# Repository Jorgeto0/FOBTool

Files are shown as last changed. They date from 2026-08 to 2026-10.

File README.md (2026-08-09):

# FOBtool Hardware

FOBtool Hardware is the KiCad source repository for the FOBtool handheld electronic platform. It contains the project-level schematic and PCB files, custom symbols and footprints, and supporting documentation used to develop and maintain the hardware design.

## Project contents

| Path | Purpose |
| --- | --- |
| `FOBtool_HW.kicad_pro` | Main KiCad project file. Open this file to work with the design. |
| `FOBtool_HW.kicad_sch` | Top-level hierarchical schematic. |
| `POWER.kicad_sch` | Battery, charging, power-path, monitoring, and regulated-supply circuitry. |
| `MAIN_CONTROLLER_sch.kicad_sch` | ESP32-S3 main-controller circuitry and system control interfaces. |
| `FOBtool_HW.kicad_pcb` | PCB layout file. |
| `Custom_Components/` | Project-specific symbol and footprint resources. |
| `docs/` | Short descriptions of the project and schematic sheets. |

## Opening the design

1. Install [KiCad](https://www.kicad.org/) 10.x or a compatible later version.
2. Clone or download the complete repository so the project files and custom libraries remain together.
3. Open `FOBtool_HW.kicad_pro` from KiCad's Project Manager.
4. Confirm that the project symbol and footprint libraries load without errors before editing the design.

Open the project file rather than an individual child sheet so KiCad retains the full hierarchy and project library configuration.

## Schematic documentation

See the [documentation index](docs/README.md) for the purpose of each schematic sheet currently included in the project.

## Repository use

This repository contains active engineering source files. Design files may change as schematic capture, verification, PCB layout, and manufacturing preparation progress. Manufacturing outputs should be issued separately as a controlled release.

## Confidentiality

This project contains proprietary client hardware information. Keep the repository private and share its contents only with authorized project participants.

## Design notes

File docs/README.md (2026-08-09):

# Hardware Documentation

This directory provides a concise description of the purpose of each schematic sheet in the FOBtool Hardware project.

| Schematic sheet | Purpose |
| --- | --- |
| [Power](POWER.md) | Manages the battery and external power inputs, charging, power monitoring, and the regulated supply rails used by the system. |
| [Main Controller](MAIN_CONTROLLER.md) | Contains the ESP32-S3 main controller, its essential support circuitry, and the control and communication interfaces to the other hardware subsystems. |

The complete schematic hierarchy is opened through [`FOBtool_HW.kicad_pro`](../FOBtool_HW.kicad_pro).

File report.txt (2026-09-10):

Info: Processing symbol 'FL10:Filter:Filter_SAW_Epcos_DCC6C_3x3mm'.
Info: Processing symbol 'FL11:Filter:Filter_SAW_Epcos_DCC6C_3x3mm'.
Info: Processing symbol 'AE2:FOBtool_Custom:Antenna_Taoglas_UWA01_3.2x1.6mm'.
Info: Processing symbol 'FL12:Filter:Filter_SAW_Epcos_DCC6C_3x3mm'.
Info: Processing symbol 'BZ1:Buzzer_Beeper:Buzzer_Mallory_AST1109MLTRQ'.
Info: Processing symbol 'J1:Connector_JST:JST_PH_S3B-PH-SM4-TB_1x03-1MP_P2.00mm_Horizontal'.
Info: Processing symbol 'C2:Capacitor_SMD:C_1206_3216Metric'.
Info: Processing symbol 'J2:Connector_PinHeader_1.27mm:PinHeader_1x05_P1.27mm_Vertical'.
Info: Processing symbol 'C4:Capacitor_SMD:C_1206_3216Metric'.
Info: Processing symbol 'J3:Connector_Coaxial:SMA_Amphenol_132289_EdgeMount'.
Info: Processing symbol 'C6:Capacitor_SMD:C_0805_2012Metric'.
Info: Processing symbol 'J4:Connector_Coaxial:SMA_Amphenol_132289_EdgeMount'.
Info: Processing symbol 'C8:Capacitor_SMD:C_1210_3225Metric'.
Info: Processing symbol 'J5:Connector_Coaxial:SMA_Amphenol_132289_EdgeMount'.
Info: Processing symbol 'C10:Capacitor_SMD:C_1210_3225Metric'.
Info: Processing symbol 'J6:Connector_Coaxial:SMA_Amphenol_132289_EdgeMount'.
Info: Processing symbol 'C12:Capacitor_SMD:C_1206_3216Metric'.
Info: Processing symbol 'J7:USB4085:GCT_USB4085-GF-A_REVA4'.
Info: Processing symbol 'R43:Resistor_SMD:R_0603_1608Metric'.
Info: Processing symbol 'L19:Inductor_SMD:L_0402_1005Metric'.
Info: Processing symbol 'C207:Capacitor_SMD:C_0603_1608Metric'.
Info: Processing symbol 'R108:Resistor_SMD:R_0603_1608Metric'.
Info: Processing symbol 'Y9:CSCT:OSC_CSTCR4M00G55B-R0'.
Info: Processing symbol 'C174:Capacitor_SMD:C_0603_1608Metric'.
Info: Processing symbol 'R11:Resistor_SMD:R_0603_1608Metric'.
Info: Processing symbol 'C110:Capacitor_SMD:C_0402_1005Metric'.
Info: Processing symbol 'R76:Resistor_SMD:R_0603_1608Metric'.
Info: Processing symbol 'C239:Capacitor_SMD:C_0603_1608Metric'.
Info: Processing symbol 'R140:Resistor_SMD:R_0603_1608Metric'.
Info: Processing symbol 'U27:Package_TO_SOT_SMD:SOT-23-6'.
Info: Processing symbol 'C13:Capacitor_SMD:C_0603_1608Metric'.
Info: Processing symbol 'L3:Inductor_SMD:L_Wuerth_HCI-5040'.
Info: Processing symbol 'C94:Capacitor_SMD:C_0402_1005Metric'.
Info: Processing symbol 'L35:Inductor_SMD:L_0603_1608Metric'.
Info: Processing symbol 'C191:Capacitor_SMD:C_0402_1005Metric'.
Info: Processing symbol 'R27:Resistor_SMD:R_0603_1608Metric'.
Info: Processing symbol 'C62:Capacitor_SMD:C_0402_1005Metric'.
Info: Processing symbol 'R60:Resistor_SMD:R_0603_1608Metric'.
Info: Processing symbol 'C223:Capacitor_SMD:C_0603_1608Metric'.
Info: Processing symbol 'R92:Resistor_SMD:R_0603_1608Metric'.
Info: Processing symbol 'C126:Capacitor_SMD:C_0402_1005Metric'.
Info: Processing symbol 'R124:Resistor_SMD:R_0805_2012Metric'.
Info: Processing symbol 'C255:Capacitor_SMD:C_0603_1608Metric'.
Info: Processing symbol 'R156:Resistor_SMD:R_0603_1608Metric'.
Info: Processing symbol 'U10:Package_LGA:Infineon_PG-TSNP-6-10_0.7x1.1mm_0.7x1.1mm_P0.4mm'.
Info: Processing symbol 'FB6:Inductor_SMD:L_0402_1005Metric'.
Info: Processing symbol 'U43:Package_SO:SOIC-8_3.9x4.9mm_P1.27mm'.
Info: Processing symbol 'C158:Capacitor_SMD:C_0603_1608Metric'.
Info: Processing symbol 'J14:'.
Info: Processing symbol 'C166:Capacitor_SMD:C_0603_1608Metric'.
Info: Processing symbol 'L11:Inductor_SMD:L_0402_1005Metric'.
Info: Processing symbol 'C54:Capacitor_SMD:C_0402_1005Metric'.
Info: Processing symbol 'L27:Inductor_SMD:L_0603_1608Metric'.
Info: Processing symbol 'C183:Capacitor_SMD:C_0402_1005Metric'.
Info: Processing symbol 'R3:Resistor_SMD:R_0603_1608Metric'.
Info: Processing symbol 'C102:Capacitor_SMD:C_0805_2012Metric'.
Info: Processing symbol 'R19:Resistor_SMD:R_0603_1608Metric'.
Info: Processing symbol 'C199:Capacitor_SMD:C_0402_1005Metric'.
Info: Processing symbol 'R35:Resistor_SMD:R_0603_1608Metric'.
Info: Processing symbol 'C38:Capacitor_SMD:C_0402_1005Metric'.
Info: Processing symbol 'R51:Resistor_SMD:R_0805_2012Metric'.
Info: Processing symbol 'C215:Capacitor_SMD:C_0603_1608Metric'.
Info: Processing symbol 'R68:Resistor_SMD:R_0603_1608Metric'.
Info: Processing symbol 'C118:Capacitor_SMD:C_0402_1005Metric'.
Info: Processing symbol 'R84:Resistor_SMD:R_0603_1608Metric'.
Info: Processing symbol 'C231:Capacitor_SMD:C_0805_2012Metric'.
Info: Processing symbol 'R100:Resistor_SMD:R_0603_1608Metric'.
Info: Processing symbol 'C70:Capacitor_SMD:C_0402_1005Metric'.
Info: Processing symbol 'R116:Resistor_SMD:R_0603_1608Metric'.
Info: Processing symbol 'C247:Capacitor_SMD:C_0603_1608Metric'.
Info: Processing symbol 'R132:Resistor_SMD:R_0805_2012Metric'.
Info: Processing symbol 'C135:Capacitor_SMD:C_0402_1005Metric'.
Info: Processing symbol 'R148:Resistor_SMD:R_0603_1608Metric'.
Info: Processing symbol 'D1:Diode_SMD:Nexperia_DSN0603-2_0.6x0.3mm_P0.4mm'.
Info: Processing symbol 'SW6:Button_Switch_SMD:SW_SPST_PTS810'.
Info: Processing symbol 'U2:Package_DFN_QFN:QFN-60-1EP_7x7mm_P0.4mm_EP3.4x3.4mm'.
Info: Processing symbol 'D17:Diode_SMD:Nexperia_DSN0603-2_0.6x0.3mm_P0.4mm'.
Info: Processing symbol 'U18:FOBtool_Custom:Infineon_PG-TSNP-8-1_1.1x1.1mm_P0.4mm'.
Info: Processing symbol 'C150:Capacitor_SMD:C_0603_1608Metric'.
Info: Processing symbol 'U35:Package_DFN_QFN:QFN-40-1EP_5x5mm_P0.4mm_EP3.6x3.6mm'.
Info: Processing symbol 'AE1:FOBtool_Custom:Antenna_Taoglas_UWA01_3.2x1.6mm'.
Info: Processing symbol 'Y1:Crystal:Crystal_SMD_3225-4Pin_3.2x2.5mm'.
Info: Processing symbol 'C86:Capacitor_SMD:C_0402_1005Metric'.
Info: Processing symbol 'J10:Connector_FFC-FPC:Hirose_FH12-12S-0.5SH_1x12-1MP_P0.50mm_Horizontal'.
Info: Processing symbol 'C88:Capacitor_SMD:C_0402_1005Metric'.
Info: Processing symbol 'J17:Connector_Coaxial:SMA_Amphenol_132289_EdgeMount'.
Info: Processing symbol 'C90:Capacitor_SMD:C_0402_1005Metric'.
Info: Processing symbol 'L7:Inductor_SMD:L_0402_1005Metric'.
Info: Processing symbol 'C170:Capacitor_SMD:C_0805_2012Metric'.
Info: Processing symbol 'L15:Inductor_SMD:L_0402_1005Metric'.
Info: Processing symbol 'C34:Capacitor_SMD:C_0402_1005Metric'.
Info: Processing symbol 'L23:Inductor_SMD:L_0402_1005Metric'.
Info: Processing symbol 'C179:FOBtool_Custom:CP_Seiko_CPH3225A_3.2x2.5mm'.
Info: Processing symbol 'L31:Inductor_SMD:L_0603_1608Metric'.
Info: Processing symbol 'C98:Capacitor_SMD:C_0402_1005Metric'.
Info: Processing symbol 'Q2:Package_TO_SOT_SMD:SOT-23'.
Info: Processing symbol 'C187:Capacitor_SMD:C_0402_1005Metric'.
Info: Processing symbol 'R7:Resistor_SMD:R_0603_1608Metric'.
Info: Processing symbol 'C58:Capacitor_SMD:C_0603_1608Metric'.
Info: Processing symbol 'R15:Resistor_SMD:R_0603_1608Metric'.
Info: Processing symbol 'C195:Capacitor_SMD:C_0402_1005Metric'.
Info: Processing symbol 'R23:Resistor_SMD:R_0603_1608Metric'.
Info: Processing symbol 'C106:Capacitor_SMD:C_0402_1005Metric'.
Info: Processing symbol 'R31:Resistor_SMD:R_0603_1608Metric'.
Info: Processing symbol 'C203:Capacitor_SMD:C_0402_1005Metric'.
Info: Processing symbol 'R39:Resistor_SMD:R_0603_1608Metric'.
Info: Processing symbol 'C26:Capacitor_SMD:C_0603_1608Metric'.
Info: Processing symbol 'R47:Resistor_SMD:R_0402_1005Metric'.
Info: Processing symbol 'C211:Capacitor_SMD:C_1206_3216Metric'.
Info: Processing symbol 'R56:Resistor_SMD:R_0603_1608Metric'.
Info: Processing symbol 'C114:Capacitor_SMD:C_0402_1005Metric'.
Info: Processing symbol 'R64:Resistor_SMD:R_0603_1608Metric'.
Info: Processing symbol 'C219:Capacitor_SMD:C_0603_1608Metric'.
Info: Processing symbol 'R72:Resistor_SMD:R_0603_1608Metric'.
Info: Processing symbol 'C66:Capacitor_SMD:C_0402_1005Metric'.
Info: Processing symbol 'R80:Resistor_SMD:R_0603_1608Metric'.
Info: Processing symbol 'C227:Capacitor_SMD:C_0603_1608Metric'.
Info: Processing symbol 'R88:Resistor_SMD:R_0603_1608Metric'.
Info: Processing symbol 'C122:Capacitor_SMD:C_0402_1005Metric'.
Info: Processing symbol 'R96:Resistor_SMD:R_0603_1608Metric'.
Info: Processing symbol 'C235:Capacitor_SMD:C_0603_1608Metric'.
Info: Processing symbol 'R104:Resistor_SMD:R_0603_1608Metric'.
Info: Processing symbol 'C42:Capacitor_SMD:C_0402_1005Metric'.
Info: Processing symbol 'R112:Resistor_SMD:R_0603_1608Metric'.
Info: Processing symbol 'C243:Capacitor_SMD:C_0603_1608Metric'.
Info: Processing symbol 'R120:Resistor_SMD:R_0603_1608Metric'.
Info: Processing symbol 'C130:Capacitor_SMD:C_0402_1005Metric'.
Info: Processing symbol 'R128:Resistor_SMD:R_0603_1608Metric'.
Info: Processing symbol 'C251:Capacitor_SMD:C_0603_1608Metric'.
Info: Processing symbol 'R136:Resistor_SMD:R_0805_2012Metric'.
Info: Processing symbol 'C74:Capacitor_SMD:C_0402_1005Metric'.
Info: Processing symbol 'R144:Resistor_SMD:R_0603_1608Metric'.
Info: Processing symbol 'C259:Capacitor_SMD:C_0603_1608Metric'.
Info: Processing symbol 'R152:Resistor_SMD:R_0603_1608Metric'.
Info: Processing symbol 'C139:Capacitor_SMD:C_0402_1005Metric'.
Info: Processing symbol 'SW2:Button_Switch_SMD:SW_SPST_PTS810'.
Info: Processing symbol 'D5:Package_SON:Texas_DPY0002A_0.6x1mm_P0.65mm'.
Info: Processing symbol 'T2:BO310:XFMR_B0310J50100AHF'.
Info: Processing symbol 'TP7:TestPoint:TestPoint_Pad_D1.5mm'.
Info: Processing symbol 'D13:LED_SMD:LED_0603_1608Metric'.
Info: Processing symbol 'U6:Package_DFN_QFN:QFN-20-1EP_4x4mm_P0.5mm_EP2.6x2.6mm_ThermalVias'.
Info: Processing symbol 'C146:Capacitor_SMD:C_0402_1005Metric'.
Info: Processing symbol 'U14:TQP3M:SON50P200X200X95-9N'.
Info: Processing symbol 'FB2:Inductor_SMD:L_0402_1005Metric'.
Info: Processing symbol 'U22:TQP7M:QFN50P400X400X90-25N'.
Info: Processing symbol 'C82:Capacitor_SMD:C_0402_1005Metric'.
Info: Processing symbol 'U31:Package_LGA:Infineon_PG-TSNP-6-10_0.7x1.1mm_0.7x1.1mm_P0.4mm'.
Info: Processing symbol 'FL4:Filter:Filter_SAW_Epcos_DCC6C_3x3mm'.
Info: Processing symbol 'U39:Package_SO:TSSOP-16_4.4x5mm_P0.65mm'.
Info: Processing symbol 'C154:Capacitor_SMD:C_0603_1608Metric'.
Info: Processing symbol 'U47:SN74:SOP65P640X120-14N'.
Info: Processing symbol 'C5:Capacitor_SMD:C_1206_3216Metric'.
Info: Processing symbol 'Y5:Crystal:Crystal_SMD_3215-2Pin_3.2x1.5mm'.
Info: Processing symbol 'C50:Capacitor_SMD:C_0402_1005Metric'.
Info: Processing symbol 'J8:Connector_USB:USB_A_Molex_67643_Horizontal'.
Info: Processing symbol 'C160:Capacitor_SMD:C_0603_1608Metric'.
Info: Processing symbol 'J12:Connector_Card:microSD_HC_Molex_104031-0811'.
Info: Processing symbol 'C51:Capacitor_SMD:C_0402_1005Metric'.
Info: Processing symbol 'J15:Connector_JST:JST_PH_S2B-PH-SM4-TB_1x02-1MP_P2.00mm_Horizontal'.
Info: Processing symbol 'C164:Capacitor_SMD:C_0603_1608Metric'.
Info: Processing symbol 'L1:Inductor_SMD:L_Wuerth_MAPI-4020'.
Info: Processing symbol 'C52:Capacitor_SMD:C_0402_1005Metric'.
Info: Processing symbol 'L5:Inductor_SMD:L_0402_1005Metric'.
Info: Processing symbol 'C168:Capacitor_SMD:C_0603_1608Metric'.
Info: Processing symbol 'L9:Inductor_SMD:L_0402_1005Metric'.
Info: Processing symbol 'C92:Capacitor_SMD:C_0402_1005Metric'.
Info: Processing symbol 'L13:Inductor_SMD:L_0402_1005Metric'.
Info: Processing symbol 'C172:Capacitor_SMD:C_0805_2012Metric'.
Info: Processing symbol 'L17:Inductor_SMD:L_0402_1005Metric'.
Info: Processing symbol 'C24:Capacitor_SMD:C_1206_3216Metric'.
Info: Processing symbol 'L21:FOBtool_Custom:L_Murata_LQH44PN_4.0x4.0mm'.
Info: Processing symbol 'C177:Capacitor_SMD:C_0603_1608Metric'.
Info: Processing symbol 'L25:Inductor_SMD:L_0603_1608Metric'.
Info: Processing symbol 'C96:Capacitor_SMD:C_0402_1005Metric'.
Info: Processing symbol 'L29:Inductor_SMD:L_0603_1608Metric'.
Info: Processing symbol 'C181:Capacitor_SMD:C_0603_1608Metric'.
Info: Processing symbol 'L33:Inductor_SMD:L_0402_1005Metric'.
Info: Processing symbol 'C56:Capacitor_SMD:C_0402_1005Metric'.
Info: Processing symbol 'NT1:FOBtool_Custom:NetTie_2_SMD_3.0mm_Current'.
Info: Processing symbol 'C185:Capacitor_SMD:C_0402_1005Metric'.
Info: Processing symbol 'R1:Resistor_SMD:R_0603_1608Metric'.
Info: Processing symbol 'C100:Capacitor_SMD:C_0603_1608Metric'.
Info: Processing symbol 'R5:Resistor_SMD:R_0603_1608Metric'.
Info: Processing symbol 'C189:Capacitor_SMD:C_0805_2012Metric'.
Info: Processing symbol 'R9:Resistor_SMD:R_0603_1608Metric'.
Info: Processing symbol 'C36:Capacitor_SMD:C_0402_1005Metric'.
Info: Processing symbol 'R13:Resistor_SMD:R_0603_1608Metric'.
Info: Processing symbol 'C193:Capacitor_SMD:C_1206_3216Metric'.
Info: Processing symbol 'R17:Resistor_SMD:R_0603_1608Metric'.
Info: Processing symbol 'C104:Capacitor_SMD:C_0402_1005Metric'.
Info: Processing symbol 'R21:Resistor_SMD:R_0603_1608Metric'.
Info: Processing symbol 'C197:Capacitor_SMD:C_0402_1005Metric'.
Info: Processing symbol 'R25:Resistor_SMD:R_0603_1608Metric'.
Info: Processing symbol 'C60:FOBtool_Custom:CP_Panasonic_EEF-LR_7.3x4.3mm_3Terminal'.
Info: Processing symbol 'R29:Resistor_SMD:R_0603_1608Metric'.
Info: Processing symbol 'C201:Capacitor_SMD:C_0402_1005Metric'.
Info: Processing symbol 'R33:Resistor_SMD:R_0603_1608Metric'.
Info: Processing symbol 'C108:Capacitor_SMD:C_0402_1005Metric'.
Info: Processing symbol 'R37:Resistor_SMD:R_0603_1608Metric'.
Info: Processing symbol 'C205:Capacitor_SMD:C_0603_1608Metric'.
Info: Processing symbol 'R41:Resistor_SMD:R_0603_1608Metric'.
Info: Processing symbol 'C20:Capacitor_SMD:C_1206_3216Metric'.
Info: Processing symbol 'R45:Resistor_SMD:R_0603_1608Metric'.
Info: Processing symbol 'C209:Capacitor_SMD:C_0603_1608Metric'.
Info: Processing symbol 'R49:Resistor_SMD:R_0603_1608Metric'.
Info: Processing symbol 'C112:Capacitor_SMD:C_0402_1005Metric'.
Info: Processing symbol 'R54:Resistor_SMD:R_0603_1608Metric'.
Info: Processing symbol 'C213:Capacitor_SMD:C_0603_1608Metric'.
Info: Processing symbol 'R58:Resistor_SMD:R_0603_1608Metric'.
Info: Processing symbol 'C64:Capacitor_SMD:C_0402_1005Metric'.
Info: Processing symbol 'R62:Resistor_SMD:R_0603_1608Metric'.
Info: Processing symbol 'C217:Capacitor_SMD:C_0603_1608Metric'.
Info: Processing symbol 'R66:Resistor_SMD:R_0603_1608Metric'.
Info: Processing symbol 'C116:Capacitor_SMD:C_0402_1005Metric'.
Info: Processing symbol 'R70:Resistor_SMD:R_0603_1608Metric'.
Info: Processing symbol 'C221:Capacitor_SMD:C_1206_3216Metric'.
Info: Processing symbol 'R74:Resistor_SMD:R_0603_1608Metric'.
Info: Processing symbol 'C40:Capacitor_SMD:C_0805_2012Metric'.
Info: Processing symbol 'R78:Resistor_SMD:R_0603_1608Metric'.
Info: Processing symbol 'C225:Capacitor_SMD:C_0603_1608Metric'.
Info: Processing symbol 'R82:Resistor_SMD:R_0603_1608Metric'.
Info: Processing symbol 'C120:Capacitor_SMD:C_0402_1005Metric'.
Info: Processing symbol 'R86:Resistor_SMD:R_0603_1608Metric'.
Info: Processing symbol 'C229:Capacitor_SMD:C_0603_1608Metric'.
Info: Processing symbol 'R90:Resistor_SMD:R_0603_1608Metric'.
Info: Processing symbol 'C68:Capacitor_SMD:C_0402_1005Metric'.
Info: Processing symbol 'R94:Resistor_SMD:R_0603_1608Metric'.
Info: Processing symbol 'C233:Capacitor_SMD:C_0603_1608Metric'.
Info: Processing symbol 'R98:Resistor_SMD:R_0603_1608Metric'.
Info: Processing symbol 'C124:Capacitor_SMD:C_0603_1608Metric'.
Info: Processing symbol 'R102:Resistor_SMD:R_0603_1608Metric'.
Info: Processing symbol 'C237:Capacitor_SMD:C_0603_1608Metric'.
Info: Processing symbol 'R106:Resistor_SMD:R_0603_1608Metric'.
Info: Processing symbol 'C28:Capacitor_SMD:C_0402_1005Metric'.
Info: Processing symbol 'R110:Resistor_SMD:R_0603_1608Metric'.
Info: Processing symbol 'C241:Capacitor_SMD:C_0603_1608Metric'.
Info: Processing symbol 'R114:Resistor_SMD:R_0603_1608Metric'.
Info: Processing symbol 'C128:Capacitor_SMD:C_0402_1005Metric'.
Info: Processing symbol 'R118:Resistor_SMD:R_0603_1608Metric'.
Info: Processing symbol 'C245:Capacitor_SMD:C_0603_1608Metric'.
Info: Processing symbol 'R122:Resistor_SMD:R_0603_1608Metric'.
Info: Processing symbol 'C72:Capacitor_SMD:C_0402_1005Metric'.
Info: Processing symbol 'R126:Resistor_SMD:R_0603_1608Metric'.
Info: Processing symbol 'C249:Capacitor_SMD:C_0603_1608Metric'.
Info: Processing symbol 'R130:Resistor_SMD:R_0603_1608Metric'.
Info: Processing symbol 'C132:Capacitor_SMD:C_0603_1608Metric'.
Info: Processing symbol 'R134:Resistor_SMD:R_0603_1608Metric'.
Info: Processing symbol 'C253:Capacitor_SMD:C_0603_1608Metric'.
Info: Processing symbol 'R138:Resistor_SMD:R_0603_1608Metric'.
Info: Processing symbol 'C44:Capacitor_SMD:C_0402_1005Metric'.
Info: Processing symbol 'R142:Resistor_SMD:R_0201_0603Metric'.
Info: Processing symbol 'C257:Capacitor_SMD:C_0402_1005Metric'.
Info: Processing symbol 'R146:Resistor_SMD:R_0603_1608Metric'.
Info: Processing symbol 'C137:Capacitor_SMD:C_0402_1005Metric'.
Info: Processing symbol 'R150:Resistor_SMD:R_0603_1608Metric'.
Info: Processing symbol 'C261:Capacitor_SMD:C_1206_3216Metric'.
Info: Processing symbol 'R154:Resistor_SMD:R_0603_1608Metric'.
Info: Processing symbol 'C76:Capacitor_SMD:C_0402_1005Metric'.
Info: Processing symbol 'R158:Resistor_SMD:R_0603_1608Metric'.
Info: Processing symbol 'D3:Diode_SMD:Nexperia_DSN0603-2_0.6x0.3mm_P0.4mm'.
Info: Processing symbol 'SW4:Button_Switch_SMD:SW_SPST_PTS810'.
Info: Processing symbol 'C141:Capacitor_SMD:C_0402_1005Metric'.
Info: Processing symbol 'SW8:Button_Switch_SMD:SW_SPST_PTS810'.
Info: Processing symbol 'D7:LED_SMD:LED_0603_1608Metric'.
Info: Processing symbol 'TP1:TestPoint:TestPoint_Pad_D1.5mm'.
Info: Processing symbol 'TP5:TestPoint:TestPoint_Pad_D1.5mm'.
Info: Processing symbol 'D11:LED_SMD:LED_0603_1608Metric'.
Info: Processing symbol 'TP9:TestPoint:TestPoint_Pad_D1.5mm'.
Info: Processing symbol 'C79:Capacitor_SMD:C_0603_1608Metric'.
Info: Processing symbol 'U4:CC1101:QFN50P400X400X100-21N'.
Info: Processing symbol 'D15:FOBtool_Custom:D_Semtech_RCLAMP2451ZA_DFN0603_2'.
Info: Processing symbol 'U8:FOBtool_Custom:Infineon_PG-TSNP-8-1_1.1x1.1mm_P0.4mm'.
Info: Processing symbol 'C80:Capacitor_SMD:C_0402_1005Metric'.
Info: Processing symbol 'U12:Package_LGA:Infineon_PG-TSNP-6-10_0.7x1.1mm_0.7x1.1mm_P0.4mm'.
Info: Processing symbol 'D19:Diode_SMD:Nexperia_DSN0603-2_0.6x0.3mm_P0.4mm'.
Info: Processing symbol 'U16:Package_SO:TSSOP-24_4.4x7.8mm_P0.65mm'.
Info: Processing symbol 'C148:Capacitor_SMD:C_0402_1005Metric'.
Info: Processing symbol 'U20:FOBtool_Custom:Infineon_PG-TSNP-8-1_1.1x1.1mm_P0.4mm'.
Info: Processing symbol 'FB4:Inductor_SMD:L_0402_1005Metric'.
Info: Processing symbol 'U25:TPS2553:SOT95P280X145-6N'.
Info: Processing symbol 'C48:Capacitor_SMD:C_0402_1005Metric'.
Info: Processing symbol 'U29:Package_LGA:Infineon_PG-TSNP-6-10_0.7x1.1mm_0.7x1.1mm_P0.4mm'.
Info: Processing symbol 'FL2:Filter:Filter_SAW_Epcos_DCC6C_3x3mm'.
Info: Processing symbol 'U33:Package_DFN_QFN:QFN-24-1EP_4x4mm_P0.5mm_EP2.6x2.6mm'.
Info: Processing symbol 'C152:Capacitor_SMD:C_0603_1608Metric'.
Info: Processing symbol 'U37:Package_TO_SOT_SMD:SOT-23-5'.
Info: Processing symbol 'FL8:Filter:Filter_SAW_Epcos_DCC6C_3x3mm'.
Info: Processing symbol 'U41:FOBtool_Custom:ublox_MAX-M10N'.
Info: Processing symbol 'C84:Capacitor_SMD:C_0402_1005Metric'.
Info: Processing symbol 'U45:Package_SO:SOIC-16_3.9x9.9mm_P1.27mm'.
Info: Processing symbol 'C1:Capacitor_SMD:C_0603_1608Metric'.
Info: Processing symbol 'U49:Package_DFN_QFN:Texas_RWU0007A_VQFN-7_2x2mm_P0.5mm'.
Info: Processing symbol 'C156:Capacitor_SMD:C_0603_1608Metric'.
Info: Processing symbol 'Y3:Crystal:Crystal_SMD_3225-4Pin_3.2x2.5mm'.
Info: Processing symbol 'C9:Capacitor_SMD:C_1210_3225Metric'.
Info: Processing symbol 'Y7:Crystal:Crystal_SMD_2016-4Pin_2.0x1.6mm'.
Info: Processing symbol 'C23:Capacitor_SMD:C_0603_1608Metric'.
Info: Processing symbol 'C14:Capacitor_SMD:C_0603_1608Metric'.
Info: Processing symbol 'C159:Capacitor_SMD:C_0603_1608Metric'.
Info: Processing symbol 'J9:Connector_JST:JST_GH_SM04B-GHS-TB_1x04-1MP_P1.25mm_Horizontal'.
Info: Processing symbol 'C87:Capacitor_SMD:C_0402_1005Metric'.
Info: Processing symbol 'J11:Connector_JST:JST_GH_SM02B-GHS-TB_1x02-1MP_P1.25mm_Horizontal'.
Info: Processing symbol 'C161:Capacitor_SMD:C_0603_1608Metric'.
Info: Processing symbol 'J13:Connector_Coaxial:U.FL_Hirose_U.FL-R-SMT-1_Vertical'.
Info: Processing symbol 'C32:Capacitor_SMD:C_0603_1608Metric'.
Info: Processing symbol 'C162:Capacitor_SMD:C_0603_1608Metric'.
Info: Processing symbol 'C163:Capacitor_SMD:C_0603_1608Metric'.
Info: Processing symbol 'J16:Connector_JST:JST_PH_S2B-PH-SM4-TB_1x02-1MP_P2.00mm_Horizontal'.
Info: Processing symbol 'C89:Capacitor_SMD:C_0402_1005Metric'.
Info: Processing symbol 'J18:Connector_Coaxial:SMA_Amphenol_132289_EdgeMount'.
Info: Processing symbol 'C165:Capacitor_SMD:C_0603_1608Metric'.
Info: Processing symbol 'L2:Inductor_SMD:L_Wuerth_MAPI-4020'.
Info: Processing symbol 'C33:Capacitor_SMD:C_0402_1005Metric'.
Info: Processing symbol 'L4:FOBtool_Custom:L_Abracon_AOTA-B201610S_2.0x1.6mm'.
Info: Processing symbol 'C167:Capacitor_SMD:C_0603_1608Metric'.
Info: Processing symbol 'L6:Inductor_SMD:L_0402_1005Metric'.
Info: Processing symbol 'C91:Capacitor_SMD:C_0402_1005Metric'.
Info: Processing symbol 'L8:Inductor_SMD:L_0402_1005Metric'.
Info: Processing symbol 'C169:Capacitor_SMD:C_0603_1608Metric'.
Info: Processing symbol 'L10:Inductor_SMD:L_0402_1005Metric'.
Info: Processing symbol 'C53:Capacitor_SMD:C_0402_1005Metric'.
Info: Processing symbol 'L12:Inductor_SMD:L_0402_1005Metric'.
Info: Processing symbol 'C171:Capacitor_SMD:C_0603_1608Metric'.
Info: Processing symbol 'L14:Inductor_SMD:L_0402_1005Metric'.
Info: Processing symbol 'C93:Capacitor_SMD:C_0402_1005Metric'.
Info: Processing symbol 'L16:Inductor_SMD:L_0402_1005Metric'.
Info: Processing symbol 'C173:Capacitor_SMD:C_0603_1608Metric'.
Info: Processing symbol 'L18:Inductor_SMD:L_0402_1005Metric'.
Info: Processing symbol 'C19:Capacitor_SMD:C_1206_3216Metric'.
Info: Processing symbol 'L20:Inductor_SMD:L_0402_1005Metric'.
Info: Processing symbol 'C176:Capacitor_SMD:C_0603_1608Metric'.
Info: Processing symbol 'L22:Inductor_SMD:L_1008_2520Metric'.
Info: Processing symbol 'C95:Capacitor_SMD:C_0402_1005Metric'.
Info: Processing symbol 'L24:Inductor_SMD:L_0603_1608Metric'.
Info: Processing symbol 'C178:Capacitor_SMD:C_0603_1608Metric'.
Info: Processing symbol 'L26:Inductor_SMD:L_0603_1608Metric'.
Info: Processing symbol 'C55:Capacitor_SMD:C_0402_1005Metric'.
Info: Processing symbol 'L28:Inductor_SMD:L_0603_1608Metric'.
Info: Processing symbol 'C180:Capacitor_SMD:C_0603_1608Metric'.
Info: Processing symbol 'L30:Inductor_SMD:L_0603_1608Metric'.
Info: Processing symbol 'C97:Capacitor_SMD:C_0603_1608Metric'.
Info: Processing symbol 'L32:Inductor_SMD:L_0603_1608Metric'.
Info: Processing symbol 'C182:Capacitor_SMD:C_0603_1608Metric'.
Info: Processing symbol 'L34:Inductor_SMD:L_0603_1608Metric'.
Info: Processing symbol 'C35:Capacitor_SMD:C_0402_1005Metric'.
Info: Processing symbol 'L36:Inductor_SMD:L_0402_1005Metric'.
Info: Processing symbol 'C184:Capacitor_SMD:C_0402_1005Metric'.
Info: Processing symbol 'Q1:Package_TO_SOT_SMD:SOT-23'.
Info: Processing symbol 'C99:Capacitor_SMD:C_0402_1005Metric'.
Info: Processing symbol 'Q3:Package_TO_SOT_SMD:SOT-23'.
Info: Processing symbol 'C186:Capacitor_SMD:C_0805_2012Metric'.
Info: Processing symbol 'R2:Resistor_SMD:R_0603_1608Metric'.
Info: Processing symbol 'C57:Capacitor_SMD:C_0402_1005Metric'.
Info: Processing symbol 'R4:Resistor_SMD:R_0603_1608Metric'.
Info: Processing symbol 'C188:Capacitor_SMD:C_0402_1005Metric'.
Info: Processing symbol 'R6:Resistor_SMD:R_0603_1608Metric'.
Info: Processing symbol 'C101:Capacitor_SMD:C_0402_1005Metric'.
Info: Processing symbol 'R8:Resistor_SMD:R_0603_1608Metric'.
Info: Processing symbol 'C190:Capacitor_SMD:C_0805_2012Metric'.
Info: Processing symbol 'R10:Resistor_SMD:R_0603_1608Metric'.
Info: Processing symbol 'C25:Capacitor_SMD:C_0603_1608Metric'.
Info: Processing symbol 'R12:Resistor_SMD:R_0603_1608Metric'.
Info: Processing symbol 'C192:Capacitor_SMD:C_0402_1005Metric'.
Info: Processing symbol 'R14:Resistor_SMD:R_0603_1608Metric'.
Info: Processing symbol 'C103:Capacitor_SMD:C_0402_1005Metric'.
Info: Processing symbol 'R16:Resistor_SMD:R_0603_1608Metric'.
Info: Processing symbol 'C194:Capacitor_SMD:C_0402_1005Metric'.
Info: Processing symbol 'R18:Resistor_SMD:R_0603_1608Metric'.
Info: Processing symbol 'C59:Capacitor_SMD:C_0402_1005Metric'.
Info: Processing symbol 'R20:Resistor_SMD:R_0603_1608Metric'.
Info: Processing symbol 'C196:Capacitor_SMD:C_0402_1005Metric'.
Info: Processing symbol 'R22:Resistor_SMD:R_0603_1608Metric'.
Info: Processing symbol 'C105:Capacitor_SMD:C_0402_1005Metric'.
Info: Processing symbol 'R24:Resistor_SMD:R_0603_1608Metric'.
Info: Processing symbol 'C198:Capacitor_SMD:C_0402_1005Metric'.
Info: Processing symbol 'R26:Resistor_SMD:R_0603_1608Metric'.
Info: Processing symbol 'C37:Capacitor_SMD:C_0402_1005Metric'.
Info: Processing symbol 'R28:Resistor_SMD:R_0603_1608Metric'.
Info: Processing symbol 'C200:Capacitor_SMD:C_0402_1005Metric'.
Info: Processing symbol 'R30:Resistor_SMD:R_0603_1608Metric'.
Info: Processing symbol 'C107:Capacitor_SMD:C_0402_1005Metric'.
Info: Processing symbol 'R32:Resistor_SMD:R_0603_1608Metric'.
Info: Processing symbol 'C202:Capacitor_SMD:C_0402_1005Metric'.
Info: Processing symbol 'R34:Resistor_SMD:R_0603_1608Metric'.
Info: Processing symbol 'C61:Capacitor_SMD:C_0402_1005Metric'.
Info: Processing symbol 'R36:Resistor_SMD:R_0603_1608Metric'.
Info: Processing symbol 'C204:Capacitor_SMD:C_0805_2012Metric'.
Info: Processing symbol 'R38:Resistor_SMD:R_0603_1608Metric'.
Info: Processing symbol 'C109:Capacitor_SMD:C_0402_1005Metric'.
Info: Processing symbol 'R40:Resistor_SMD:R_0603_1608Metric'.
Info: Processing symbol 'C206:Capacitor_SMD:C_0603_1608Metric'.
Info: Processing symbol 'R42:Resistor_SMD:R_0603_1608Metric'.
Info: Processing symbol 'C17:Capacitor_SMD:C_0603_1608Metric'.
Info: Processing symbol 'R44:Resistor_SMD:R_0603_1608Metric'.
Info: Processing symbol 'C208:Capacitor_SMD:C_0603_1608Metric'.
Info: Processing symbol 'R46:Resistor_SMD:R_0402_1005Metric'.
Info: Processing symbol 'C111:Capacitor_SMD:C_0603_1608Metric'.
Info: Processing symbol 'R48:Resistor_SMD:R_0603_1608Metric'.
Info: Processing symbol 'C210:Capacitor_SMD:C_0603_1608Metric'.
Info: Processing symbol 'R50:Resistor_SMD:R_0603_1608Metric'.
Info: Processing symbol 'C63:Capacitor_SMD:C_0402_1005Metric'.
Info: Processing symbol 'R53:Resistor_SMD:R_0603_1608Metric'.
Info: Processing symbol 'C212:Capacitor_SMD:C_1206_3216Metric'.
Info: Processing symbol 'R55:Resistor_SMD:R_0603_1608Metric'.
Info: Processing symbol 'C113:Capacitor_SMD:C_0402_1005Metric'.
Info: Processing symbol 'R57:Resistor_SMD:R_0603_1608Metric'.
Info: Processing symbol 'C214:Capacitor_SMD:C_0603_1608Metric'.
Info: Processing symbol 'R59:Resistor_SMD:R_0603_1608Metric'.
Info: Processing symbol 'C39:Capacitor_SMD:C_0402_1005Metric'.
Info: Processing symbol 'R61:Resistor_SMD:R_0603_1608Metric'.
Info: Processing symbol 'C216:Capacitor_SMD:C_0603_1608Metric'.
Info: Processing symbol 'R63:Resistor_SMD:R_0603_1608Metric'.
Info: Processing symbol 'C115:Capacitor_SMD:C_0402_1005Metric'.
Info: Processing symbol 'R65:Resistor_SMD:R_0603_1608Metric'.
Info: Processing symbol 'C218:Capacitor_SMD:C_0603_1608Metric'.
Info: Processing symbol 'R67:Resistor_SMD:R_0603_1608Metric'.
Info: Processing symbol 'C65:Capacitor_SMD:C_0402_1005Metric'.
Info: Processing symbol 'R69:Resistor_SMD:R_0603_1608Metric'.
Info: Processing symbol 'C220:Capacitor_SMD:C_0603_1608Metric'.
Info: Processing symbol 'R71:Resistor_SMD:R_0603_1608Metric'.
Info: Processing symbol 'C117:Capacitor_SMD:C_0402_1005Metric'.
Info: Processing symbol 'R73:Resistor_SMD:R_0603_1608Metric'.
Info: Processing symbol 'C222:Capacitor_SMD:C_1206_3216Metric'.
Info: Processing symbol 'R75:Resistor_SMD:R_0603_1608Metric'.
Info: Processing symbol 'C27:Capacitor_SMD:C_0402_1005Metric'.
Info: Processing symbol 'R77:Resistor_SMD:R_0603_1608Metric'.
Info: Processing symbol 'C224:Capacitor_SMD:C_0603_1608Metric'.
Info: Processing symbol 'R79:Resistor_SMD:R_0603_1608Metric'.
Info: Processing symbol 'C119:Capacitor_SMD:C_0402_1005Metric'.
Info: Processing symbol 'R81:Resistor_SMD:R_0603_1608Metric'.
Info: Processing symbol 'C226:Capacitor_SMD:C_0603_1608Metric'.
Info: Processing symbol 'R83:Resistor_SMD:R_0603_1608Metric'.
Info: Processing symbol 'C67:Capacitor_SMD:C_0402_1005Metric'.
Info: Processing symbol 'R85:Resistor_SMD:R_0603_1608Metric'.
Info: Processing symbol 'C228:Capacitor_SMD:C_0603_1608Metric'.
Info: Processing symbol 'R87:Resistor_SMD:R_0603_1608Metric'.
Info: Processing symbol 'C121:Capacitor_SMD:C_0402_1005Metric'.
Info: Processing symbol 'R89:Resistor_SMD:R_0603_1608Metric'.
Info: Processing symbol 'C230:Capacitor_SMD:C_0603_1608Metric'.
Info: Processing symbol 'R91:Resistor_SMD:R_0603_1608Metric'.
Info: Processing symbol 'C41:Capacitor_SMD:C_0402_1005Metric'.
Info: Processing symbol 'R93:Resistor_SMD:R_0603_1608Metric'.
Info: Processing symbol 'C232:Capacitor_SMD:C_0603_1608Metric'.
Info: Processing symbol 'R95:Resistor_SMD:R_0603_1608Metric'.
Info: Processing symbol 'C123:Capacitor_SMD:C_0402_1005Metric'.
Info: Processing symbol 'R97:Resistor_SMD:R_0603_1608Metric'.
Info: Processing symbol 'C234:Capacitor_SMD:C_0603_1608Metric'.
Info: Processing symbol 'R99:Resistor_SMD:R_0603_1608Metric'.
Info: Processing symbol 'C69:Capacitor_SMD:C_0402_1005Metric'.
Info: Processing symbol 'R101:Resistor_SMD:R_0603_1608Metric'.
Info: Processing symbol 'C236:Capacitor_SMD:C_0603_1608Metric'.
Info: Processing symbol 'R103:Resistor_SMD:R_0603_1608Metric'.
Info: Processing symbol 'C125:Capacitor_SMD:C_0402_1005Metric'.
Info: Processing symbol 'R105:Resistor_SMD:R_1206_3216Metric'.
Info: Processing symbol 'C238:Capacitor_SMD:C_0805_2012Metric'.
Info: Processing symbol 'R107:Resistor_SMD:R_0603_1608Metric'.
Info: Processing symbol 'C21:Capacitor_SMD:C_1206_3216Metric'.
Info: Processing symbol 'R109:Resistor_SMD:R_0603_1608Metric'.
Info: Processing symbol 'C240:Capacitor_SMD:C_0603_1608Metric'.
Info: Processing symbol 'R111:Resistor_SMD:R_0603_1608Metric'.
Info: Processing symbol 'C127:Capacitor_SMD:C_0402_1005Metric'.
Info: Processing symbol 'R113:Resistor_SMD:R_0603_1608Metric'.
Info: Processing symbol 'C242:Capacitor_SMD:C_0603_1608Metric'.
Info: Processing symbol 'R115:Resistor_SMD:R_0603_1608Metric'.
Info: Processing symbol 'C71:Capacitor_SMD:C_0402_1005Metric'.
Info: Processing symbol 'R117:Resistor_SMD:R_0603_1608Metric'.
Info: Processing symbol 'C244:Capacitor_SMD:C_0603_1608Metric'.
Info: Processing symbol 'R119:Resistor_SMD:R_0603_1608Metric'.
Info: Processing symbol 'C129:Capacitor_SMD:C_0402_1005Metric'.
Info: Processing symbol 'R121:Resistor_SMD:R_0603_1608Metric'.
Info: Processing symbol 'C246:Capacitor_SMD:C_0603_1608Metric'.
Info: Processing symbol 'R123:Resistor_SMD:R_0603_1608Metric'.
Info: Processing symbol 'C43:Capacitor_SMD:C_0402_1005Metric'.
Info: Processing symbol 'R125:Resistor_SMD:R_0603_1608Metric'.
Info: Processing symbol 'C248:Capacitor_SMD:C_0603_1608Metric'.
Info: Processing symbol 'R127:Resistor_SMD:R_0805_2012Metric'.
Info: Processing symbol 'C131:Capacitor_SMD:C_0402_1005Metric'.
Info: Processing symbol 'R129:Resistor_SMD:R_0805_2012Metric'.
Info: Processing symbol 'C250:Capacitor_SMD:C_0603_1608Metric'.
Info: Processing symbol 'R131:Resistor_SMD:R_0603_1608Metric'.
Info: Processing symbol 'C73:Capacitor_SMD:C_0402_1005Metric'.
Info: Processing symbol 'R133:Resistor_SMD:R_0603_1608Metric'.
Info: Processing symbol 'C252:Capacitor_SMD:C_0603_1608Metric'.
Info: Processing symbol 'R135:Resistor_SMD:R_0805_2012Metric'.
Info: Processing symbol 'C134:Capacitor_SMD:C_0402_1005Metric'.
Info: Processing symbol 'R137:Resistor_SMD:R_0603_1608Metric'.
Info: Processing symbol 'C254:Capacitor_SMD:C_0603_1608Metric'.
Info: Processing symbol 'R139:Resistor_SMD:R_0603_1608Metric'.
Info: Processing symbol 'C29:Capacitor_SMD:C_0603_1608Metric'.
Info: Processing symbol 'R141:Resistor_SMD:R_0603_1608Metric'.
Info: Processing symbol 'C256:Capacitor_SMD:C_0603_1608Metric'.
Info: Processing symbol 'R143:Resistor_SMD:R_0201_0603Metric'.
Info: Processing symbol 'C136:Capacitor_SMD:C_0402_1005Metric'.
Info: Processing symbol 'R145:Resistor_SMD:R_0603_1608Metric'.
Info: Processing symbol 'C258:Capacitor_SMD:C_0402_1005Metric'.
Info: Processing symbol 'R147:Resistor_SMD:R_0603_1608Metric'.
Info: Processing symbol 'C75:Capacitor_SMD:C_0402_1005Metric'.
Info: Processing symbol 'R149:Resistor_SMD:R_0603_1608Metric'.
Info: Processing symbol 'C260:Capacitor_SMD:C_0603_1608Metric'.
Info: Processing symbol 'R151:Resistor_SMD:R_0603_1608Metric'.
Info: Processing symbol 'C138:Capacitor_SMD:C_0402_1005Metric'.
Info: Processing symbol 'R153:Resistor_SMD:R_0603_1608Metric'.
Info: Processing symbol 'C262:Capacitor_SMD:C_0603_1608Metric'.
Info: Processing symbol 'R155:Resistor_SMD:R_0603_1608Metric'.
Info: Processing symbol 'C45:Capacitor_SMD:C_0603_1608Metric'.
Info: Processing symbol 'R157:Resistor_SMD:R_0603_1608Metric'.
Info: Processing symbol 'D2:FOBtool_Custom:D_Semtech_RCLAMP2451ZA_DFN0603_2'.
Info: Processing symbol 'SW1:FOBtool_Custom:RotaryEncoder_Bourns_PEC11R-4215F-S0024'.
Info: Processing symbol 'C140:Capacitor_SMD:C_0402_1005Metric'.
Info: Processing symbol 'SW3:Button_Switch_SMD:SW_SPST_PTS810'.
Info: Processing symbol 'D4:Package_SON:Texas_DPY0002A_0.6x1mm_P0.65mm'.
Info: Processing symbol 'SW5:Button_Switch_SMD:SW_SPST_PTS810'.
Info: Processing symbol 'C77:Capacitor_SMD:C_0402_1005Metric'.
Info: Processing symbol 'SW7:Button_Switch_SMD:SW_SPST_PTS810'.
Info: Processing symbol 'D6:Package_TO_SOT_SMD:SOT-23'.
Info: Processing symbol 'T1:BO310:XFMR_B0310J50100AHF'.
Info: Processing symbol 'C142:Capacitor_SMD:C_0402_1005Metric'.
Info: Processing symbol 'T3:BO310:XFMR_B0310J50100AHF'.
Info: Processing symbol 'D8:LED_SMD:LED_WS2812B_PLCC4_5.0x5.0mm_P3.2mm'.
Info: Processing symbol 'TP2:TestPoint:TestPoint_Pad_D1.5mm'.
Info: Processing symbol 'TP4:TestPoint:TestPoint_Pad_D1.5mm'.
Info: Processing symbol 'D10:LED_SMD:LED_WS2812B_PLCC4_5.0x5.0mm_P3.2mm'.
Info: Processing symbol 'TP6:TestPoint:TestPoint_Pad_D1.5mm'.
Info: Processing symbol 'C144:Capacitor_SMD:C_0402_1005Metric'.
Info: Processing symbol 'TP8:TestPoint:TestPoint_Pad_D1.5mm'.
Info: Processing symbol 'D12:LED_SMD:LED_0603_1608Metric'.
Info: Processing symbol 'U1:RF_Module:ESP32-S3-WROOM-1'.
Info: Processing symbol 'C46:Capacitor_SMD:C_0402_1005Metric'.
Info: Processing symbol 'U3:CC1101:QFN50P400X400X100-21N'.
Info: Processing symbol 'D14:Diode_SMD:D_SOD-323'.
Info: Processing symbol 'U5:CC1101:QFN50P400X400X100-21N'.
Info: Processing symbol 'C145:Capacitor_SMD:C_0402_1005Metric'.
Info: Processing symbol 'U7:Package_LGA:Infineon_PG-TSNP-6-10_0.7x1.1mm_0.7x1.1mm_P0.4mm'.
Info: Processing symbol 'D16:Diode_SMD:Nexperia_DSN0603-2_0.6x0.3mm_P0.4mm'.
Info: Processing symbol 'U9:FOBtool_Custom:Infineon_PG-TSNP-8-1_1.1x1.1mm_P0.4mm'.
Info: Processing symbol 'C47:Capacitor_SMD:C_0402_1005Metric'.
Info: Processing symbol 'U11:MAX17048:SON50P200X200X80-9N'.
Info: Processing symbol 'D18:Diode_SMD:Nexperia_DSN0603-2_0.6x0.3mm_P0.4mm'.
Info: Processing symbol 'U13:Package_DFN_QFN:Texas_RTW_WQFN-24-1EP_4x4mm_P0.5mm_EP2.7x2.7mm_ThermalVias'.
Info: Processing symbol 'C147:Capacitor_SMD:C_0402_1005Metric'.
Info: Processing symbol 'U15:Package_DFN_QFN:QFN-12-1EP_3x3mm_P0.51mm_EP1.45x1.45mm'.
Info: Processing symbol 'FB1:Inductor_SMD:L_0402_1005Metric'.
Info: Processing symbol 'U17:TQP3M:SON50P200X200X95-9N'.
Info: Processing symbol 'C81:Capacitor_SMD:C_0402_1005Metric'.
Info: Processing symbol 'U19:FOBtool_Custom:Infineon_PG-TSNP-8-1_1.1x1.1mm_P0.4mm'.
Info: Processing symbol 'FB3:Inductor_SMD:L_0402_1005Metric'.
Info: Processing symbol 'U21:FOBtool_Custom:Infineon_PG-TSNP-8-1_1.1x1.1mm_P0.4mm'.
Info: Processing symbol 'C149:Capacitor_SMD:C_0402_1005Metric'.
Info: Processing symbol 'U23:LT3154AV:QFN50P300X300X83-17N'.
Info: Processing symbol 'FB5:Inductor_SMD:L_0402_1005Metric'.
Info: Processing symbol 'U26:Package_SO:SOIC-8_5.3x5.3mm_P1.27mm'.
Info: Processing symbol 'C31:Capacitor_SMD:C_0402_1005Metric'.
Info: Processing symbol 'U28:Package_LGA:Infineon_PG-TSNP-6-10_0.7x1.1mm_0.7x1.1mm_P0.4mm'.
Info: Processing symbol 'FB8:Inductor_SMD:L_0402_1005Metric'.
Info: Processing symbol 'U30:Package_LGA:Infineon_PG-TSNP-6-10_0.7x1.1mm_0.7x1.1mm_P0.4mm'.
Info: Processing symbol 'C151:Capacitor_SMD:C_0603_1608Metric'.
Info: Processing symbol 'U32:Package_TO_SOT_SMD:SOT-323_SC-70'.
Info: Processing symbol 'FL3:Filter:Filter_SAW_Epcos_DCC6C_3x3mm'.
Info: Processing symbol 'U34:Package_TO_SOT_SMD:SOT-323_SC-70'.
Info: Processing symbol 'C83:Capacitor_SMD:C_0402_1005Metric'.
Info: Processing symbol 'U36:Package_SO:SOIC-8_3.9x4.9mm_P1.27mm'.
Info: Processing symbol 'FL7:Filter:Filter_SAW_Epcos_DCC6C_3x3mm'.
Info: Processing symbol 'U38:Package_SO:TSSOP-10_3x3mm_P0.5mm'.
Info: Processing symbol 'C153:Capacitor_SMD:C_0603_1608Metric'.
Info: Processing symbol 'U40:Package_SO:SOIC-8_3.9x4.9mm_P1.27mm'.
Info: Processing symbol 'FL9:Filter:Filter_SAW_Epcos_DCC6C_3x3mm'.
Info: Processing symbol 'U42:OptoDevice:Lite-On_LTR-303ALS-01'.
Info: Processing symbol 'C49:Capacitor_SMD:C_0402_1005Metric'.
Info: Processing symbol 'U44:Package_DFN_QFN:HVQFN-40-1EP_6x6mm_P0.5mm_EP4.1x4.1mm_ThermalVias'.
Info: Processing symbol 'AE3:'.
Info: Processing symbol 'U46:Package_SO:SOIC-16_3.9x9.9mm_P1.27mm'.
Info: Processing symbol 'C155:Capacitor_SMD:C_0603_1608Metric'.
Info: Processing symbol 'U48:Package_SO:TSSOP-16_4.4x5mm_P0.65mm'.
Info: Processing symbol 'C3:Capacitor_SMD:C_0603_1608Metric'.
Info: Processing symbol 'U50:TPS2553:SOT95P280X145-6N'.
Info: Processing symbol 'C85:Capacitor_SMD:C_0402_1005Metric'.
Info: Processing symbol 'Y2:Crystal:Crystal_SMD_3225-4Pin_3.2x2.5mm'.
Info: Processing symbol 'C7:Capacitor_SMD:C_0805_2012Metric'.
Info: Processing symbol 'Y4:Crystal:Crystal_SMD_2016-4Pin_2.0x1.6mm'.
Info: Processing symbol 'C157:Capacitor_SMD:C_0805_2012Metric'.
Info: Processing symbol 'Y6:Crystal:Crystal_SMD_Abracon_ABM8G-4Pin_3.2x2.5mm'.
Info: Processing symbol 'C11:Capacitor_SMD:C_1206_3216Metric'.
Info: Processing symbol 'Y8:Crystal:Crystal_SMD_2016-4Pin_2.0x1.6mm'.
Info: Processing symbol 'C16:Capacitor_SMD:C_0603_1608Metric'.
Info: Processing symbol 'Y10:CSCT:OSC_CSTCR4M00G55B-R0'.
Info: Processing symbol 'C15:Capacitor_SMD:C_0603_1608Metric'.
Info: Processing symbol 'C18:FOBtool_Custom:CP_Panasonic_EEF-TX_7.3x4.3mm'.
Info: Processing symbol 'C22:Capacitor_SMD:C_0805_2012Metric'.
Info: Processing symbol 'C30:Capacitor_SMD:C_0402_1005Metric'.
Info: Processing symbol 'C78:Capacitor_SMD:C_0402_1005Metric'.
Info: Processing symbol 'C143:Capacitor_SMD:C_0603_1608Metric'.
Info: Processing symbol 'D9:LED_SMD:LED_WS2812B_PLCC4_5.0x5.0mm_P3.2mm'.
Info: Processing symbol 'TP3:TestPoint:TestPoint_Pad_D1.5mm'.
Error: Cannot add J14 (no footprint assigned).
Error: Cannot add AE3 (no footprint assigned).

Info: Total warnings: 0, errors: 2.

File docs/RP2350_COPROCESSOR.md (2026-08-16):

# Real-Time Co-Processor — `RP2350_COPROCESSOR.kicad_sch`

Raspberry Pi RP2350A and its complete support circuit. Handles every timing-critical task in
the product.

| | |
|---|---|
| **Sheet** | 4 of 10 |
| **Components** | 31 |
| **MCU** | Raspberry Pi RP2350A, QFN-60 |
| **Program flash** | 16 MB QSPI (W25Q128) |
| **Reference** | 12 MHz crystal |

---

## Why there is a second processor

The ESP32-S3 runs the application: display, menus, file system, and the shared SPI and I²C
buses. Its timing is good, but not exact.

Sub-GHz capture and replay is a timing problem rather than a data problem. A key fob transmits
an on/off keyed waveform in which the **width of each pulse** carries the information — replay
it with a few microseconds of jitter and the receiver rejects it. Interrupt latency on a
general-purpose MCU is enough to ruin that.

The RP2350's **PIO blocks** are deterministic state machines that run independently of the
CPU, one instruction per clock, with no interrupt latency. Each radio's demodulated bitstream
goes to a PIO state machine that timestamps every edge; another plays edges back out with the
same precision.

In short: the ESP32 owns the buses and the user interface, the RP2350 owns the microseconds.

---

## What it handles

| Function | Why it lives here |
|---|---|
| Radio edge capture (3 channels) | PIO timestamping — the reason for the chip |
| Replay output | PIO edge playback |
| CAN bus | software CAN implemented in PIO |
| NFC | dedicated SPI port, keeps NFC off the shared bus |
| LF 125 kHz coils | PWM coil drive plus demodulator capture |
| USB-A host | native USB controller |
| Link to ESP32 | UART plus a hardware sync line |

---

## Support circuit

- **Program flash** — external 16 MB QSPI device; the RP2350 has no internal flash.
- **Reference** — 12 MHz crystal with load capacitors and a series drive-limiting resistor,
  per Raspberry Pi's hardware design guidance.
- **Core supply** — the RP2350's on-chip regulator generates the 1.1 V core rail from 3.3 V
  through an external inductor, with its analog reference separately filtered.
- **Reset and boot** — RUN (reset) and BOOTSEL push-buttons, arranged so that entering boot
  mode does not disturb the flash chip-select.
- **Debug** — 5-pin header carrying SWCLK, SWDIO, RUN, 3.3 V and ground.
- **USB** — series-terminated data pair to the USB-A host receptacle.

---

## Interfaces

| Signal | Direction | Peer sheet |
|---|---|---|
| `LINK_ESP_TX` | in | MAIN_CONTROLLER |
| `LINK_ESP_RX` | out | MAIN_CONTROLLER |
| `LINK_SYNC` | bidirectional | MAIN_CONTROLLER |
| `CC1101_A/B/C_GDO0` | in | SUB_GHZ_RF |
| `REPLAY_OUT` | out | SUB_GHZ_RF |
| `USB_HOST_VBUS_EN` | out | POWER |
| `USB_HOST_FAULT_N` | in | POWER |
| `USB_HOST_D_P` / `USB_HOST_D_N` | bidirectional | WIRED_IO |
| `CAN_TX` / `CAN_RX` | out / in | WIRED_IO |
| `NFC_SCK` / `NFC_MOSI` / `nCS_NFC` | out | NEAR_FIELD |
| `NFC_MISO` / `NFC_IRQ` | in | NEAR_FIELD |
| `LF_COIL_A` / `LF_COIL_B` | out | NEAR_FIELD |
| `LF_DEMOD` | in | NEAR_FIELD |

> The link to the ESP32 is a **crossover**: signal names are from the ESP32's point of view,
> so `LINK_ESP_TX` lands on this device's UART receive pin and `LINK_ESP_RX` on its transmit
> pin. Link speed is 921600 baud.

---

## Spare capacity

**11 GPIO remain free**, four of them ADC-capable. These are the main reserve for the
subsystems still to be captured, since the application MCU's pins are fully allocated.

---

## Status

Schematic capture complete. Interfaces to the wired-I/O and near-field sheets are defined and
waiting on those sheets.

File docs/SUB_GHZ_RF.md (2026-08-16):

# Sub-GHz RF — `SUB_GHZ_RF.kicad_sch`

Multi-band sub-GHz radio subsystem: four radios, four SMA ports, switched front-ends covering
315 / 433.92 / 868 MHz.

| | |
|---|---|
| **Sheet** | 5 of 10 |
| **Components** | 231 |
| **Radios** | 3 × TI CC1101 · 1 × Silicon Labs Si4463 |
| **Bands** | 315 · 433.92 · 868 MHz |
| **RF ports** | SMA1 – SMA4 |

---

## Channels

| Port | Radio | Role | Transmit | Receive |
|---|---|---|---|---|
| SMA1 | CC1101-A | capture / replay | ✔ ~+24 dBm | ✔ |
| SMA2 | CC1101-B | jammer / primary TX | ✔ +33 dBm | — |
| SMA3 | CC1101-C | sweep receive | — | ✔ |
| SMA4 | Si4463 | secondary TX/RX | ✔ +20 dBm | ✔ |

Three CC1101s rather than one retuning radio, because the product's core use case is
simultaneous operation — capture on A while jamming on B while sweeping on C. The Si4463 adds
+20 dBm without an external amplifier and a second, independent modem family.

---

## How a channel works

Channel A, the fully-featured one:

```
                    ┌── 315 MHz SAW ──┐
CC1101-A ── balun ──┼── 433 MHz SAW ──┼── T/R switch ──┬── PA ──┬── T/R switch ── SMA1
            + match └── 868 MHz SAW ──┘                └── LNA ─┘
                        (band select)
```

Channel B replaces the receive branch with a 2 W amplifier followed by a switched three-way
low-pass filter bank. Channel C is receive-only. The Si4463 has its own matching network and
antenna switch, with no shared filtering.

The three bands span 2.75:1, which no single filter can cover — hence a switched SAW bank per
channel rather than one fixed filter.

---

## Band selection

One 2-bit code per channel selects the SAW filter. On Channel B the **same** code also selects
the matching post-amplifier low-pass filter, so the filter can never be mismatched to the band
in firmware.

| SEL0 | SEL1 | Selected |
|---|---|---|
| 0 | 0 | isolated (all paths off) |
| 1 | 0 | 315 MHz |
| 0 | 1 | 433.92 MHz |
| 1 | 1 | 868 MHz |

`(0, 0)` is also the power-on state, so the RF path comes up muted.

---

## Control

Slow, set-once lines — band select, amplifier enables, radio shutdown — run through a
**TCA9535 I²C expander at 0x20**. The transmit/receive switch line is a native MCU GPIO,
because it must flip between packets.

All amplifiers and both LNAs are held **off** at power-on, and every radio chip-select idles
high.

---

## Interfaces

| Signal | Direction | Peer sheet |
|---|---|---|
| `SPI_SCK` / `SPI_MOSI` | in | MAIN_CONTROLLER |
| `SPI_MISO` | out | MAIN_CONTROLLER |
| `nCS_CC1101_A/B/C`, `nCS_SI4463` | in | MAIN_CONTROLLER |
| `RF_SW_A` | in | MAIN_CONTROLLER |
| `I2C_SDA` / `I2C_SCL` | bidir / in | MAIN_CONTROLLER |
| `CC1101_A/B/C_GDO0` | out | RP2350_COPROCESSOR |
| `REPLAY_OUT` | in | RP2350_COPROCESSOR |
| `CHG_CE_N`, `BOOST_5V_EN` | out | POWER |

---

## Key part choices

- **SAW filters** — EPCOS/TDK, 315 / 433.92 / 868 MHz. All three share one 3.0 × 3.0 mm
  package, so a single footprint serves all nine positions.
- **Balun** — Anaren B0310J50100AHF, 300 MHz – 1 GHz. One wideband part covers all three bands
  per channel instead of three tuned baluns.
- **RF switches** — Infineon, selected per role: SP3T for band select, a fast SPDT for
  transmit/receive switching, and a 37 dBm-rated SPDT after the 2 W amplifier.
- **LNAs** — Qorvo TQP3M9036, internally matched to 50 Ω so no per-band matching is needed.
- **Amplifiers** — Mini-Circuits TSS-13LN+ on Channel A, Qorvo TQP7M9106 (2 W) on Channel B.
- **References** — 26 MHz ±10 ppm per CC1101; dedicated crystal for the Si4463.

Each radio is supplied through its own ferrite bead from the 3.3 V rail, keeping the radios
isolated from each other and from digital switching noise.

---

## Status

Schematic capture complete. Component values for the Channel B post-amplifier filter bank and
amplifier matching networks are being finalised, and will be set from RF calculation and
first-article measurement.

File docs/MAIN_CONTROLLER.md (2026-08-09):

# Main Controller Sheet

**KiCad source:** [`MAIN_CONTROLLER_sch.kicad_sch`](../MAIN_CONTROLLER_sch.kicad_sch)

The Main Controller sheet contains the ESP32-S3 main processor and its essential power, enable, boot, and communication support circuitry. Its purpose is to provide the primary processing and control hub for the FOBtool hardware and to connect the processor to the radio, positioning, display, storage, user-interface, and secondary-controller subsystems.

Signal names on this sheet are defined from the main-controller perspective so communication interfaces remain consistent throughout the schematic hierarchy.

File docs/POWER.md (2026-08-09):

# Power Sheet

**KiCad source:** [`POWER.kicad_sch`](../POWER.kicad_sch)

The Power sheet contains the board's power-management circuitry. Its purpose is to accept and manage the available power sources, charge and monitor the single-cell battery, generate the regulated supply rails required by the system, and provide the related protection, control, and test connections.

This sheet supplies the rest of the schematic hierarchy and should be reviewed together with the power requirements of every connected subsystem.

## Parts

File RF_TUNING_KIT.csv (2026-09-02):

Category | Nominal Value | Target References | Manufacturer | MPN | Quantity | Distributor | Distributor Link | Datasheet | Fitted/DNP Status | PCBWay Assembly | Notes
RF tuning capacitor | 1.5 pF | C73 | KEMET | CBR04C159B5GAC | 10 | Mouser | https://www.mouser.co.uk/en/ProductDetail/KEMET/CBR04C159B5GAC?qs=9Jcv%252B5Uo%2F3nGbtJizWExGw%3D%3D | https://yageogroup.com/content/datasheet/asset/file/KEM_C1030_CBR_SMD | TUNING SPARE - NOT FITTED | EXCLUDE | Stocked substitute for zero-stock Murata GJM; install only after VNA measurement.
RF tuning capacitor | 2.0 pF | C73 | Murata Electronics | GJM1555C1H2R0BB01D | 10 | Mouser | https://www.mouser.co.uk/en/ProductDetail/Murata-Electronics/GJM1555C1H2R0BB01D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 | https://www.murata.com/en-eu/products/capacitor/ceramiccapacitor/overview/lineup/smd/gjm | TUNING SPARE - NOT FITTED | EXCLUDE | Install only after VNA measurement.
RF tuning capacitor | 3.0 pF | C70 | Murata Electronics | GJM1555C1H3R0BB01D | 10 | Mouser | https://www.mouser.co.uk/en/ProductDetail/Murata-Electronics/GJM1555C1H3R0BB01D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 | https://www.murata.com/en-eu/products/capacitor/ceramiccapacitor/overview/lineup/smd/gjm | TUNING SPARE - NOT FITTED | EXCLUDE | Install only after VNA measurement.
RF tuning capacitor | 3.6 pF | C70 | Murata Electronics | GJM1555C1H3R6BB01D | 10 | Mouser | https://www.mouser.co.uk/en/ProductDetail/Murata-Electronics/GJM1555C1H3R6BB01D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 | https://www.murata.com/en-eu/products/capacitor/ceramiccapacitor/overview/lineup/smd/gjm | TUNING SPARE - NOT FITTED | EXCLUDE | Install only after VNA measurement.
RF tuning capacitor | 4.3 pF | C67; C75 | Murata Electronics | GJM1555C1H4R3BB01D | 10 | Mouser | https://www.mouser.co.uk/en/ProductDetail/Murata-Electronics/GJM1555C1H4R3BB01D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 | https://www.murata.com/en-eu/products/capacitor/ceramiccapacitor/overview/lineup/smd/gjm | TUNING SPARE - NOT FITTED | EXCLUDE | Install only after VNA measurement.
RF tuning capacitor | 5.1 pF | C67; C74; C75 | Murata Electronics | GJM1555C1H5R1BB01D | 10 | Mouser | https://www.mouser.co.uk/en/ProductDetail/Murata-Electronics/GJM1555C1H5R1BB01D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 | https://www.murata.com/en-eu/products/capacitor/ceramiccapacitor/overview/lineup/smd/gjm | TUNING SPARE - NOT FITTED | EXCLUDE | Install only after VNA measurement.
RF tuning capacitor | 6.2 pF | C74 | Murata Electronics | GJM1555C1H6R2BB01D | 10 | Mouser | https://www.mouser.co.uk/en/ProductDetail/Murata-Electronics/GJM1555C1H6R2BB01D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 | https://www.murata.com/en-eu/products/capacitor/ceramiccapacitor/overview/lineup/smd/gjm | TUNING SPARE - NOT FITTED | EXCLUDE | Install only after VNA measurement.
RF tuning capacitor | 8.2 pF | C72 | KEMET | CBR04C829B5GAC | 10 | Mouser | https://www.mouser.co.uk/en/ProductDetail/KEMET/CBR04C829B5GAC?qs=XxWtqqdu%2F9EwUuiUKbh2jA%3D%3D | https://yageogroup.com/content/datasheet/asset/file/KEM_C1030_CBR_SMD | TUNING SPARE - NOT FITTED | EXCLUDE | Stocked substitute for zero-stock Murata GJM; install only after VNA measurement.
RF tuning capacitor | 10 pF | C71; C72 | Murata Electronics | GJM1555C1H100JB01D | 10 | Mouser | https://www.mouser.co.uk/en/ProductDetail/Murata-Electronics/GJM1555C1H100JB01D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 | https://www.murata.com/en-eu/products/capacitor/ceramiccapacitor/overview/lineup/smd/gjm | TUNING SPARE - NOT FITTED | EXCLUDE | Install only after VNA measurement.
RF tuning capacitor | 12 pF | C69; C71 | Murata Electronics | GJM1555C1H120JB01D | 10 | Mouser | https://www.mouser.co.uk/en/ProductDetail/Murata-Electronics/GJM1555C1H120JB01D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 | https://www.murata.com/en-eu/products/capacitor/ceramiccapacitor/overview/lineup/smd/gjm | TUNING SPARE - NOT FITTED | EXCLUDE | Install only after VNA measurement.
RF tuning capacitor | 13 pF | C68 | Murata Electronics | GJM1555C1H130JB01D | 10 | Mouser | https://www.mouser.co.uk/en/ProductDetail/Murata-Electronics/GJM1555C1H130JB01D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 | https://www.murata.com/en-eu/products/capacitor/ceramiccapacitor/overview/lineup/smd/gjm | TUNING SPARE - NOT FITTED | EXCLUDE | Install only after VNA measurement.
RF tuning capacitor | 15 pF | C69 | Murata Electronics | GJM1555C1H150JB01D | 10 | Mouser | https://www.mouser.co.uk/en/ProductDetail/Murata-Electronics/GJM1555C1H150JB01D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 | https://www.murata.com/en-eu/products/capacitor/ceramiccapacitor/overview/lineup/smd/gjm | TUNING SPARE - NOT FITTED | EXCLUDE | Install only after VNA measurement.
RF tuning capacitor | 16 pF | C68 | Murata Electronics | GJM1555C1H160JB01D | 10 | Mouser | https://www.mouser.co.uk/en/ProductDetail/Murata-Electronics/GJM1555C1H160JB01D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 | https://www.murata.com/en-eu/products/capacitor/ceramiccapacitor/overview/lineup/smd/gjm | TUNING SPARE - NOT FITTED | EXCLUDE | Install only after VNA measurement.
RF tuning inductor | 3.6 nH | L32 | Murata Electronics | LQW18AN3N6C00D | 10 | Mouser | https://www.mouser.co.uk/en/ProductDetail/Murata-Electronics/LQW18AN3N6C00D?qs=hKxK89fx60LCy81tpuYB4A%3D%3D | https://pim.murata.com/asset/pim4/inductor/JELF243A-0024_PDF_INDUCTOR | TUNING SPARE - NOT FITTED | EXCLUDE | Install only after VNA and harmonic measurement.
RF tuning inductor | 4.3 nH | L32 | Murata Electronics | LQW18AN4N3C00D | 10 | Mouser | https://www.mouser.co.uk/en/ProductDetail/Murata-Electronics/LQW18AN4N3C00D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 | https://pim.murata.com/asset/pim4/inductor/JELF243A-0024_PDF_INDUCTOR | TUNING SPARE - NOT FITTED | EXCLUDE | Install only after VNA and harmonic measurement.
RF tuning inductor | 8.2 nH | L29 | Murata Electronics | LQW18AN8N2D00D | 10 | Mouser | https://www.mouser.co.uk/en/ProductDetail/Murata-Electronics/LQW18AN8N2D00D?qs=D44APCoREsTtpEsFi6CA%2Fg%3D%3D | https://pim.murata.com/asset/pim4/inductor/JELF243A-0024_PDF_INDUCTOR | TUNING SPARE - NOT FITTED | EXCLUDE | Install only after VNA and harmonic measurement.
RF tuning inductor | 10 nH | L29 | Murata Electronics | LQW18AN10NJ00D | 10 | Mouser | https://www.mouser.co.uk/en/ProductDetail/Murata-Electronics/LQW18AN10NJ00D?qs=uNPdTkgJI6Ij1YZiYZRkfg%3D%3D | https://pim.murata.com/asset/pim4/inductor/JELF243A-0024_PDF_INDUCTOR | TUNING SPARE - NOT FITTED | EXCLUDE | Install only after VNA and harmonic measurement.
RF tuning inductor | 11 nH | L26; L30 | Murata Electronics | LQW18AN11NJ00D | 10 | Mouser | https://www.mouser.co.uk/en/ProductDetail/Murata-Electronics/LQW18AN11NJ00D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 | https://pim.murata.com/asset/pim4/inductor/JELF243A-0024_PDF_INDUCTOR | TUNING SPARE - NOT FITTED | EXCLUDE | Install only after VNA and harmonic measurement.
RF tuning inductor | 12 nH | L31 | Murata Electronics | LQW18AN12NJ00D | 10 | Mouser | https://www.mouser.co.uk/en/ProductDetail/Murata-Electronics/LQW18AN12NJ00D?qs=a6NhTrN4IIKxxIWUKRNpWg%3D%3D | https://pim.murata.com/asset/pim4/inductor/JELF243A-0024_PDF_INDUCTOR | TUNING SPARE - NOT FITTED | EXCLUDE | Install only after VNA and harmonic measurement.
RF tuning inductor | 13 nH | L26; L30 | Murata Electronics | LQW18AN13NJ00D | 10 | Mouser | https://www.mouser.co.uk/en/ProductDetail/Murata-Electronics/LQW18AN13NJ00D?qs=a6NhTrN4IIKtp8PeROuqew%3D%3D | https://pim.murata.com/asset/pim4/inductor/JELF243A-0024_PDF_INDUCTOR | TUNING SPARE - NOT FITTED | EXCLUDE | Install only after VNA and harmonic measurement.
RF tuning inductor | 16 nH | L31 | Murata Electronics | LQW18AN16NJ00D | 10 | Mouser | https://www.mouser.co.uk/en/ProductDetail/Murata-Electronics/LQW18AN16NJ00D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 | https://pim.murata.com/asset/pim4/inductor/JELF243A-0024_PDF_INDUCTOR | TUNING SPARE - NOT FITTED | EXCLUDE | Stocked replacement for unavailable 15 nH option; install only after measurement.
RF tuning inductor | 22 nH | L27 | Murata Electronics | LQW18AN22NJ00D | 10 | Mouser | https://www.mouser.co.uk/en/ProductDetail/Murata-Electronics/LQW18AN22NJ00D?qs=DUiBgnZiRiYU8MoKWWpN0w%3D%3D | https://pim.murata.com/asset/pim4/inductor/JELF243A-0024_PDF_INDUCTOR | TUNING SPARE - NOT FITTED | EXCLUDE | Install only after VNA and harmonic measurement.
RF tuning inductor | 24 nH | L28 | Murata Electronics | LQW18AN24NJ00D | 10 | Mouser | https://www.mouser.co.uk/en/ProductDetail/Murata-Electronics/LQW18AN24NJ00D?qs=DUiBgnZiRiY9RqhGGnA5DA%3D%3D | https://pim.murata.com/asset/pim4/inductor/JELF243A-0024_PDF_INDUCTOR | TUNING SPARE - NOT FITTED | EXCLUDE | Install only after VNA and harmonic measurement.
RF tuning inductor | 27 nH | L27 | Murata Electronics | LQW18AN27NJ00D | 10 | Mouser | https://www.mouser.co.uk/en/ProductDetail/Murata-Electronics/LQW18AN27NJ00D?qs=DUiBgnZiRibaM%2FYjO7aStA%3D%3D | https://pim.murata.com/asset/pim4/inductor/JELF243A-0024_PDF_INDUCTOR | TUNING SPARE - NOT FITTED | EXCLUDE | Install only after VNA and harmonic measurement.
RF tuning inductor | 30 nH | L24; L28 | Murata Electronics | LQW18AN30NJ00D | 10 | Mouser | https://www.mouser.co.uk/en/ProductDetail/Murata-Electronics/LQW18AN30NJ00D?qs=kxvqxJXdJnZNrH%2Ft0GdDBA%3D%3D | https://pim.murata.com/asset/pim4/inductor/JELF243A-0024_PDF_INDUCTOR | TUNING SPARE - NOT FITTED | EXCLUDE | Install only after VNA and harmonic measurement.
RF tuning inductor | 36 nH | L24; L25 | Murata Electronics | LQW18AN36NJ00D | 10 | Mouser | https://www.mouser.co.uk/en/ProductDetail/Murata-Electronics/LQW18AN36NJ00D?qs=kxvqxJXdJnYR1yrXvHBeXw%3D%3D | https://pim.murata.com/asset/pim4/inductor/JELF243A-0024_PDF_INDUCTOR | TUNING SPARE - NOT FITTED | EXCLUDE | Install only after VNA and harmonic measurement.
RF tuning inductor | 43 nH | L25 | Murata Electronics | LQW18AN43NJ00D | 10 | Mouser | https://www.mouser.co.uk/en/ProductDetail/Murata-Electronics/LQW18AN43NJ00D?qs=hKxK89fx60Loe8AM1U09mA%3D%3D | https://pim.murata.com/asset/pim4/inductor/JELF243A-0024_PDF_INDUCTOR | TUNING SPARE - NOT FITTED | EXCLUDE | Install only after VNA and harmonic measurement.

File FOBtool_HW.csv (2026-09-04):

Reference | Value | DNP | Exclude from BOM | Exclude from Board | Exclude from Simulation | Footprint | MANUFACTURER | MPN | DISTRIBUTOR LINK | Datasheet | Notes | Qty
AE1,AE2 | UWA.01 |  |  |  |  |  | Taoglas | UWA.01 | https://eu.mouser.com/en/ProductDetail/Taoglas/UWA.01?qs=9vOqFld9vZVByrqnvTt01g%3D%3D | https://www.taoglas.com/datasheets/UWA.01.pdf | Identical PDoA pair; same orientation; no substitution without RF revalidation. | 2
AE3 | Antenna_Loop |  |  |  |  |  | PCB antenna | N/A | N/A | https://www.nxp.com/docs/en/application-note/AN13219.pdf | PCB NFC loop; tune on first article. | 1
AE4 | ADFGP.25E.07.0060A |  |  | Excluded from board |  |  | Taoglas | ADFGP.25E.07.0060A | https://eu.mouser.com/en/ProductDetail/Taoglas/ADFGP.25E.07.0060A?qs=W%2FMpXkg%252BdQ5cVoIP0t8jng%3D%3D | https://eu.mouser.com/datasheet/3/942/1/ADFGP.25E.07.0060A.pdf | Off-board active GNSS patch antenna; 1559–1610 MHz; 60 mm coax; I-PEX MHF I/U.FL-compatible connector; mates J13. | 1
BT1 | VTC-LP484594 3.7V 2200mAh protected battery pack |  |  | Excluded from board |  |  | VTC Power Co., Ltd. | VTC-LP484594 | https://vtcbatt.com/lvtc-lp484594-3-7v-2200mah-li-ion-polymer-battery/ | https://vtcbatt.com/lvtc-lp484594-3-7v-2200mah-li-ion-polymer-battery/ | Off-board protected 1S 2200mAh pack with 10k NTC. Includes JST PHR-3 housing and 3x SPH-002T-P0.5S contacts. Required cavity order: 1=BAT+/red, 2=NTC/yellow, 3=GND/black. Supplier drawing and samples must confirm polarity before purchase. | 1
BZ1 | AST1109MLTRQ |  |  |  |  | Buzzer_Beeper:Buzzer_Mallory_AST1109MLTRQ | Mallory Sonalert | AST1109MLTRQ | https://www.mouser.com/ProductDetail/Mallory-Sonalert/AST1109MLTRQ?qs=GpRChIzryBM5c7g4uet5pQ%3D%3D | https://www.mallory-sonalert.com/specifications/AST1109MLTRQ.pdf | N/A | 1
C1,C23,C45,C58,C79,C111,C124,C132,C143,C163,C164,C165,C181,C230 | 1u |  |  |  |  | Capacitor_SMD:C_0603_1608Metric | Murata | GRM188R71C105KA12D | https://www.mouser.com/ProductDetail/Murata-Electronics/GRM188R71C105KA12D?qs=wknuCjwwyK4FvjRMMlVuNQ%3D%3D | https://pim.murata.com/en-global/pim/details/?partNum=GRM188R71C105KA12D | N/A | 14
C2,C4,C5,C11,C12,C19,C20,C21,C24,C193,C211,C212,C221,C222,C261 | 22u |  |  |  |  | Capacitor_SMD:C_1206_3216Metric | Murata | GRM31CR71A226KE15L | https://www.mouser.com/ProductDetail/Murata-Electronics/GRM31CR71A226KE15L?qs=%2FBLjsTEvPnhfnPGA5Hlk4g%3D%3D | https://pim.murata.com/en-global/pim/details/?partNum=GRM31CR71A226KE15L | Verify effective capacitance under DC bias. | 15
C3 | 47n |  |  |  |  | Capacitor_SMD:C_0603_1608Metric | Murata | GRM188R71C473KA01D | https://www.mouser.com/ProductDetail/Murata-Electronics/GRM188R71C473KA01D?qs=34S%252BtexyrxpyG5jfkflBKw%3D%3D | https://pim.murata.com/en-global/pim/details/?partNum=GRM188R71C473KA01D | N/A | 1
C6,C22,C40,C102,C157,C170,C172,C186,C189,C190,C204 | 10u |  |  |  |  | Capacitor_SMD:C_0805_2012Metric | Murata | GRM21BR71A106KE51L | https://www.mouser.com/ProductDetail/Murata-Electronics/GRM21BR71A106KE51L?qs=kHCDrmfBqSAdNFLacabF8w%3D%3D | https://pim.murata.com/en-global/pim/details/?partNum=GRM21BR71A106KE51L | Verify effective capacitance under DC bias. | 11
C7,C231,C238 | 4u7 |  |  |  |  | Capacitor_SMD:C_0805_2012Metric | Murata | GRM21BR71A475KA73L | https://www.mouser.com/ProductDetail/Murata-Electronics/GRM21BR71A475KA73L?qs=kHCDrmfBqSAAYeeMCPW7Gg%3D%3D | https://pim.murata.com/en-global/pim/details/?partNum=GRM21BR71A475KA73L | Verify effective capacitance under DC bias. | 3
C8,C9,C10 | 47u |  |  |  |  | Capacitor_SMD:C_1210_3225Metric | Murata | GRM32ER71A476KE15L | https://www.mouser.com/ProductDetail/Murata-Electronics/GRM32ER71A476KE15L?qs=igOKQWwJTmw3%252BdJ0z0AeYw%3D%3D | https://pim.murata.com/en-global/pim/details/?partNum=GRM32ER71A476KE15L | Verify effective capacitance under DC bias. | 3
C13,C97,C100,C233,C234,C255,C256 | 2u2 |  |  |  |  | Capacitor_SMD:C_0603_1608Metric | Murata | GRM188R71A225KE15D | https://www.mouser.com/ProductDetail/Murata-Electronics/GRM188R71A225KE15D?qs=FI%2F1jqMWe7rgTInCPAq47w%3D%3D | https://pim.murata.com/en-global/pim/details/?partNum=GRM188R71A225KE15D | N/A | 7
C14 | 10p |  |  |  |  | Capacitor_SMD:C_0603_1608Metric | Murata | GRM1885C1H100JA01D | https://www.mouser.com/ProductDetail/Murata-Electronics/GRM1885C1H100JA01D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 | https://pim.murata.com/en-global/pim/details/?partNum=GRM1885C1H100JA01D | N/A | 1
C15,C208,C226,C251,C252 | 1n |  |  |  |  | Capacitor_SMD:C_0603_1608Metric | Murata | GRM1885C1H102JA01D | https://www.mouser.com/ProductDetail/Murata-Electronics/GRM1885C1H102JA01D?qs=H3lwsW1hsDtu9zD8AnV%2FOA%3D%3D | https://pim.murata.com/en-global/pim/details/?partNum=GRM1885C1H102JA01D | N/A | 5
C16,C25,C150,C154,C156,C158,C159,C161,C162,C166,C167,C168,C169,C171,C176,C177,C178,C180,C182,C206,C207,C209,C210,C219,C220,C232,C237,C259,C260,C262 | 100n |  |  |  |  | Capacitor_SMD:C_0603_1608Metric | Murata | GRM188R71C104KA01D | https://www.mouser.com/ProductDetail/Murata-Electronics/GRM188R71C104KA01D?qs=WZmVLWkT%2FeCcuvj%2FpnjfsA%3D%3D | https://pim.murata.com/en-global/pim/details/?partNum=GRM188R71C104KA01D | N/A | 30
C17 | 0u1 |  |  |  |  | Capacitor_SMD:C_0603_1608Metric | Murata | GRM188R71C104KA01D | https://www.mouser.com/ProductDetail/Murata-Electronics/GRM188R71C104KA01D?qs=WZmVLWkT%2FeCcuvj%2FpnjfsA%3D%3D | https://pim.murata.com/en-global/pim/details/?partNum=GRM188R71C104KA01D | N/A | 1
C18 | 120u |  |  |  |  |  | Panasonic | EEF-TX0J121RF | https://www.mouser.com/ProductDetail/Panasonic/EEF-TX0J121RF?qs=17ckDYBRdel6t%2F9KIt481Q%3D%3D | https://industrial.panasonic.com/ww/products/pt/sp-cap/models/EEFTX0J121RF | Polarized 2-terminal SP-Cap; pin 1/+ = VBUS_HOST, pin 2/- = GND | 1
C26,C29,C32,C153,C155 | 4u7 |  |  |  |  | Capacitor_SMD:C_0603_1608Metric | Murata | GRM188Z71A475KE15D | https://eu.mouser.com/en/ProductDetail/Murata-Electronics/GRM188Z71A475KE15D?qs=Ey7%2FXF42M3f4zgfhxcfIIw%3D%3D | https://pim.murata.com/asset/pim4/ceramicCapacitorSMD/GRM188Z71A475KE15-01A-EN_PDF_CERAMICCAPACITORSMD | N/A | 5
C27,C28,C33,C34,C35,C36,C37,C38,C39,C41,C42,C46,C47,C80,C83,C84,C85,C86,C87,C88,C89,C90,C93,C94,C95,C98,C99,C103,C104,C105,C106,C107,C108,C112,C118,C119,C121,C126,C127,C128,C129,C130,C131,C134,C137,C147,C148,C149,C184,C187,C192,C195,C196,C203 | 100n |  |  |  |  | Capacitor_SMD:C_0402_1005Metric | Murata | GRM155R71C104KA88D | https://www.mouser.com/ProductDetail/Murata-Electronics/GRM155R71C104KA88D?qs=8YPuuxuUzMJKePo9sU3A2g%3D%3D | https://pim.murata.com/en-global/pim/details/?partNum=GRM155R71C104KA88D | N/A | 54
C30,C31,C81,C82,C116,C117,C135,C136 | 15p |  |  |  |  | Capacitor_SMD:C_0402_1005Metric | Murata | GJM1555C1H150JB01D | https://www.mouser.com/ProductDetail/Murata-Electronics/GJM1555C1H150JB01D?qs=a0pwrXwGanj7wlRhnCU%252Bug%3D%3D | https://pim.murata.com/en-global/pim/details/?partNum=GJM1555C1H150JB01D | N/A | 8
C43,C44 | 4p7 |  |  |  |  | Capacitor_SMD:C_0402_1005Metric | Murata | GJM1555C1H4R7BB01D | https://www.mouser.com/ProductDetail/Murata-Electronics/GJM1555C1H4R7BB01D?qs=Qf9gV6gYIayum3lGtz9y0A%3D%3D | https://pim.murata.com/en-global/pim/details/?partNum=GJM1555C1H4R7BB01D | N/A | 2
C48 | 1p |  |  |  |  | Capacitor_SMD:C_0402_1005Metric | Murata | GJM1555C1H1R0BB01D | https://www.mouser.com/ProductDetail/Murata-Electronics/GJM1555C1H1R0BB01D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 | https://pim.murata.com/en-global/pim/details/?partNum=GJM1555C1H1R0BB01D | N/A | 1
C49 | 3p |  |  |  |  | Capacitor_SMD:C_0402_1005Metric | Murata | GJM1555C1H3R0BB01D | https://www.mouser.com/ProductDetail/Murata-Electronics/GJM1555C1H3R0BB01D?qs=fOe5G3t%252BQHoZjxUrLCJNQQ%3D%3D | https://pim.murata.com/en-global/pim/details/?partNum=GJM1555C1H3R0BB01D | N/A | 1
C50 | 3p9 |  |  |  |  | Capacitor_SMD:C_0402_1005Metric | Murata | GJM1555C1H3R9BB01D | https://www.mouser.com/ProductDetail/Murata-Electronics/GJM1555C1H3R9BB01D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 | https://pim.murata.com/en-global/pim/details/?partNum=GJM1555C1H3R9BB01D | N/A | 1
C51 | 5p1 |  |  |  |  | Capacitor_SMD:C_0402_1005Metric | Murata | GJM1555C1H5R1BB01D | https://www.mouser.com/ProductDetail/Murata-Electronics/GJM1555C1H5R1BB01D?qs=YLLXL5qGyDsC0ZZVCZbXgA%3D%3D | https://pim.murata.com/en-global/pim/details/?partNum=GJM1555C1H5R1BB01D | N/A | 1
C52 | 2p7 |  |  |  |  | Capacitor_SMD:C_0402_1005Metric | Murata | GJM1555C1H2R7BB01D | https://www.mouser.com/ProductDetail/Murata-Electronics/GJM1555C1H2R7BB01D?qs=Qf9gV6gYIawNxW7nURgGBg%3D%3D | https://pim.murata.com/en-global/pim/details/?partNum=GJM1555C1H2R7BB01D | N/A | 1
C53,C57,C59,C62,C76,C77,C113,C115,C120,C122,C123,C125,C138,C139,C141,C142,C144 | 100p |  |  |  |  | Capacitor_SMD:C_0402_1005Metric | Murata | GRM1555C1H101JA01D | https://eu.mouser.com/en/ProductDetail/Murata-Electronics/GRM1555C1H101JA01D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 | https://pim.murata.com/en-eu/pim/details/?partNum=GRM1555C1H101JA01D | N/A | 17
C54 | 100p |  |  |  |  | Capacitor_SMD:C_0402_1005Metric | Murata | GRM1555C1H101JA01D | https://eu.mouser.com/en/ProductDetail/Murata-Electronics/GRM1555C1H101JA01D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 | https://pim.murata.com/asset/pim4/ceramicCapacitorSMD/GRM1555C1H101JA01-01A-EN_PDF_CERAMICCAPACITORSMD | C0G; initial PA input match; tune on Rev-A. | 1
C55 | 8p2 |  |  |  |  | Capacitor_SMD:C_0402_1005Metric | Murata | GJM1555C1H8R2DB01D | https://www.mouser.com/ProductDetail/Murata-Electronics/GJM1555C1H8R2DB01D?qs=563MOeNa05I6DnfmsnEEKg%3D%3D | https://pim.murata.com/en-global/pim/details/?partNum=GJM1555C1H8R2DB01%23 | Initial PA input match; tuning alternatives: DNP, 5.6pF. | 1
C56 | 15p |  |  |  |  | Capacitor_SMD:C_0402_1005Metric | Murata | GJM1555C1H150JB01D | https://www.mouser.com/ProductDetail/Murata-Electronics/GJM1555C1H150JB01D?qs=a0pwrXwGanj7wlRhnCU%252Bug%3D%3D | https://www.murata.com/en-global/products/capacitor/ceramiccapacitor/overview/lineup/smd/gjm | Initial PA input match; tuning alternative: DNP. | 1
C60 | 68u |  |  |  |  |  | Panasonic | EEF-LR0J680R | https://www.mouser.com/ProductDetail/Panasonic/EEF-LR0J680R?qs=8FpcGrFpUlHucaPrCq%252BIKw%3D%3D | https://industrial.panasonic.com/ww/products/pt/sp-cap/models/EEFLR0J680R | Polarized Panasonic LR three-terminal SP-Cap; schematic pin 1/+ = +5V_SYS and pin 2/- = GND. Custom layout footprint shall use positive pad 1 and both negative terminals numbered 2. | 1
C61,C63 | 1000p |  |  |  |  | Capacitor_SMD:C_0402_1005Metric | Murata | GRM1555C1H102JA01D | https://www.mouser.com/ProductDetail/Murata-Electronics/GRM1555C1H102JA01D?qs=%2FOTtAhf8R8ZL4biNptvoUQ%3D%3D | https://pim.murata.com/en-global/pim/details/?partNum=GRM1555C1H102JA01D | N/A | 2
C64,C65 | 22p |  |  |  |  | Capacitor_SMD:C_0402_1005Metric | Murata,Murata Electronics | GJM1555C1H220JB01D | https://eu.mouser.com/en/ProductDetail/Murata-Electronics/GJM1555C1H220JB01D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 | https://pim.murata.com/asset/pim4/ceramicCapacitorSMD/GJM1555C1H220JB01-01A-EN_PDF_CERAMICCAPACITORSMD | N/A | 2
C66 | 6p8 |  |  |  |  | Capacitor_SMD:C_0402_1005Metric | Murata Electronics | GJM1555C1H6R8CB01D | https://eu.mouser.com/en/ProductDetail/Murata-Electronics/GJM1555C1H6R8CB01D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 | https://eu.mouser.com/datasheet/3/76/1/GJM1555C1H6R8CB01-01A.pdf | Rev-A initial fitted value; finalize with L36 by VNA and harmonic testing. | 1
C67,C75 | 4p7 |  |  |  |  | Capacitor_SMD:C_0402_1005Metric | Murata | GJM1555C1H4R7BB01D | https://www.mouser.com/en/ProductDetail/Murata-Electronics/GJM1555C1H4R7BB01D?qs=Qf9gV6gYIayum3lGtz9y0A%3D%3D | https://pim.murata.com/asset/pim4/ceramicCapacitorSMD/GJM1555C1H4R7BB01-01A-EN_PDF_CERAMICCAPACITORSMD | Rev-A initial fitted value; finalize by VNA/harmonic testing. | 2
C68 | 15p |  |  |  |  | Capacitor_SMD:C_0402_1005Metric | Murata | GJM1555C1H150JB01D | https://www.mouser.com/en/ProductDetail/Murata-Electronics/GJM1555C1H150JB01D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 | https://www.mouser.co.uk/datasheet/3/76/1/GJM1555C1H150JB01-01A.pdf | Rev-A initial fitted value; finalize by VNA/harmonic testing. | 1
C69 | 13p |  |  |  |  | Capacitor_SMD:C_0402_1005Metric | Murata | GJM1555C1H130JB01D | https://www.mouser.com/en/ProductDetail/Murata-Electronics/GJM1555C1H130JB01D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 | https://www.mouser.com/datasheet/3/76/4/GJM1555C1H130JB01_01A.pdf | Rev-A initial fitted value; finalize by VNA/harmonic testing. | 1
C70 | 3p3 |  |  |  |  | Capacitor_SMD:C_0402_1005Metric | Murata | GJM1555C1H3R3BB01D | https://www.mouser.com/en/ProductDetail/Murata-Electronics/GJM1555C1H3R3BB01D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 | https://www.mouser.com/datasheet/3/76/4/GJM1555C1H3R3BB01_01A.pdf | Rev-A initial fitted value; finalize by VNA/harmonic testing. | 1
C71 | 11p |  |  |  |  | Capacitor_SMD:C_0402_1005Metric | Murata | GJM1555C1H110JB01D | https://www.mouser.com/en/ProductDetail/Murata-Electronics/GJM1555C1H110JB01D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 | https://www.mouser.com/datasheet/3/76/2/GJM1555C1H110JB01_01A.pdf | Rev-A initial fitted value; finalize by VNA/harmonic testing. | 1
C72 | 9p1 |  |  |  |  | Capacitor_SMD:C_0402_1005Metric | Murata | GJM1555C1H9R1DB01D | https://www.mouser.com/en/ProductDetail/Murata-Electronics/GJM1555C1H9R1DB01D?qs=563MOeNa05JIr1ovWebPcA%3D%3D | https://pim.murata.com/asset/pim4/ceramicCapacitorSMD/GJM1555C1H9R1DB01-01A-EN_PDF_CERAMICCAPACITORSMD | Rev-A initial fitted value; finalize by VNA/harmonic testing. | 1
C73 | 1p8 |  |  |  |  | Capacitor_SMD:C_0402_1005Metric | Murata | GJM1555C1H1R8BB01D | https://www.mouser.com/en/ProductDetail/Murata-Electronics/GJM1555C1H1R8BB01D?qs=uMOEPI8dpz3WIjWI0mj0rg%3D%3D | https://www.mouser.com/datasheet/3/76/1/GJM1555C1H1R8BB01_01A.pdf | Rev-A initial fitted value; finalize by VNA/harmonic testing. | 1
C74 | 5p6 |  |  |  |  | Capacitor_SMD:C_0402_1005Metric | Murata | GJM1555C1H5R6BB01D | https://www.mouser.com/en/ProductDetail/Murata-Electronics/GJM1555C1H5R6BB01D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 | https://www.murata.com/en-global/products/capacitor/ceramiccapacitor/overview/lineup/smd/gjm | Rev-A initial fitted value; finalize by VNA/harmonic testing. | 1
C78,C114,C140 | 0p6 |  |  |  |  | Capacitor_SMD:C_0402_1005Metric | Murata | GJM1555C1HR60BB01D | https://www.mouser.com/ProductDetail/Murata-Electronics/GJM1555C1HR60BB01D?qs=YLLXL5qGyDvwV5XNlN8wXg%3D%3D | https://pim.murata.com/en-global/pim/details/?partNum=GJM1555C1HR60BB01D | N/A | 3
C91,C109,C145 | NM | DNP |  |  |  | Capacitor_SMD:C_0402_1005Metric | DNP | N/A | N/A | https://www.murata.com/en-global/products/capacitor/ceramiccapacitor/overview/lineup/smd/gjm | DNP; tuning pads retained. | 3
C92,C110,C146 | 1p2 |  |  |  |  | Capacitor_SMD:C_0402_1005Metric | Murata | GJM1555C1H1R2BB01D | https://www.mouser.com/ProductDetail/Murata-Electronics/GJM1555C1H1R2BB01D?qs=jFYifRxgN9hGz46HvGskaw%3D%3D | https://pim.murata.com/en-global/pim/details/?partNum=GJM1555C1H1R2BB01D | N/A | 3
C96 | 1p5 |  |  |  |  | Capacitor_SMD:C_0402_1005Metric | Murata | GJM1555C1H1R5BB01D | https://www.mouser.com/ProductDetail/Murata-Electronics/GJM1555C1H1R5BB01D?qs=a0pwrXwGaniRHm6o1K7wmA%3D%3D | https://pim.murata.com/en-global/pim/details/?partNum=GJM1555C1H1R5BB01D | N/A | 1
C101 | 1n |  |  |  |  | Capacitor_SMD:C_0402_1005Metric | Murata | GRM1555C1H102JA01D | https://www.mouser.com/ProductDetail/Murata-Electronics/GRM1555C1H102JA01D?qs=%2FOTtAhf8R8ZL4biNptvoUQ%3D%3D | https://pim.murata.com/en-global/pim/details/?partNum=GRM1555C1H102JA01D | N/A | 1
C151,C152,C243,C249 | 100p |  |  |  |  | Capacitor_SMD:C_0603_1608Metric | Murata | GRM1885C1H101JA01D | https://www.mouser.com/ProductDetail/Murata-Electronics/GRM1885C1H101JA01D?qs=H3lwsW1hsDt1I4guwPQ00A%3D%3D | https://pim.murata.com/en-global/pim/details/?partNum=GRM1885C1H101JA01D | N/A | 4
C160 | 4n7 |  |  |  |  | Capacitor_SMD:C_0603_1608Metric | Murata | GRM1885C1H472JA01D | https://www.mouser.com/ProductDetail/Murata-Electronics/GRM1885C1H472JA01D?qs=e4Xae8FWUKn%2FMRcWxYvfaQ%3D%3D | https://pim.murata.com/en-global/pim/details/?partNum=GRM1885C1H472JA01D | N/A | 1
C173,C174,C205 | 10n |  |  |  |  | Capacitor_SMD:C_0603_1608Metric | Murata | GRM188R71C103KA01D | https://www.mouser.com/ProductDetail/Murata-Electronics/GRM188R71C103KA01D?qs=NqI629o6baBlIx9ASUr9BQ%3D%3D | https://pim.murata.com/en-global/pim/details/?partNum=GRM188R71C103KA01D | N/A | 3
C179 | 11mF |  |  |  |  |  | Seiko Instruments | CPH3225A | https://www.mouser.com/ProductDetail/Seiko-Semiconductors/CPH3225A?qs=3etwrb1wR%252BhUOph6lAO7eg%3D%3D | https://www.sii.co.jp/en/me/datasheets/chip-capacitor/cph3225a/ | Polarized EDLC; preserve pin-1/+ orientation | 1
C183 | 220n |  |  |  |  | Capacitor_SMD:C_0402_1005Metric | Murata | GRM155R71A224KE01D | https://www.mouser.com/ProductDetail/Murata-Electronics/GRM155R71A224KE01D?qs=hNud%2FORuBR0TVQaPIZxsqw%3D%3D | https://pim.murata.com/en-global/pim/details/?partNum=GRM155R71A224KE01D | N/A | 1
C185,C188,C191 | 4n7 |  |  |  |  | Capacitor_SMD:C_0402_1005Metric | Murata | GRM1555C1H472JE01D | https://eu.mouser.com/en/ProductDetail/Murata-Electronics/GRM1555C1H472JE01D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 | https://eu.mouser.com/datasheet/3/76/2/GRM1555C1H472JE01_01A.pdf | Exact Rev-A fitted C0G capacitor; no substitution without RF revalidation. | 3
C194,C197,C199,C201,C202 | 2p |  |  |  |  | Capacitor_SMD:C_0402_1005Metric | Murata | GJM1555C1H2R0BB01D | https://www.mouser.com/ProductDetail/Murata-Electronics/GJM1555C1H2R0BB01D?qs=fOe5G3t%252BQHqBllXqhVoZLQ%3D%3D | https://pim.murata.com/en-global/pim/details/?partNum=GJM1555C1H2R0BB01D | N/A | 5
C198,C200 | NM | DNP |  |  |  | Capacitor_SMD:C_0402_1005Metric | N/A | N/A | N/A | https://www.murata.com/en-global/products/capacitor/ceramiccapacitor/overview/lineup/smd/gjm | Rev-A DNP; UWB shunt-tuning position; fit only after VNA measurement. | 2
C213,C223 | 47p | DNP |  |  |  | Capacitor_SMD:C_0603_1608Metric | Murata | GRM1885C1H470JA01D | https://www.mouser.com/ProductDetail/Murata-Electronics/GRM1885C1H470JA01D?qs=O9uLJ8zUlXh5RYe7VRRgug%3D%3D | https://pim.murata.com/en-global/pim/details/?partNum=GRM1885C1H470JA01D | Rev-A DNP; LF resonance trim option; populate only after measuring the assembled coil | 2
C214,C224 | 100p | DNP |  |  |  | Capacitor_SMD:C_0603_1608Metric | Murata | GRM1885C1H101JA01D | https://www.mouser.com/ProductDetail/Murata-Electronics/GRM1885C1H101JA01D?qs=H3lwsW1hsDt1I4guwPQ00A%3D%3D | https://pim.murata.com/en-global/pim/details/?partNum=GRM1885C1H101JA01D | Rev-A DNP; LF resonance trim option; populate only after measuring the assembled coil | 2
C215,C225 | 220p | DNP |  |  |  | Capacitor_SMD:C_0603_1608Metric | Murata | GRM1885C1H221JA01D | https://www.mouser.com/ProductDetail/Murata-Electronics/GRM1885C1H221JA01D?qs=wkTplMQEP5E5DEUKvrPh1w%3D%3D | https://pim.murata.com/en-global/pim/details/?partNum=GRM1885C1H221JA01D | Rev-A DNP; LF resonance trim option; populate only after measuring the assembled coil | 2
C216,C218,C227,C229 | 220p |  |  |  |  | Capacitor_SMD:C_0603_1608Metric | Murata | GRM1885C1H221JA01D | https://www.mouser.com/ProductDetail/Murata-Electronics/GRM1885C1H221JA01D?qs=wkTplMQEP5E5DEUKvrPh1w%3D%3D | https://pim.murata.com/en-global/pim/details/?partNum=GRM1885C1H221JA01D | N/A | 4
C217,C228 | 3n3 |  |  |  |  | Capacitor_SMD:C_0603_1608Metric | Murata | GRM1885C1H332JA01D | https://www.mouser.com/ProductDetail/Murata-Electronics/GRM1885C1H332JA01D?qs=Y0gyZw6qHXc%2F44YlKMSasA%3D%3D | https://pim.murata.com/en-global/pim/details/?partNum=GRM1885C1H332JA01D | N/A | 2
C235,C236 | 12p | DNP |  |  |  | Capacitor_SMD:C_0603_1608Metric | Murata | GRM1885C1H120JA01D | https://www.mouser.com/en/ProductDetail/Murata-Electronics/GRM1885C1H120JA01D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 | https://pim.murata.com/en-global/pim/details/?partNum=GRM1885C1H120JA01D | Rev-A DNP; optional PN7160 low-power field-detection coupling; fit both together only if required. | 2
C239,C245 | 330p |  |  |  |  | Capacitor_SMD:C_0603_1608Metric | Murata | GRM1885C1H331JA01D | https://www.mouser.com/ProductDetail/Murata-Electronics/GRM1885C1H331JA01D?qs=DiwnqUvG%2FIUYCCwNVhuo3w%3D%3D | https://pim.murata.com/en-global/pim/details/?partNum=GRM1885C1H331JA01D | N/A | 2
C240,C242,C244,C246,C248,C250 | NM | DNP |  |  |  | Capacitor_SMD:C_0603_1608Metric | DNP | N/A | N/A | https://www.murata.com/en-global/products/capacitor/ceramiccapacitor/overview/lineup/smd/grm | Rev-A DNP; optional NFC matching trim; fit only after antenna measurement. | 6
C241,C247 | 68p |  |  |  |  | Capacitor_SMD:C_0603_1608Metric | Murata | GRM1885C1H680JA01D | https://www.mouser.com/ProductDetail/Murata-Electronics/GRM1885C1H680JA01D?qs=AltDASTWtMq9uMROk9HzHA%3D%3D | https://pim.murata.com/en-global/pim/details/?partNum=GRM1885C1H680JA01D | N/A | 2
C253,C254 | 15p |  |  |  |  | Capacitor_SMD:C_0603_1608Metric | Murata | GRM1885C1H150JA01D | https://www.mouser.com/ProductDetail/Murata-Electronics/GRM1885C1H150JA01D?qs=ypZ4AbmluZj4AM%2FOQHMZww%3D%3D | https://pim.murata.com/en-global/pim/details/?partNum=GRM1885C1H150JA01D | N/A | 2
C257,C258 | DNP | DNP |  |  |  | Capacitor_SMD:C_0402_1005Metric | N/A | N/A | N/A | https://www.murata.com/en-global/products/capacitor/ceramiccapacitor/overview/lineup/smd/gjm | Rev-A DNP; UWB shunt-tuning position; fit only after VNA measurement. | 2
D1,D3,D16,D17,D18,D19 | PESD5V0F1BRSF |  |  |  |  | Diode_SMD:Nexperia_DSN0603-2_0.6x0.3mm_P0.4mm | Nexperia | PESD5V0F1BRSFYL | https://www.digikey.com/en/products/detail/nexperia-usa-inc/PESD5V0F1BRSFYL/4289732 | https://assets.nexperia.com/documents/data-sheet/PESD5V0F1BRSF.pdf | PCBWay: source exact DSN0603-2 part; no package change. | 6
D2 | RCLAMP2451ZA |  |  |  |  |  | Semtech | RCLAMP2451ZATFT | https://www.mouser.com/ProductDetail/Semtech/RCLAMP2451ZATFT?qs=rBWM4%252BvDhIel2swgnRTQsw%3D%3D | https://www.semtech.com/products/circuit-protection/low-capacitance/rclamp2451za | Custom SLP0603P2X3F footprint required. | 1
D4,D5 | TPD1E10B06 |  |  |  |  | Package_SON:Texas_DPY0002A_0.6x1mm_P0.65mm | Texas Instruments | TPD1E10B06DPYR | https://www.mouser.com/ProductDetail/Texas-Instruments/TPD1E10B06DPYR?qs=UFc95S4Z4CaJYpQ4xqTc0g%3D%3D | https://www.ti.com/lit/ds/symlink/tpd1e10b06.pdf | N/A | 2
D6 | NUP2105L |  |  |  |  | Package_TO_SOT_SMD:SOT-23 | onsemi | NUP2105LT1G | https://www.mouser.com/ProductDetail/onsemi/NUP2105LT1G?qs=ZXBb0xZ9WeDHmiHN%252BYKtYA%3D%3D | https://www.onsemi.com/pdf/datasheet/nup2105l-d.pdf | N/A | 1
D7,D11,D12,D13 | LED |  |  |  |  | LED_SMD:LED_0603_1608Metric | Lite-On | LTST-C190KRKT | https://www.mouser.com/ProductDetail/LITEON/LTST-C190KRKT?qs=kAD5fFa1n5VY3YYNWPC1Fg%3D%3D | https://optoelectronics.liteon.com/upload/download/DS22-2000-076/LTST-C190KRKT.pdf | N/A | 4
D8,D9,D10 | WS2812B |  |  |  |  | LED_SMD:LED_WS2812B_PLCC4_5.0x5.0mm_P3.2mm | Worldsemi | WS2812B-B/W | https://www.lcsc.com/product-detail/C114586.html | https://cdn-shop.adafruit.com/datasheets/WS2812B.pdf | PCBWay source exact genuine WS2812B-B/W. | 3
D14 | BAV116WS |  |  |  |  | Diode_SMD:D_SOD-323 | Diodes Incorporated | BAV116WS-7 | https://www.mouser.com/ProductDetail/Diodes-Incorporated/BAV116WS-7?qs=icAhCOE9TbhcgJgknCRIgw%3D%3D | https://www.diodes.com/assets/Datasheets/BAV116W.pdf | N/A | 1
D15 | RClamp2451ZA |  |  |  |  |  | Semtech | RCLAMP2451ZATFT | https://www.mouser.com/ProductDetail/Semtech/RCLAMP2451ZATFT?qs=rBWM4%252BvDhIel2swgnRTQsw%3D%3D | https://www.semtech.com/products/circuit-protection/low-capacitance/rclamp2451za | Custom SLP0603P2X3F footprint required. | 1
DS1 | S020BQ01HN |  |  | Excluded from board |  |  | CDTech | S020BQ01HN | https://www.cdtech-display.com/products/2-0-st7789-ips-lcd-display-240x320-580-nits-4-wire-spi/ | https://www.cdtech-display.com/wp-content/uploads/2025/05/S020BQ01HN-V2.0-Specification.pdf | Exact off-board S020BQ01HN display; 12-pin 0.5 mm FPC; pinout verified against CDTech specification V2.0; mates J10 bottom-contact ZIF connector. | 1
FB1,FB2,FB3,FB4,FB5,FB6 | 600 Ω @ 100 MHz |  |  |  |  | Inductor_SMD:L_0402_1005Metric | Murata | BLM15AG601SN1D | https://www.mouser.com/ProductDetail/Murata-Electronics/BLM15AG601SN1D?qs=%2FjCH2pcB5WLSIF5DG9Nbqw%3D%3D | https://pim.murata.com/en-global/pim/details/?partNum=BLM15AG601SN1D | 300 mA rated bead; adequate for the CC1101, Si4463 and LNA supply branches; not for a PA supply path. | 6
FB8 | BLM15PX330SN1D |  |  |  |  | Inductor_SMD:L_0402_1005Metric | Murata | BLM15PX330SN1D | https://www.mouser.com/ProductDetail/Murata-Electronics/BLM15PX330SN1D?qs=eTNEoJdcnEIaTZIPLYO3Ag%3D%3D | https://pim.murata.com/en-us/pim/details/?partNum=BLM15PX330SN1D | 33 Ω @ 100 MHz | 1
FL2,FL9,FL12 | B39321B3722U410 |  |  |  |  | Filter:Filter_SAW_Epcos_DCC6C_3x3mm | TDK/EPCOS | B39321B3722U410 | https://www.mouser.com/ProductDetail/RF360/B39321B3722U410?qs=IZvDGngzxm0rhXkBXpP0BQ%3D%3D | https://product.tdk.com/en/search/rf/rf/saw-filter/info?part_no=B39321B3722U410 | N/A | 3
FL3,FL8,FL11 | B39431B3710U410 |  |  |  |  | Filter:Filter_SAW_Epcos_DCC6C_3x3mm | TDK/EPCOS | B39431B3710U410 | https://www.mouser.com/ProductDetail/RF360/B39431B3710U410?qs=hkeJtpWWodAvZBWtdUV7AQ%3D%3D | https://product.tdk.com/en/search/rf/rf/saw-filter/info?part_no=B39431B3710U410 | N/A | 3
FL4,FL7,FL10 | B39871B3725U410 |  |  |  |  | Filter:Filter_SAW_Epcos_DCC6C_3x3mm | TDK/EPCOS | B39871B3725U410 | https://www.mouser.com/ProductDetail/RF360/B39871B3725U410?qs=7N3YgXRJ4GWPI04hgOE6xw%3D%3D | https://product.tdk.com/en/search/rf/rf/saw-filter/info?part_no=B39871B3725U410 | N/A | 3
J1 | S3B-PH-SM4-TB(LF)(SN) |  |  |  |  | Connector_JST:JST_PH_S3B-PH-SM4-TB_1x03-1MP_P2.00mm_Horizontal | JST Commercial | S3B-PH-SM4-TB(LF)(SN) | https://eu.mouser.com/en/ProductDetail/JST-Commercial/S3B-PH-SM4-TBLFSN?qs=QpmGXVUTftEdG5wplZaokQ%3D%3D | https://www.jst-mfg.com/product/index.php?series=199&lang=2 | Rev-A PCB pinout verified: pin 1 BAT+, pin 2 10k NTC, pin 3 GND. Mates JST PHR-3 using SPH-002T-P0.5S contacts. PROCUREMENT HOLD: battery supplier drawing/sample must confirm cavity order 1=red BAT+, 2=yellow NTC, 3=black GND before purchase. | 1
J2 | M50-3530542 |  |  |  |  | Connector_PinHeader_1.27mm:PinHeader_1x05_P1.27mm_Vertical | Harwin | M50-3530542 | https://eu.mouser.com/en/ProductDetail/Harwin/M50-3530542?qs=%252BdQmOuGyFcHDSISYjHIhxg%3D%3D | https://www.harwin.com/products/M50-3530542 | Rev-A fitted RP2350 SWD connector. Pin 1 SWCLK, pin 2 GND, pin 3 SWDIO, pin 4 +3V3, pin 5 RUN. Unpolarized connector—provide a clear pin-1 silkscreen marker. | 1
J3 | SMA4 |  |  |  |  | Connector_Coaxial:SMA_Amphenol_132289_EdgeMount | Amphenol RF | 132289 | https://www.mouser.com/ProductDetail/Amphenol-RF/132289?qs=nhkRCwpTkeb9ti20UXE5Cg%3D%3D | https://www.amphenolrf.com/en-us/part/132289/1030/ | Manual/post-reflow SMA assembly. | 1
J4 | SMA1_CH-A_50R |  |  |  |  | Connector_Coaxial:SMA_Amphenol_132289_EdgeMount | Amphenol RF | 132289 | https://www.mouser.com/ProductDetail/Amphenol-RF/132289?qs=nhkRCwpTkeb9ti20UXE5Cg%3D%3D | https://www.amphenolrf.com/en-us/part/132289/1030/ | Manual/post-reflow SMA assembly. | 1
J5 | SMA2_CH-B_50R |  |  |  |  | Connector_Coaxial:SMA_Amphenol_132289_EdgeMount | Amphenol RF | 132289 | https://www.mouser.com/ProductDetail/Amphenol-RF/132289?qs=nhkRCwpTkeb9ti20UXE5Cg%3D%3D | https://www.amphenolrf.com/en-us/part/132289/1030/ | Manual/post-reflow SMA assembly. | 1
J6 | SMA3_CH-C_50R |  |  |  |  | Connector_Coaxial:SMA_Amphenol_132289_EdgeMount | Amphenol RF | 132289 | https://www.mouser.com/ProductDetail/Amphenol-RF/132289?qs=nhkRCwpTkeb9ti20UXE5Cg%3D%3D | https://www.amphenolrf.com/en-us/part/132289/1030/ | Manual/post-reflow SMA assembly. | 1
J7 | USB4085-GF-A_REVA4 |  |  |  |  | USB4085:GCT_USB4085-GF-A_REVA4 | GCT | USB4085-GF-A | https://www.mouser.com/ProductDetail/GCT/USB4085-GF-A?qs=KUoIvG%2F9Ilba1bQOahfWjw%3D%3D | https://gct.co/connector/usb4085 | PCBWay: inspect USB-C shell soldering. | 1
J8 | USB_A |  |  |  |  | Connector_USB:USB_A_Molex_67643_Horizontal | Molex | 67643-3910 | https://www.mouser.com/ProductDetail/Molex/67643-3910?qs=x6EjVpvqMVPR04zsu4B0aw%3D%3D | https://www.molex.com/en-us/products/part-detail/676433910 | PCBWay: manual/THT soldering likely. | 1
J9 | SM04B-GHS-TB(LF)(SN) |  |  |  |  | Connector_JST:JST_GH_SM04B-GHS-TB_1x04-1MP_P1.25mm_Horizontal | JST | SM04B-GHS-TB(LF)(SN) | https://www.mouser.com/ProductDetail/JST-Commercial/SM04B-GHS-TBLFSN?qs=QpmGXVUTftGayLYZQBIuZw%3D%3D | https://www.jst-mfg.com/product/pdf/eng/eGH.pdf | Frozen Rev-A pinout: pin 1 NC, pin 2 CANH, pin 3 CANL, pin 4 GND. Mates GHR-04V-S. Fit three SSHL-002T-P0.2 contacts in cavities 2–4; cavity 1 remains empty. | 1
J9C1,J9C2,J9C3 | J9 female crimp contact |  |  | Excluded from board |  |  | JST | SSHL-002T-P0.2 | https://eu.mouser.com/en/ProductDetail/JST-Commercial/SSHL-002T-P0.2?qs=QpmGXVUTftFqcHd8IzS44Q%3D%3D | https://www.jst-mfg.com/product/index.php?series=105&lang=2 | 26–30 AWG female crimp contact for GHR-04V-S. | 3
J9M1 | J9 mating housing, 4-position |  |  | Excluded from board |  |  | JST | GHR-04V-S | https://eu.mouser.com/en/ProductDetail/JST-Commercial/GHR-04V-S?qs=QpmGXVUTftH03s%252BzDgIkKA%3D%3D | https://www.jst-mfg.com/product/index.php?series=105&lang=2 | Cable-side housing mating J9. Pin 1 NC, Pin 2 CANH, Pin 3 CANL, Pin 4 GND. | 1
J10 | FH12-12S-0.5SH(55) |  |  |  |  | Connector_FFC-FPC:Hirose_FH12-12S-0.5SH_1x12-1MP_P0.50mm_Horizontal | Hirose | FH12-12S-0.5SH(55) | https://eu.mouser.com/en/ProductDetail/Hirose-Connector/FH12-12S-0.5SH55?qs=Ux3WWAnHpjA1i1nP49r1%2FQ%3D%3D | https://www.hirose.com/product/p/CL0586-0704-0-55 | Verified CDTech-recommended connector for S020BQ01HN; bottom-contact ZIF; 12 positions; 0.5 mm pitch; 0.30 mm FPC; horizontal insertion. | 1
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

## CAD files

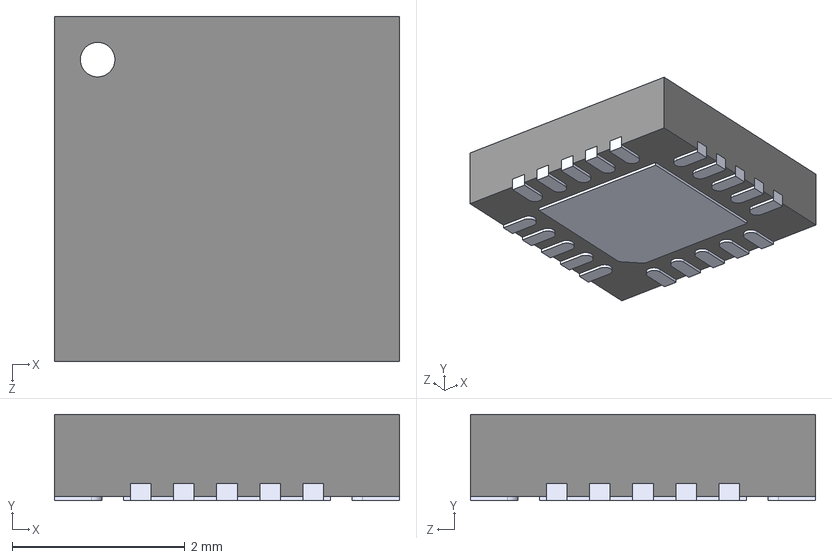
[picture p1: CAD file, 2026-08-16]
Custom_Components/CC/CC1101RGPR/CC1101RGPR.step
4.00 x 1.00 x 4.00 mm

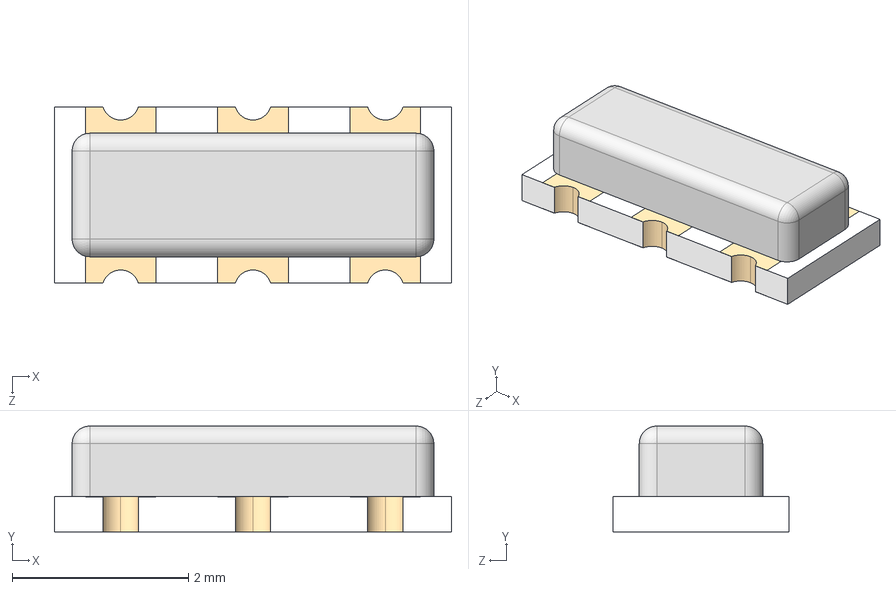
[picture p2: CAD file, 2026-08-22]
Custom_Components/CS/CSTCR4M00G55B-R0/CSTCR4M00G55B-R0.step
4.50 x 1.20 x 2.00 mm

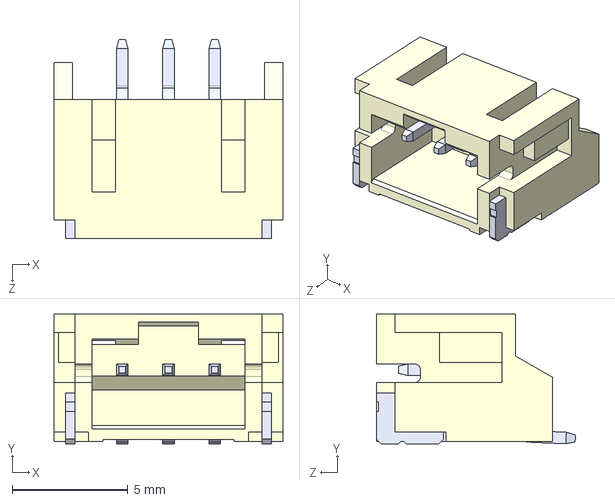
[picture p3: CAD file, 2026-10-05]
Custom_Components/FOBtool_Custom/3dmodels/S3B-PH-SM4-TB--3DModel-STEP-269445.STEP
9.90 x 5.60 x 8.60 mm

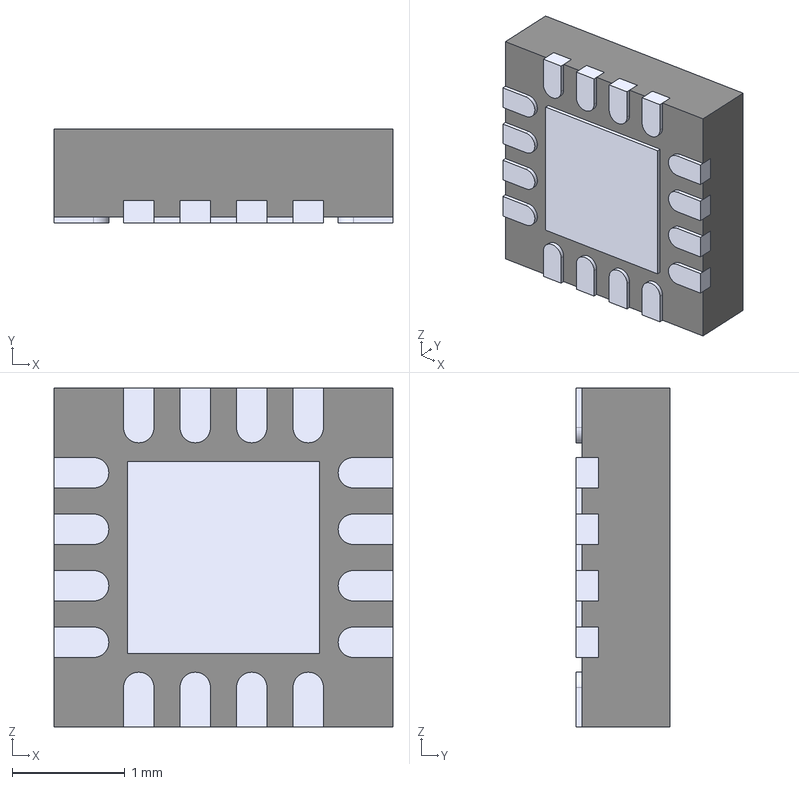
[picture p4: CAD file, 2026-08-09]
Custom_Components/LT/LT3154AV_TRPBF/LT3154AV_TRPBF.step
3.00 x 0.83 x 3.00 mm
Body_Solid1
Body001_Solid1
Array_Solid1 x 4
Array001_Solid2 x 3
Body002_Solid1
Array002_Solid1 x 4
Array003_Solid2 x 3
Body003_Solid1
Body004_Solid1

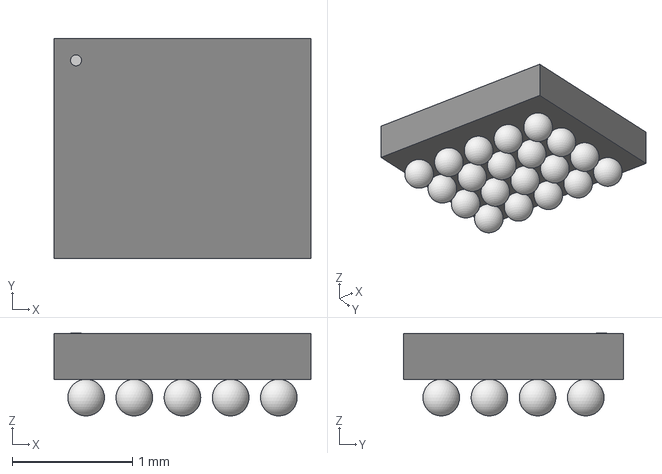
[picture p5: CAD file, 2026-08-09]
Custom_Components/MAX/MAX77816DEWP_T/21-0771A_W201F21_MXM.step
2.13 x 1.83 x 0.688 mm

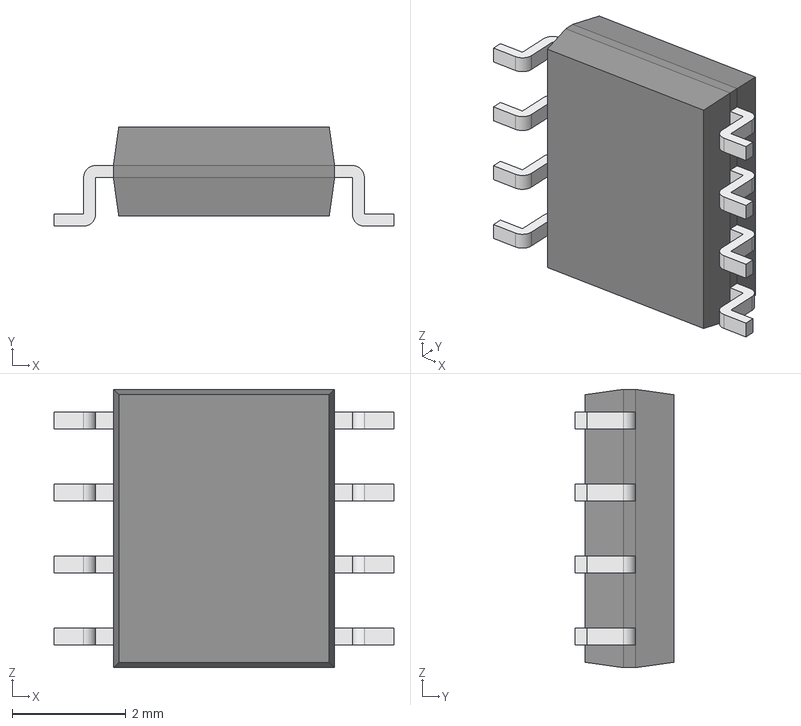
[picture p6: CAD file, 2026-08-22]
Custom_Components/SN/SN65HVD230D/SN65HVD230D.step
5.99 x 1.75 x 4.91 mm
Body001 (Mirror #1) x 4
XY-plane x 12
X-axis x 12

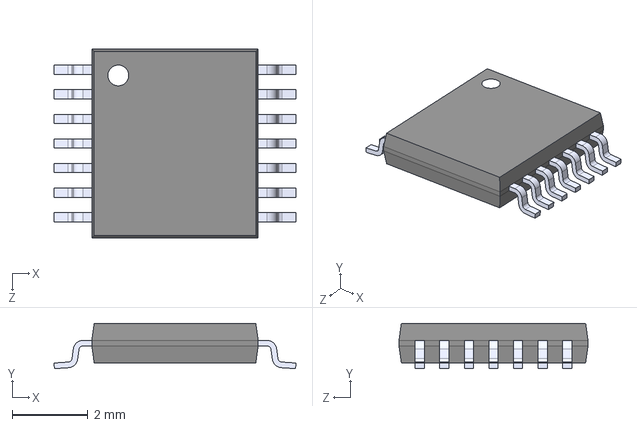
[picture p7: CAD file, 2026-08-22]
Custom_Components/SN/SN74AHCT00PWR/SN74AHCT00PWR.step
6.40 x 1.20 x 5.00 mm

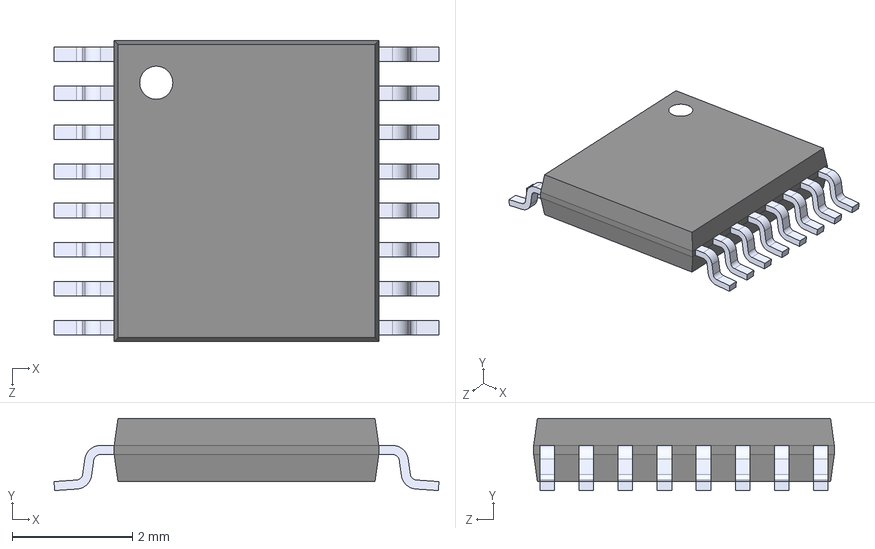
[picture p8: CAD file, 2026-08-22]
Custom_Components/SN/SN74LVC157APWR/SN74LVC157APWR.step
6.40 x 1.20 x 5.00 mm

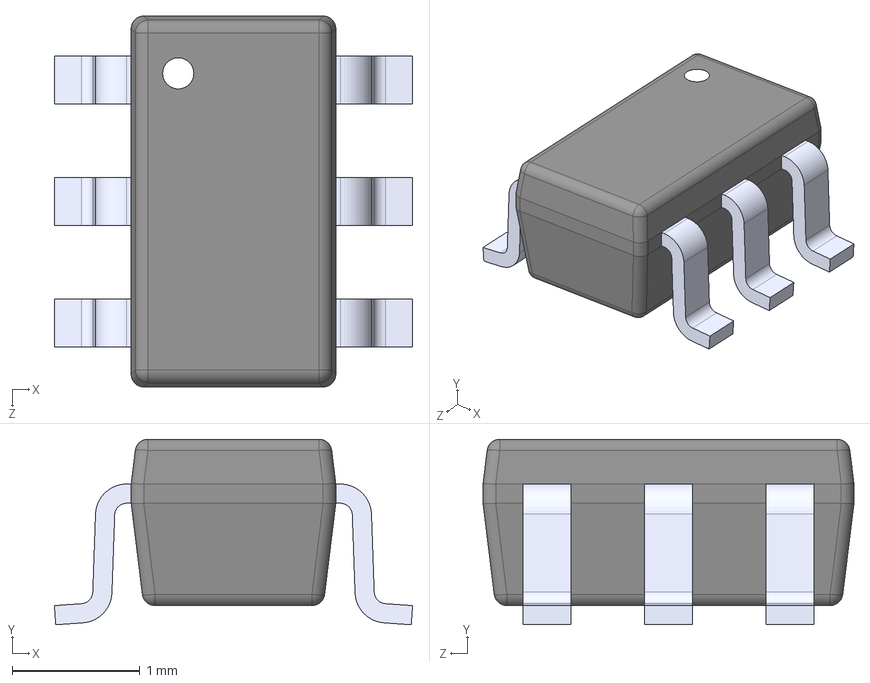
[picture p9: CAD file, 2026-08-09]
Custom_Components/TPS/TPS2553DBVR/TPS2553DBVR.step
2.80 x 1.45 x 2.90 mm

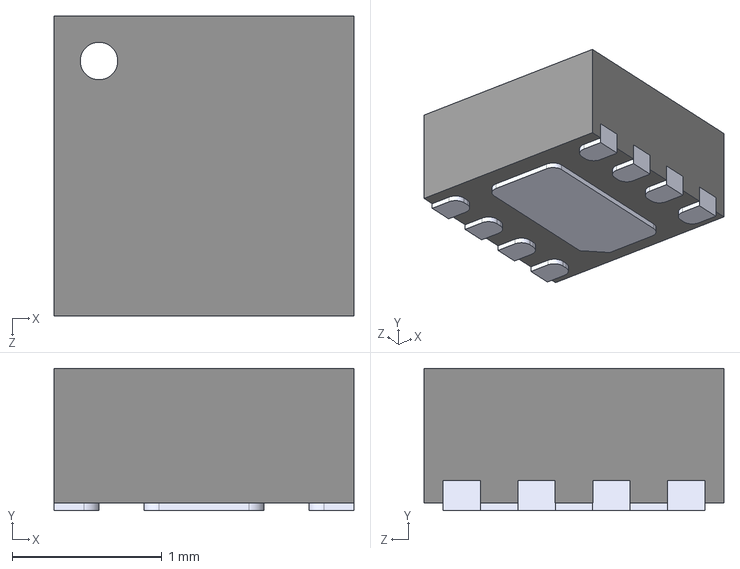
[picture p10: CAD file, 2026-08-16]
Custom_Components/TQP/TQP3M9036/TQP3M9036.step
2.00 x 0.95 x 2.00 mm

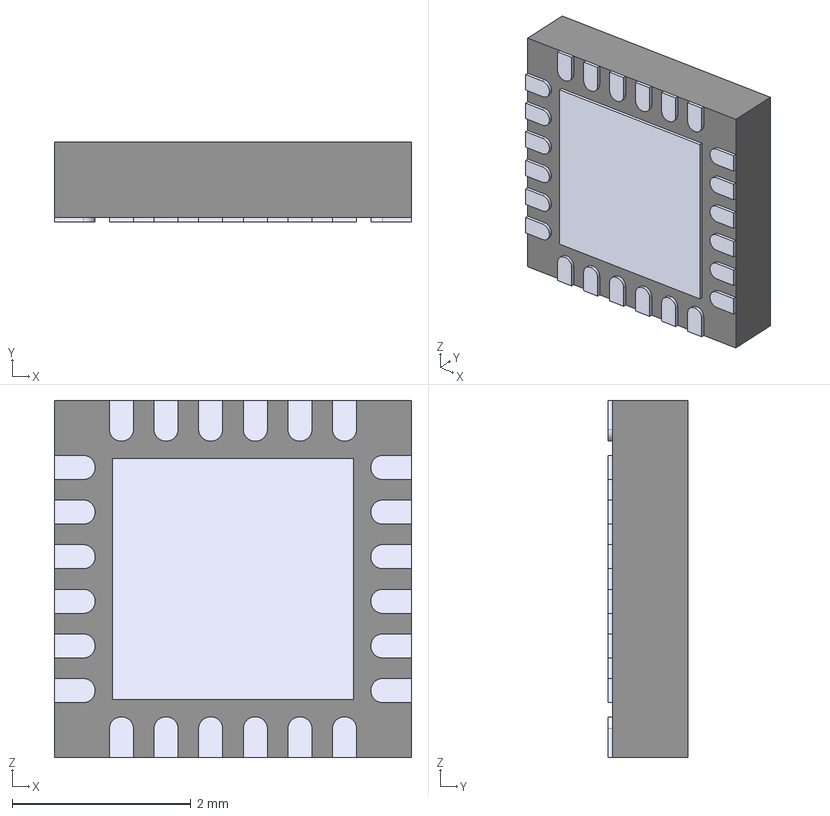
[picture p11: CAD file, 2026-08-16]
Custom_Components/TQP/TQP7M9106/TQP7M9106.step
4.00 x 0.9 x 4.00 mm
BaseWithTopCut
TopCircle_NewBody

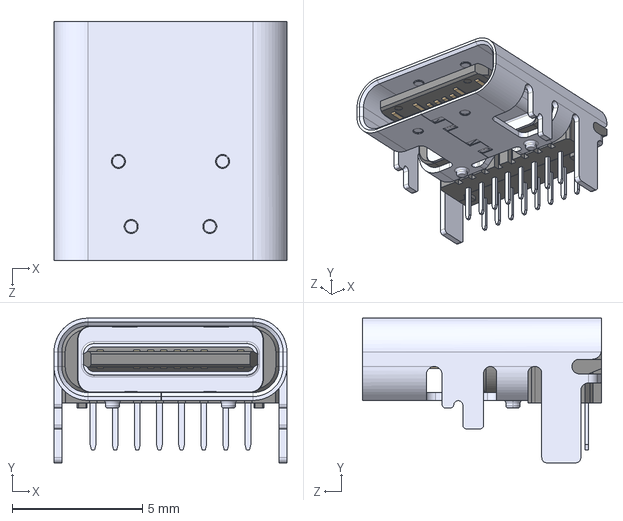
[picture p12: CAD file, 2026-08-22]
Custom_Components/USB/USB4085-GF-A_REVA4/USB4085-GF-A_REVA4.step
8.95 x 5.56 x 9.17 mm

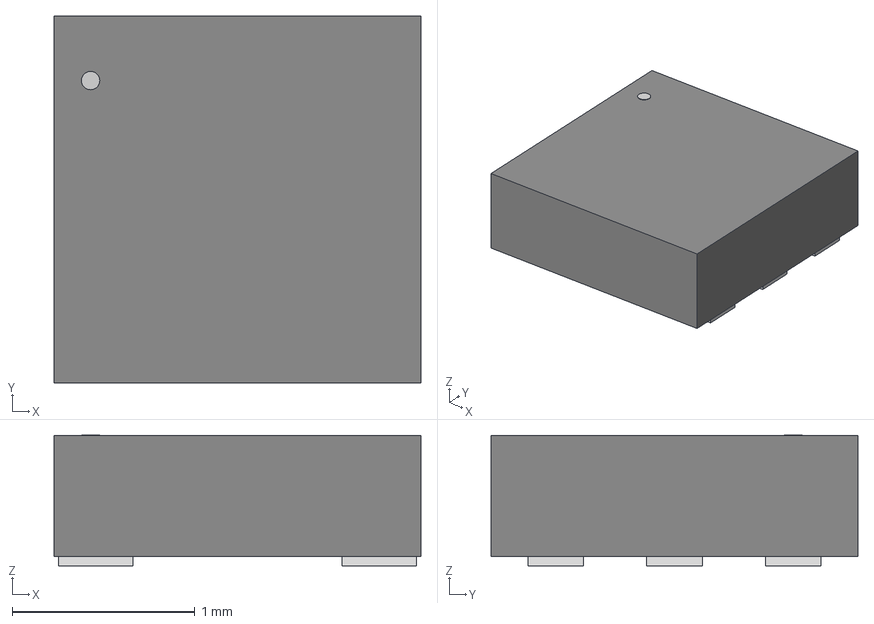
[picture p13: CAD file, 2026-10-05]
Custom_Components/FOBtool_Custom/3dmodels/LTR-303ALS-01_LTO.step
2.01 x 2.01 x 0.714 mm

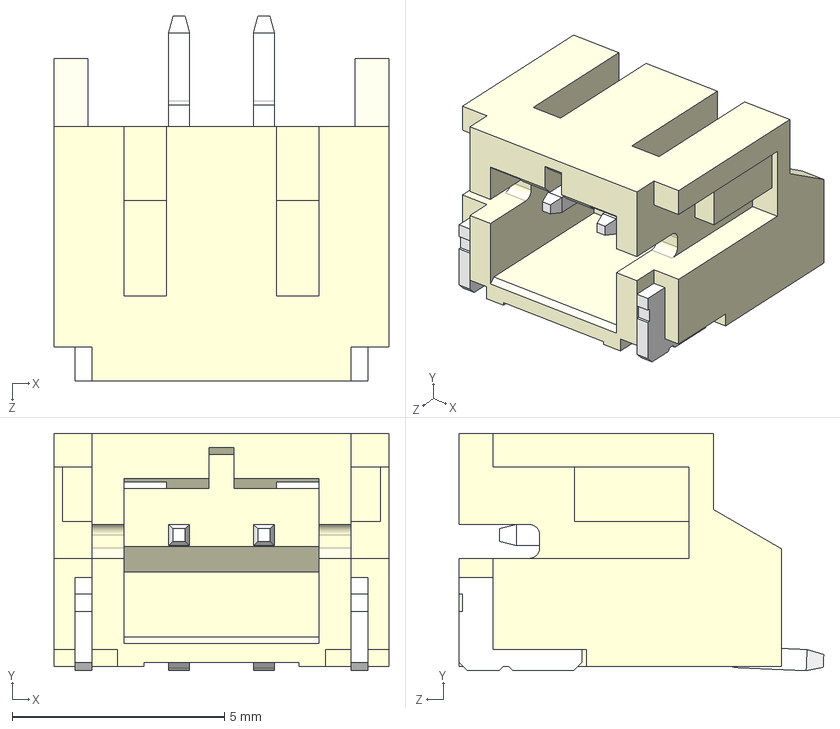
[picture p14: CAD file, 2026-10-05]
Custom_Components/FOBtool_Custom/3dmodels/S2B-PH-SM4-TB(LF)(SN)--3DModel-STEP-56544.STEP
7.90 x 5.60 x 8.60 mm

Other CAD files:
Custom_Components/FOBtool_Custom/3dmodels/PN7160B1HN_C100E.stp
Custom_Components/FOBtool_Custom/3dmodels/MAX-M10N-10B.stp
Custom_Components/FOBtool_Custom/3dmodels/rpi_rp2350a.step
Custom_Components/FOBtool_Custom/3dmodels/SLP0603P2X3F_SEM.step
Custom_Components/1054/1054301103/1054301103.step
Custom_Components/FOBtool_Custom/3dmodels/1040310811.stp
Custom_Components/FOBtool_Custom/3dmodels/1053071203.stp
Custom_Components/FOBtool_Custom/3dmodels/AOTA-B201610S3R3-101-T--3DModel-STEP-510211.STEP
Custom_Components/FOBtool_Custom/3dmodels/BD0826J50200AHF.stp
Custom_Components/FOBtool_Custom/3dmodels/BGS13SN8E6327XTSA1.stp
Custom_Components/FOBtool_Custom/3dmodels/CPH3225A.step
Custom_Components/FOBtool_Custom/3dmodels/EEFLR0J680R.step
Custom_Components/FOBtool_Custom/3dmodels/EEFTX0J121RF.step
Custom_Components/FOBtool_Custom/3dmodels/LQH44PN150MPRL.step
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

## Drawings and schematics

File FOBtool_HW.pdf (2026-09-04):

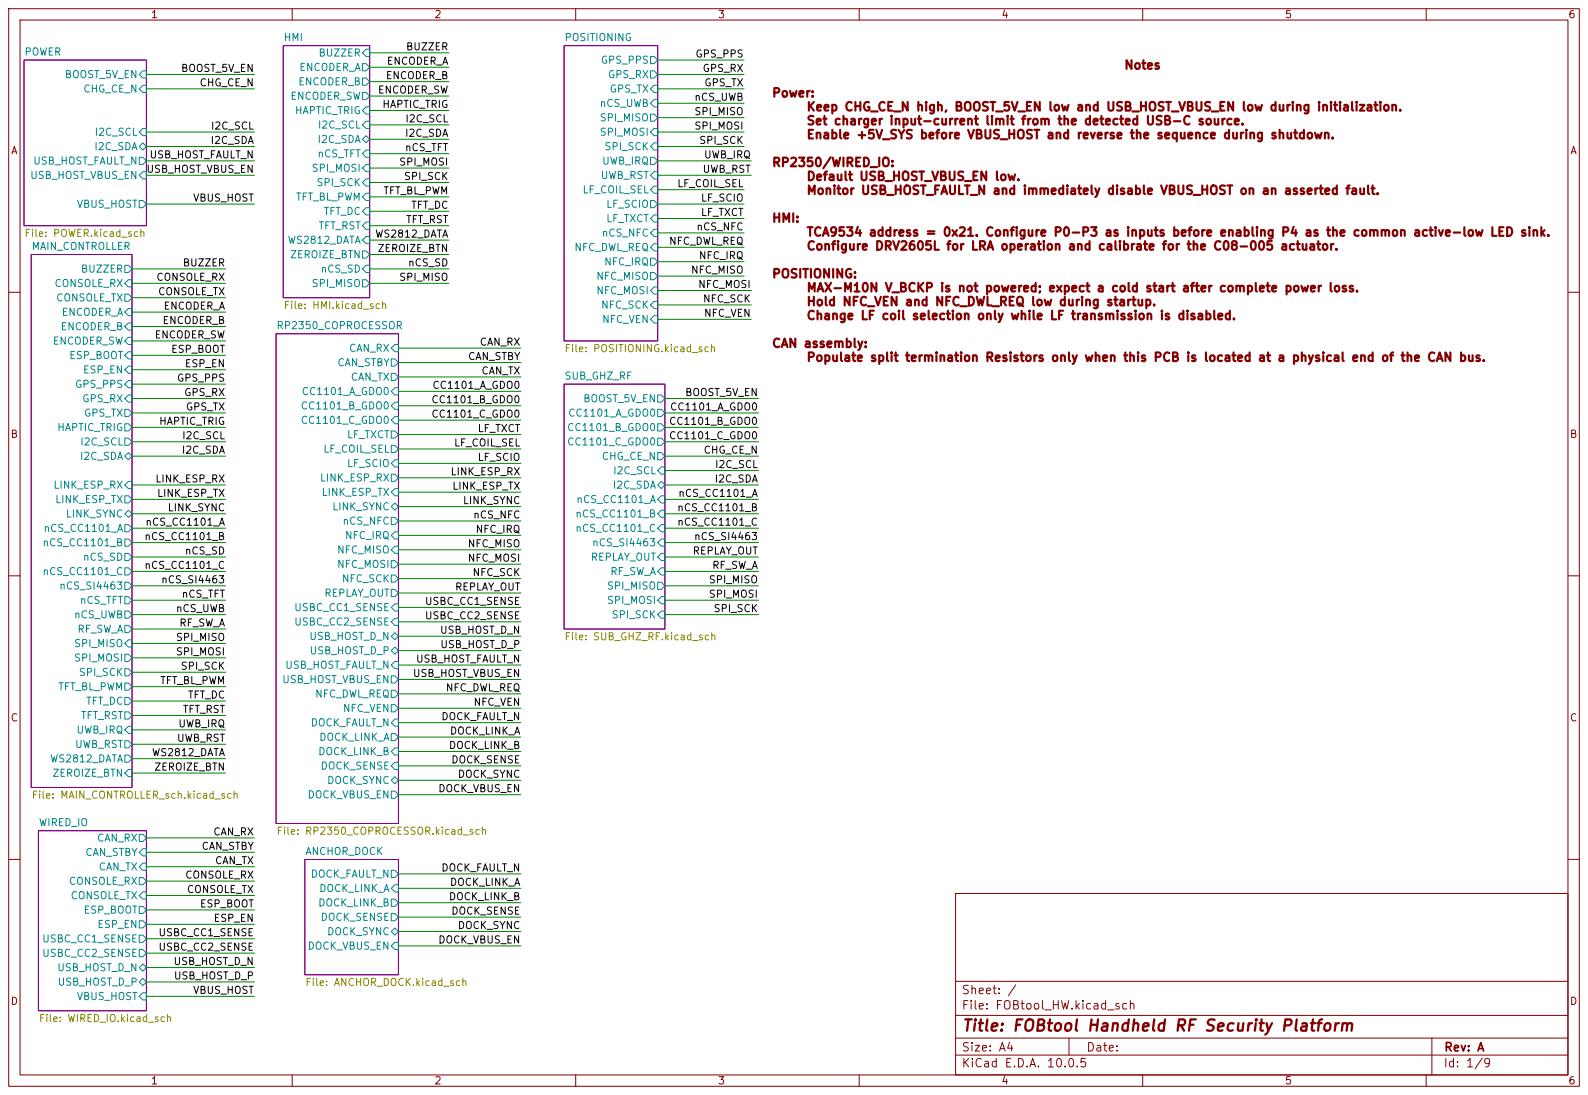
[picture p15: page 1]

Power:
Keep CHG_CE_N high, BOOST_5V_EN low and USB_HOST_VBUS_EN low during initialization.
Set charger input-current limit from the detected USB-C source. Enable +5V_SYS before VBUS_HOST and reverse the sequence during shutdown.

RP2350/WIRED_IO:
Default USB_HOST_VBUS_EN low.
Monitor USB_HOST_FAULT_N and immediately disable VBUS_HOST on an asserted fault.
NFC_MOSI CHG_CE_N

HMI:
TCA9534 address = 0x21. Configure P0-P3 as inputs before enabling P4 as the common active-low LED sink.
Configure DRV2605L for LRA operation and calibrate for the C08-005 actuator.

POSITIONING:
MAX-M10N V_BCKP is not powered; expect a cold start after complete power loss.
Hold NFC_VEN and NFC_DWL_REQ low during startup.
Change LF coil selection only while LF transmission is disabled.

CAN assembly:
Populate split termination Resistors only when this PCB is located at a physical end of the CAN bus.

Sheet: /
File: FOBtool_HW.kicad_sch
Title: FOBtool Handheld RF Security Platform

Size: A4 | Rev: A
KiCad E.D.A. 10.0.5 | Id: 1/9

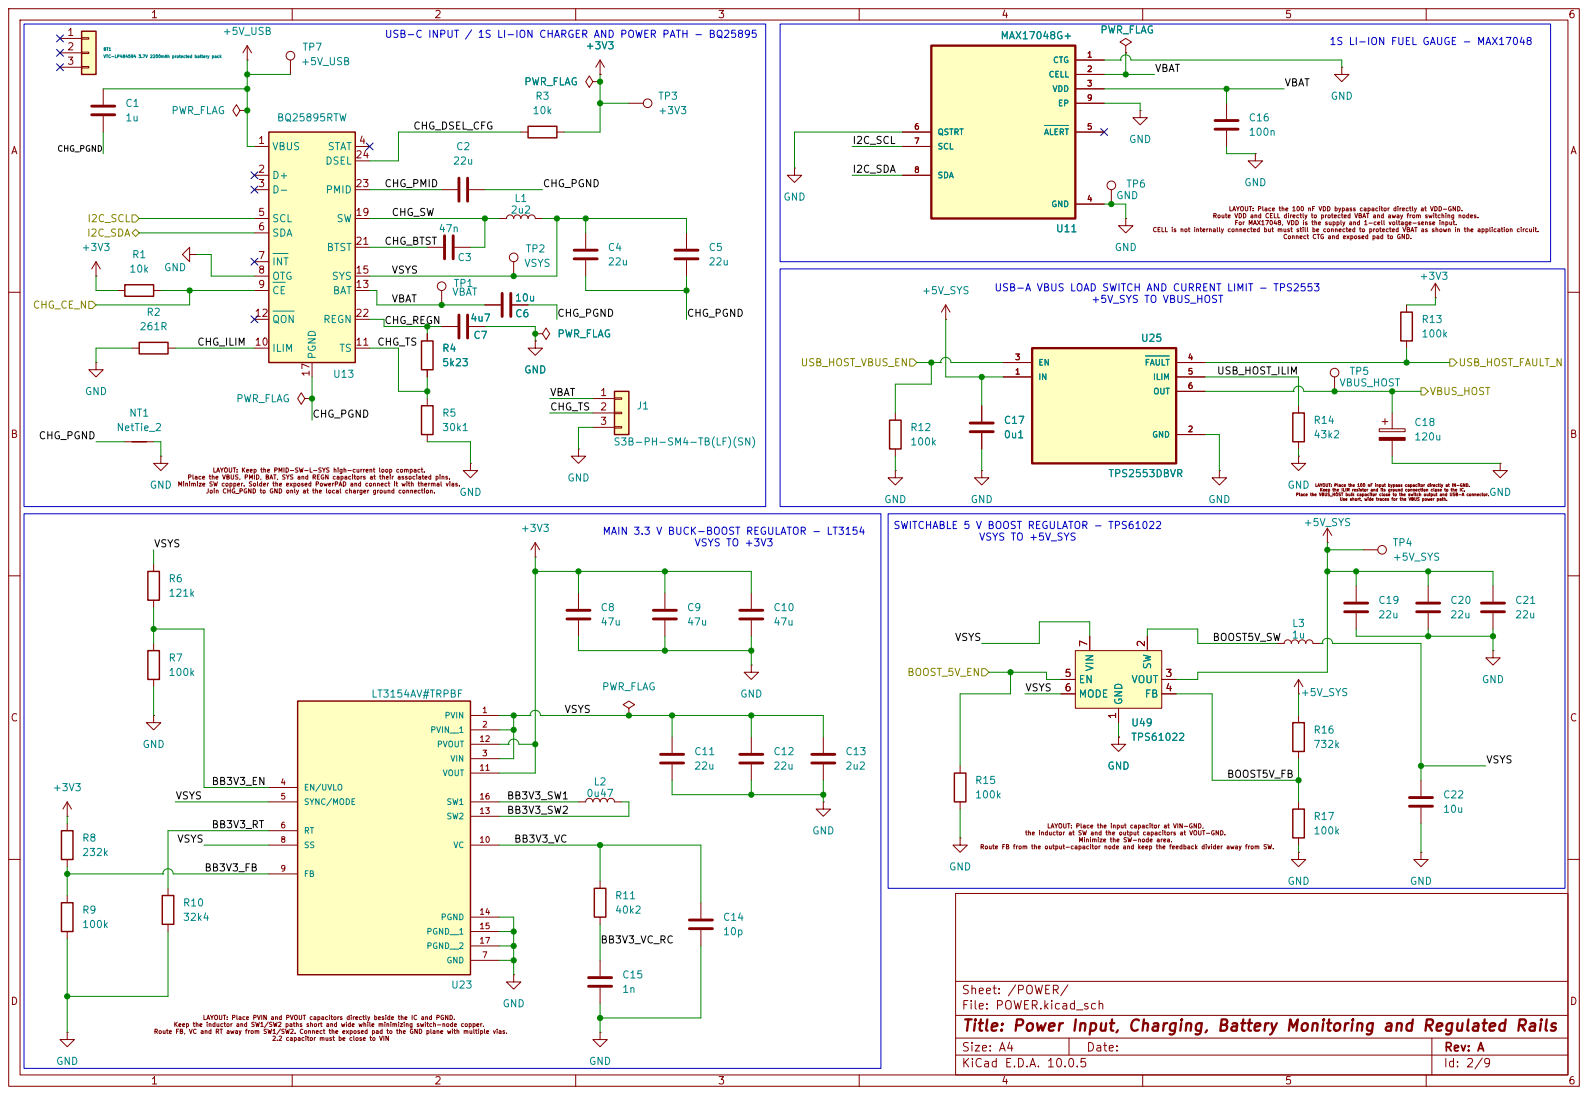
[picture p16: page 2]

0u1 +5V_USB
SW 19 BTST 21 REGN 22 PMID 23 DSEL 24 U13 BQ25895RTW

USB-C INPUT / 1S LI-ION CHARGER AND POWER PATH - BQ25895

VBAT VSYS

LAYOUT: Place the 100 nF VDD bypass capacitor directly at VDD-GND. Route VDD and CELL directly to protected VBAT and away from switching nodes. For MAX17048, VDD is the supply and 1-cell voltage-sense input. CELL is not internally connected but must still be connected to protected VBAT as shown in the application circuit. Connect CTG and exposed pad to GND. 1S LI-ION FUEL GAUGE - MAX17048 C6

VSYS TO +5V_SYS USB-A VBUS LOAD SWITCH AND CURRENT LIMIT - TPS2553 +5V_SYS TO VBUS_HOST

LAYOUT: Place the 100 nF input bypass capacitor directly at IN-GND. Keep the ILIM resistor and its ground connection close to the IC. Place the VBUS_HOST bulk capacitor close to the switch output and USB-A connector. Use short, wide traces for the VBUS power path. LAYOUT: Keep the PMID-SW-L-SYS high-current loop compact. Place the VBUS, PMID, BAT, SYS and REGN capacitors at their associated pins. Minimize SW copper. Solder the exposed PowerPAD and connect it with thermal vias.

LAYOUT: Place the input capacitor at VIN-GND,

the inductor at SW and the output capacitors at VOUT-GND. Minimize the SW-node area. Route FB from the output-capacitor node and keep the feedback divider away from SW.

Sheet: /POWER/
File: POWER.kicad_sch
Title: Power Input, Charging, Battery Monitoring and Regulated Rails

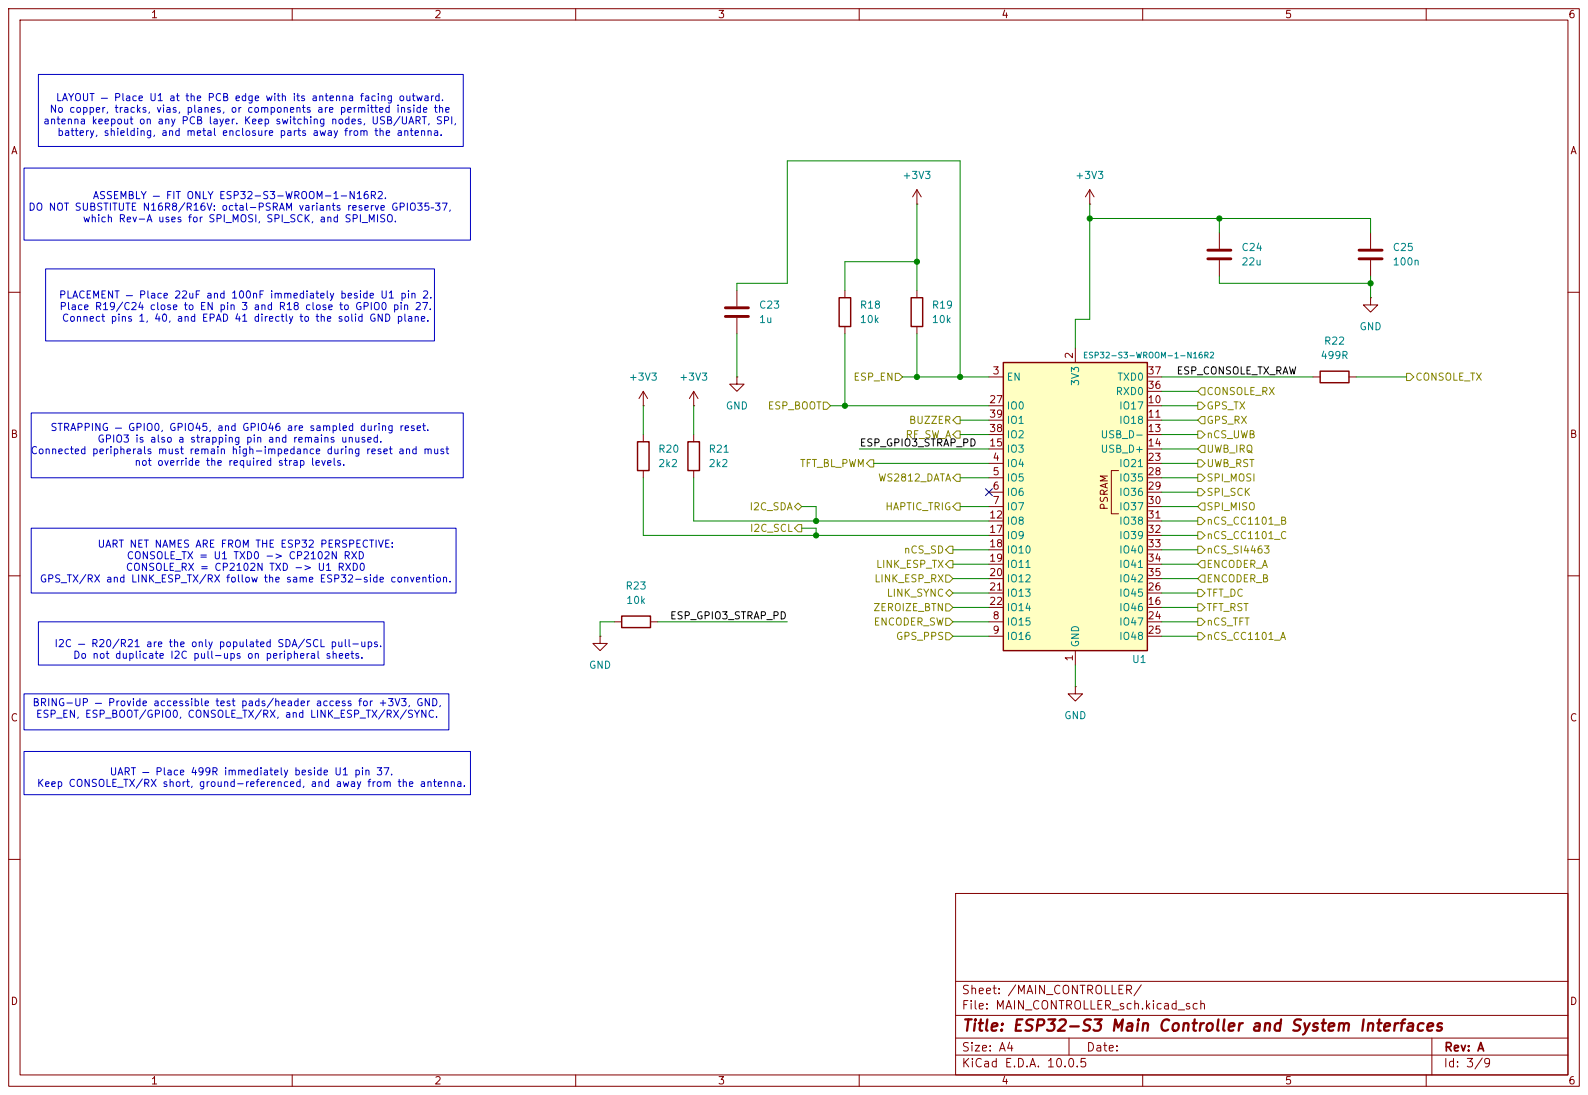
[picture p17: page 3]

LAYOUT — Place U1 at the PCB edge with its antenna facing outward. No copper, tracks, vias, planes, or components are permitted inside the antenna keepout on any PCB layer. Keep switching nodes, USB/UART, SPI,

battery, shielding, and metal enclosure parts away from the antenna. PLACEMENT — Place 22uF and 100nF immediately beside U1 pin 2. Place R19/C24 close to EN pin 3 and R18 close to GPIO0 pin 27. Connect pins 1, 40, and EPAD 41 directly to the solid GND plane.

ASSEMBLY — FIT ONLY ESP32-S3-WROOM-1-N16R2. DO NOT SUBSTITUTE N16R8/R16V: octal-PSRAM variants reserve GPIO35–37, which Rev-A uses for SPI_MOSI, SPI_SCK, and SPI_MISO. BRING-UP — Provide accessible test pads/header access for +3V3, GND,

I2C — R20/R21 are the only populated SDA/SCL pull-ups. Do not duplicate I2C pull-ups on peripheral sheets. STRAPPING — GPIO0, GPIO45, and GPIO46 are sampled during reset. GPIO3 is also a strapping pin and remains unused. Connected peripherals must remain high-impedance during reset and must not override the required strap levels.

ESP_GPIO3_STRAP_PD UART NET NAMES ARE FROM THE ESP32 PERSPECTIVE: CONSOLE_TX = U1 TXD0 -> CP2102N RXD

CONSOLE_RX = CP2102N TXD -> U1 RXD0 GPS_TX/RX and LINK_ESP_TX/RX follow the same ESP32-side convention. UART — Place 499R immediately beside U1 pin 37. Keep CONSOLE_TX/RX short, ground-referenced, and away from the antenna.

ESP_EN, ESP_BOOT/GPIO0, CONSOLE_TX/RX, and LINK_ESP_TX/RX/SYNC.

Sheet: /MAIN_CONTROLLER/
File: MAIN_CONTROLLER_sch.kicad_sch
Title: ESP32-S3 Main Controller and System Interfaces

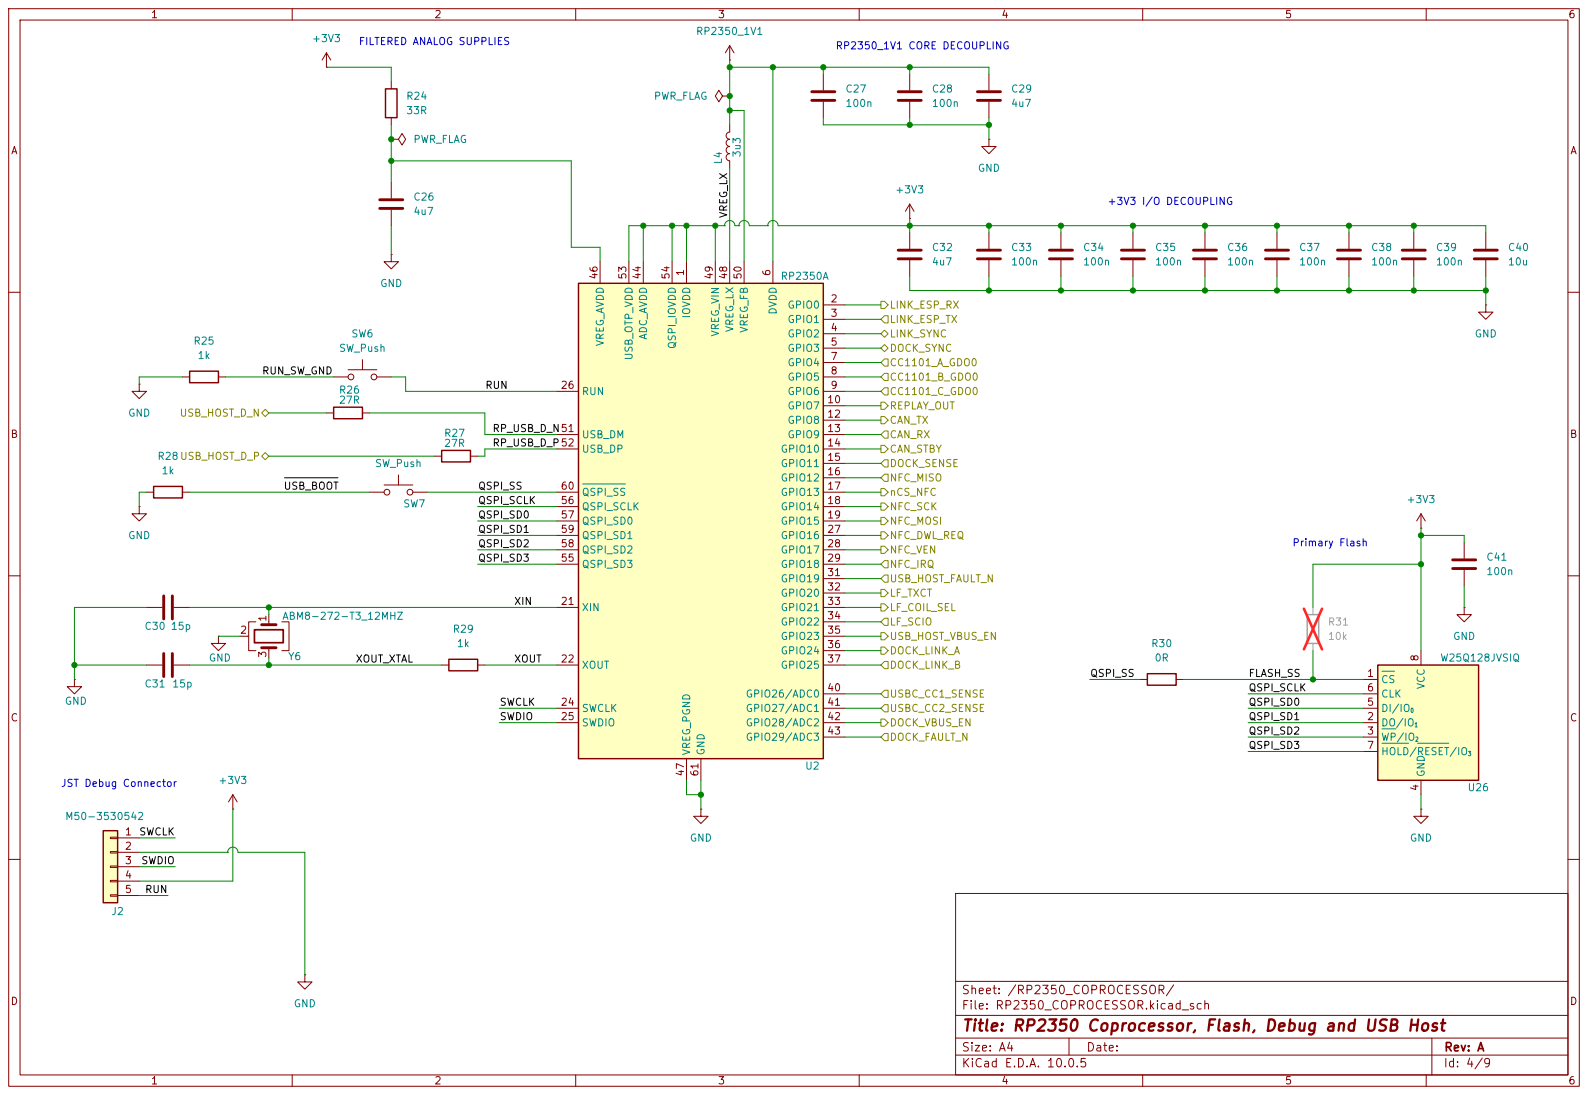
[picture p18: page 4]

4 DI/IO0 5 CLK 6 HOLD/RESET/IO3 7 VCC

Sheet: /RP2350_COPROCESSOR/
File: RP2350_COPROCESSOR.kicad_sch
Title: RP2350 Coprocessor, Flash, Debug and USB Host

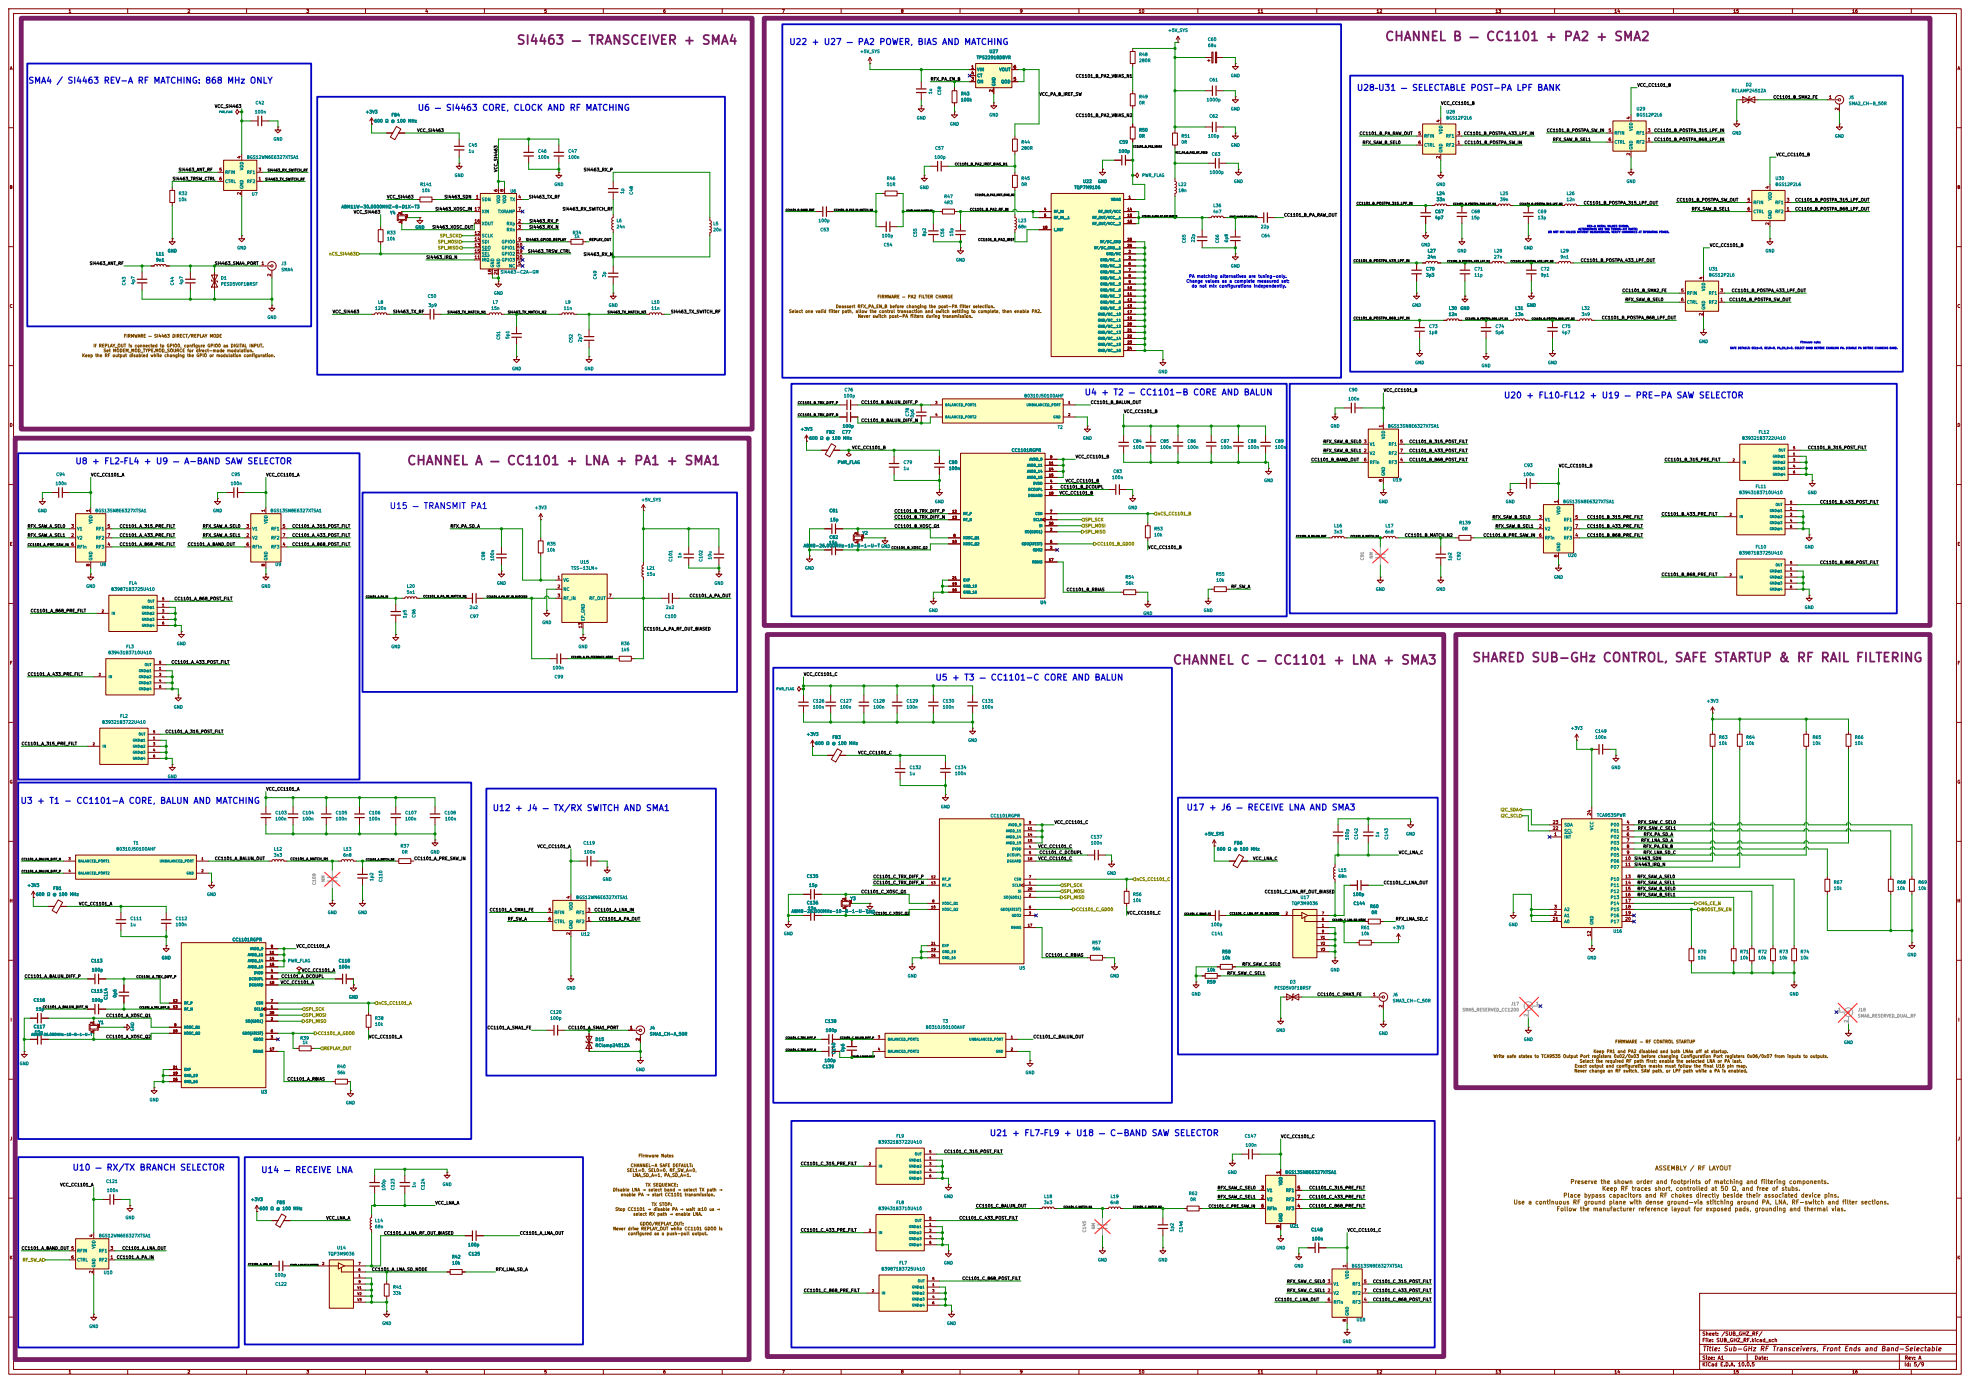
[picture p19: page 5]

REV-A INITIAL VALUES SHOWN. ALTERNATIVES ARE VNA TUNING-KIT PARTS; DO NOT MIX VALUES WITHOUT MEASUREMENT. VERIFY HARMONICS AT OPERATING POWER. CHANNEL B — CC1101 + PA2 + SMA2

U22 + U27 — PA2 POWER, BIAS AND MATCHING
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

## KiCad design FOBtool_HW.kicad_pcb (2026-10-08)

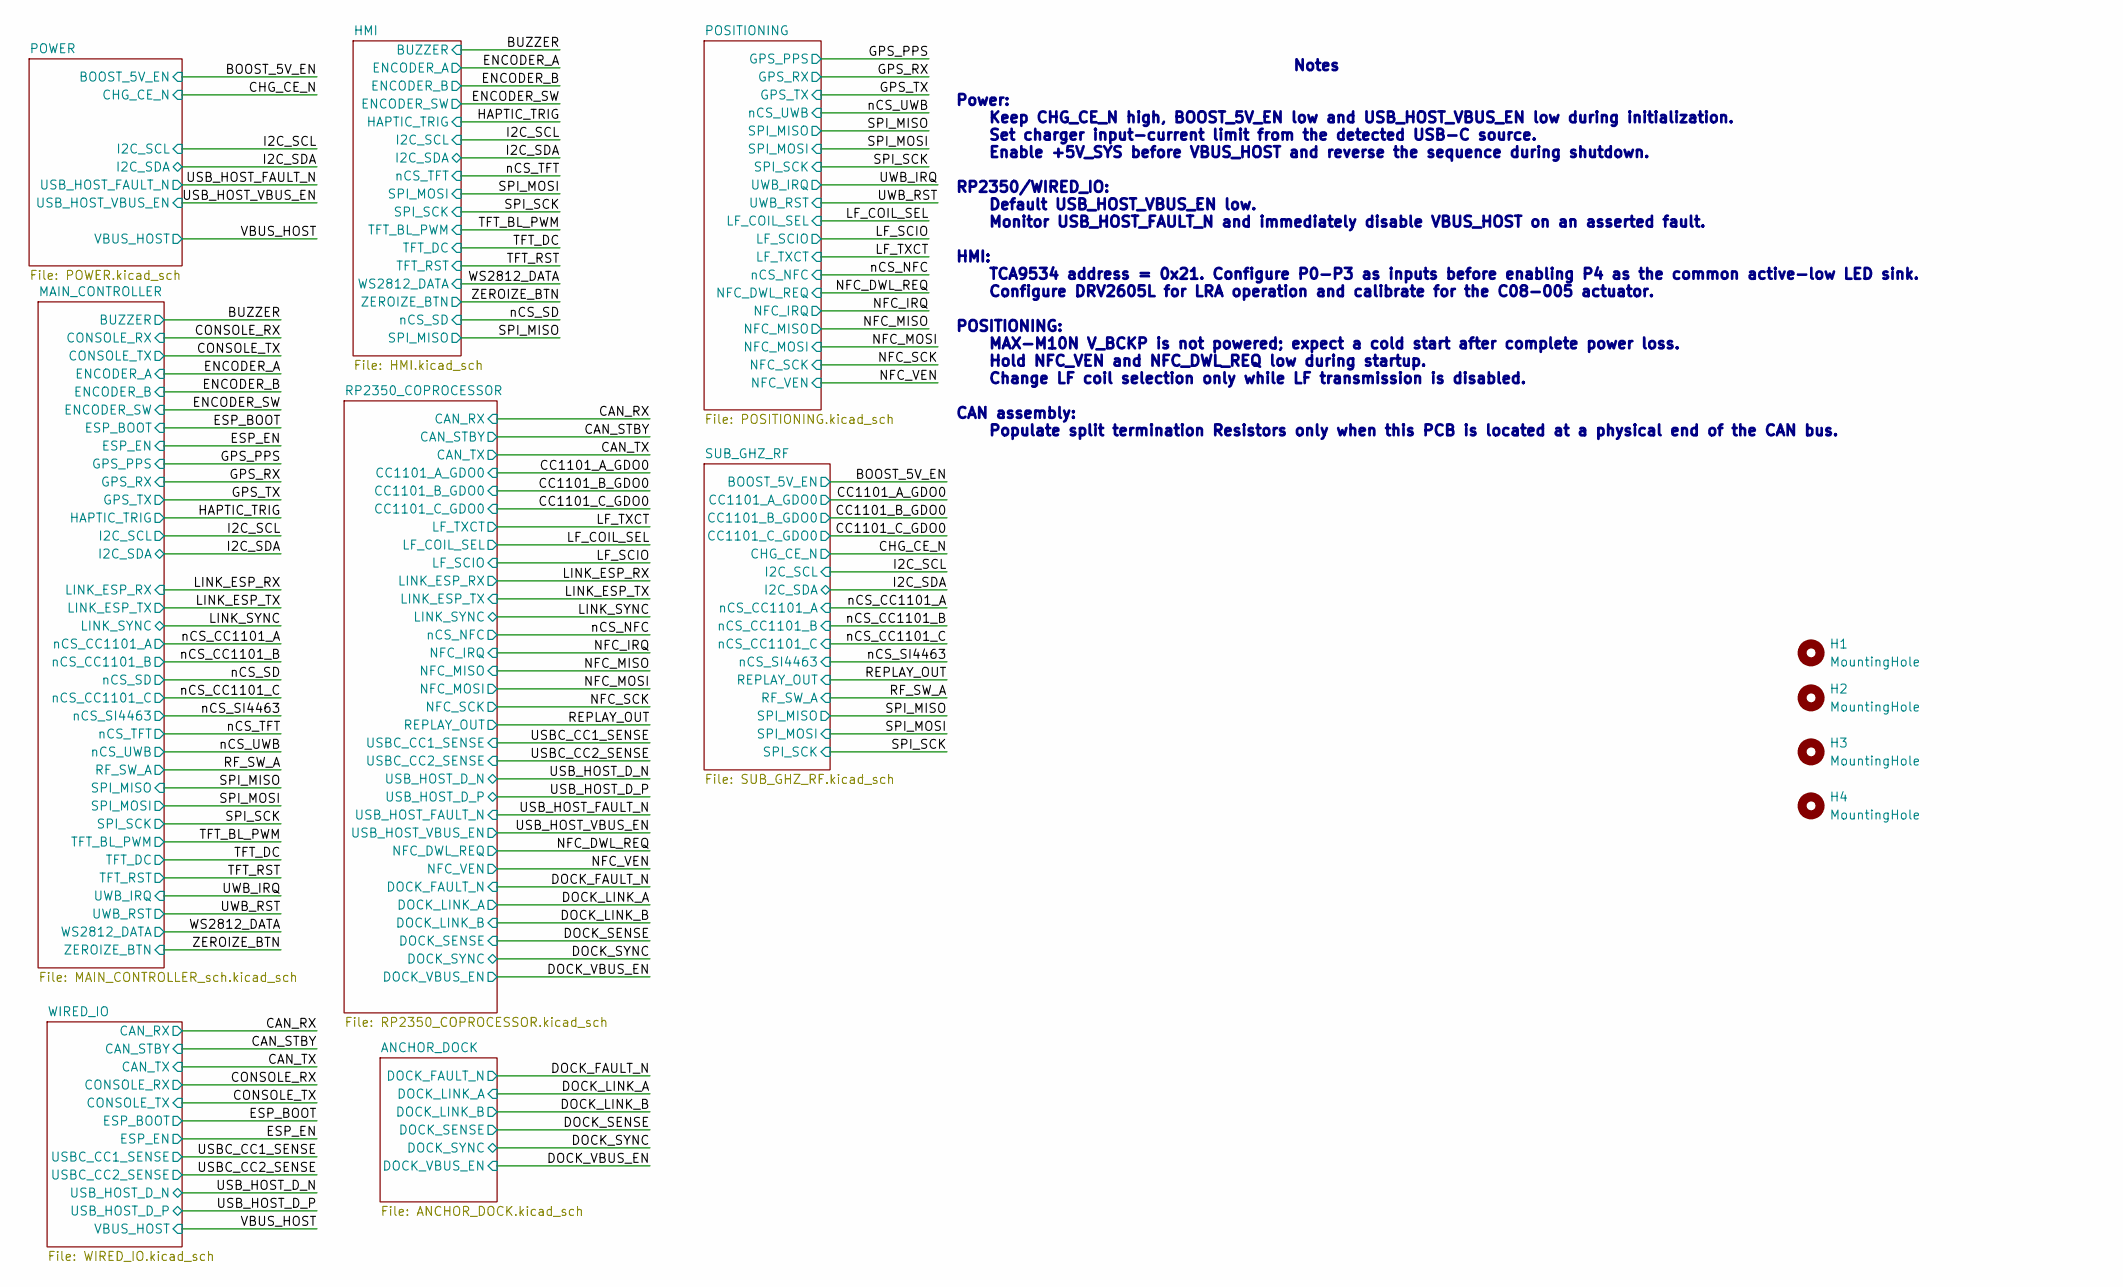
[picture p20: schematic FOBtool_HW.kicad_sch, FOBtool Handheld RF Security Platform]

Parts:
H1, H2, H3, H4: MountingHole; MountingHole_2.2mm_M2

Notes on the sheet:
Notes Power: Keep CHG_CE_N high, BOOST_5V_EN low and USB_HOST_VBUS_EN low during initialization. Set charger input-current limit from the detected USB-C source. Enable +5V_SYS before VBUS_HOST and reverse the sequence during shutdown. RP2350/WIRED_IO: Default USB_HOST_VBUS_EN low. Monitor USB_HOST_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

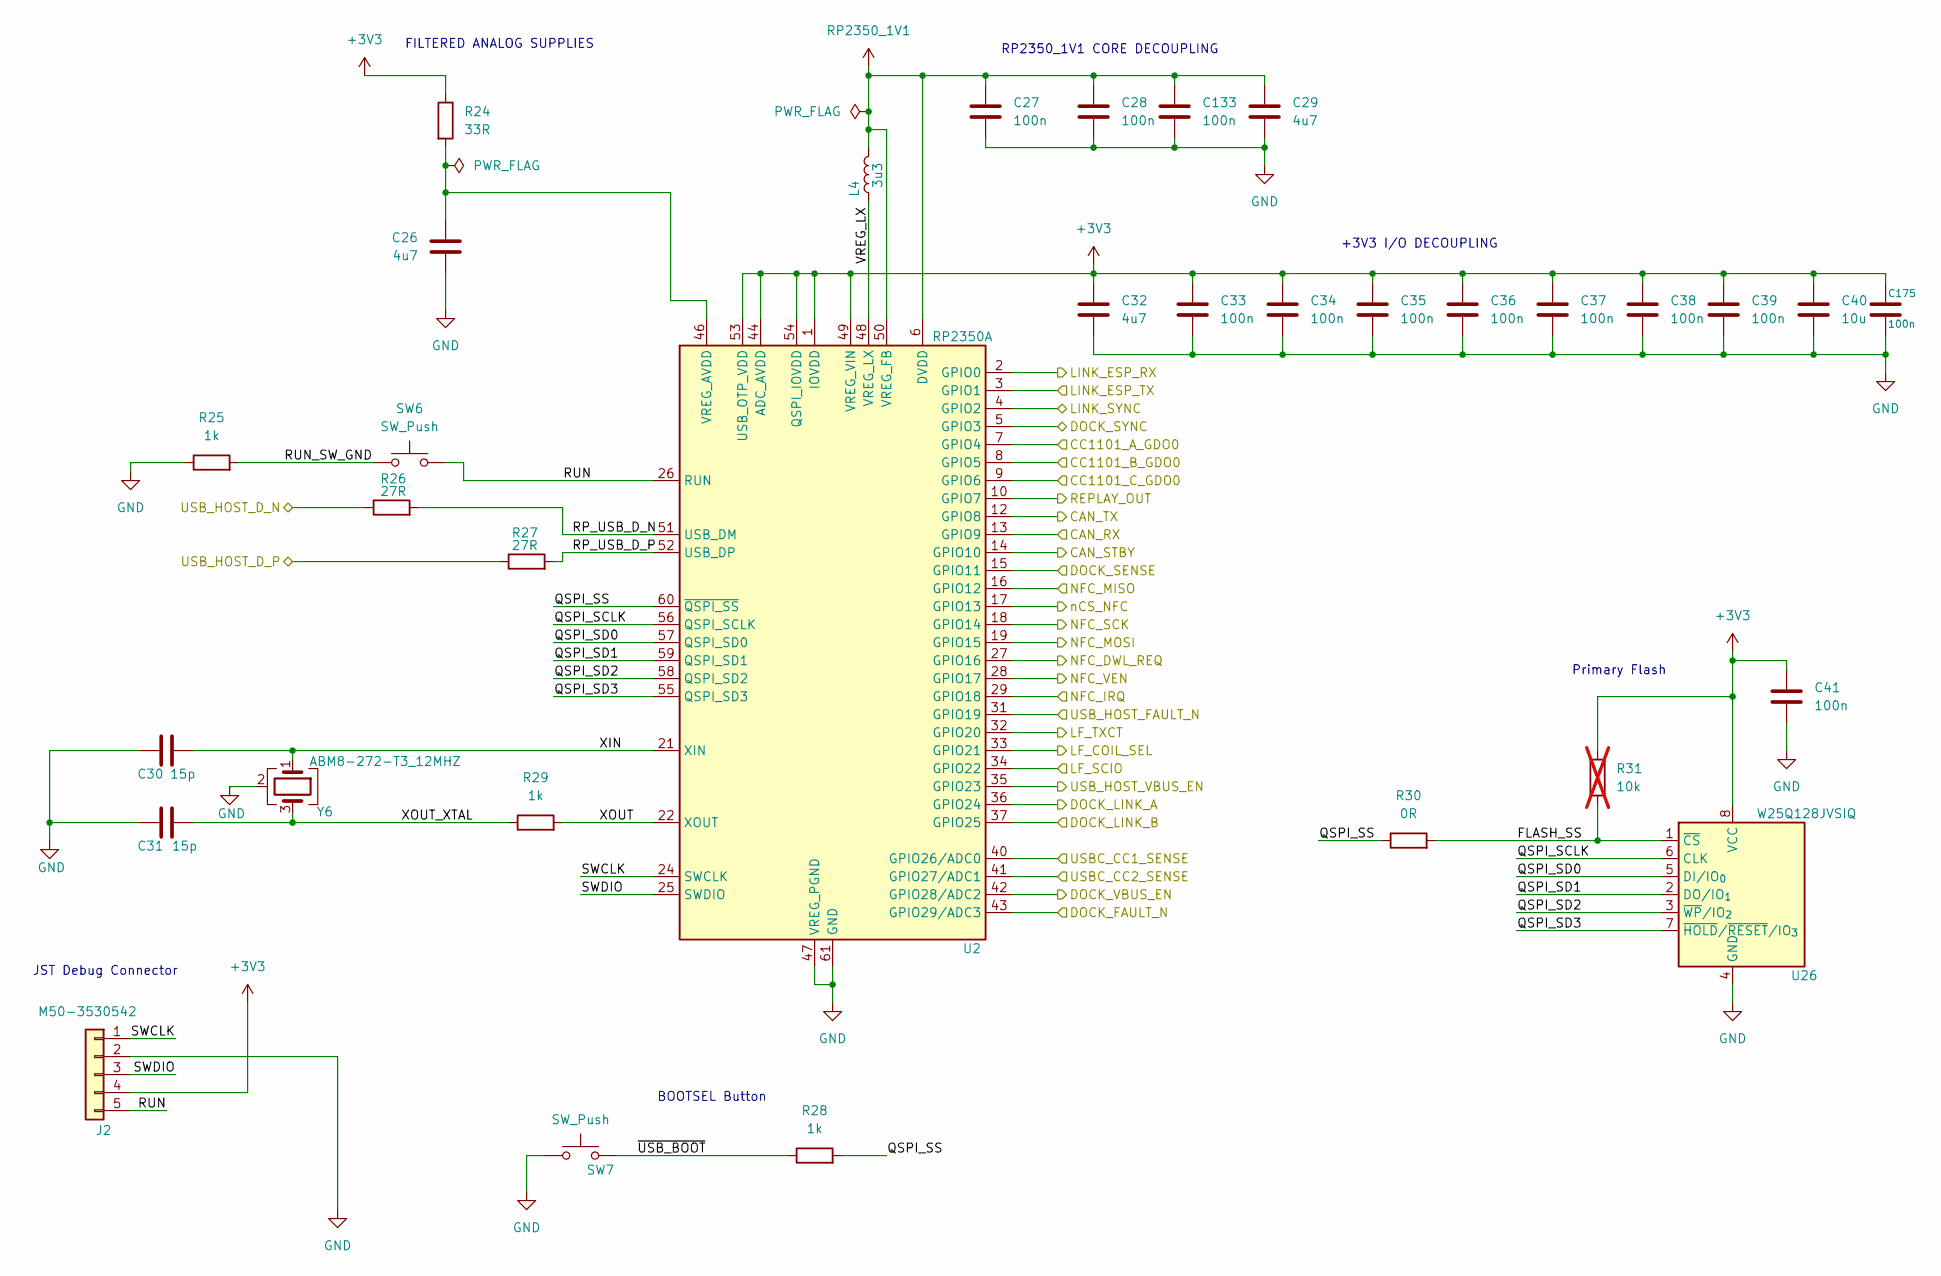
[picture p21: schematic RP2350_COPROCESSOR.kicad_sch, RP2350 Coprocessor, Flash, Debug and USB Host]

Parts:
C26, C29, C32: 4u7; C_0603_1608Metric; MPN GRM188Z71A475KE15D
C27, C28, C33, C34, C35, C36, C37, C38, C39, C41, C133, C175: 100n; C_0402_1005Metric; MPN GRM155R71C104KA88D
C30, C31: 15p; C_0402_1005Metric; MPN GJM1555C1H150JB01D
C40: 10u; C_0805_2012Metric; MPN GRM21BR71A106KE51L
J2: M50-3530542; PinHeader_1x05_P1.27mm_Vertical; MPN M50-3530542
L4: 3u3; L_Abracon_AOTA-B201610S_2.0x1.6mm; MPN AOTA-B201610S3R3-101-T
R24: 33R; R_0603_1608Metric; MPN RC0603FR-0733RL
R25, R28, R29: 1k; R_0603_1608Metric; MPN RC0603FR-071KL
R26, R27: 27R; R_0603_1608Metric; MPN RC0603FR-0727RL
R30: 0R; R_0603_1608Metric; MPN RC0603JR-070RL
R31: 10k; R_0603_1608Metric; MPN RC0603FR-0710KL; not fitted
SW6, SW7: SW_Push; SW_SPST_PTS810; MPN PTS810SJM250SMTR LFS
U2: RP2350A; QFN-60-1EP_7x7mm_P0.4mm_EP3.4x3.4mm; MPN SC1509(13)-A4
U26: W25Q128JVSIQ; SOIC-8_5.3x5.3mm_P1.27mm; MPN W25Q128JVSIQTR
Y6: ABM8-272-T3_12MHZ; Crystal_SMD_Abracon_ABM8G-4Pin_3.2x2.5mm; MPN ABM8-272-T3

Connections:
+3V3: C32.1, C33.1, C34.1, C35.1, C36.1, C37.1, C38.1, C39.1, C40.1, C41.1, C175.1, J2.4, R24.1, R31.1, U2.1 (IOVDD), U2.11 (IOVDD), U2.20 (IOVDD), U2.30 (IOVDD), U2.38 (IOVDD), U2.44 (ADC_AVDD), U2.45 (IOVDD), U2.49 (VREG_VIN), U2.53 (USB_OTP_VDD), U2.54 (QSPI_IOVDD), U26.8 (VCC); also elsewhere on the board
/CAN_RX: U2.13 (GPIO9); also elsewhere on the board
/CAN_STBY: U2.14 (GPIO10); also elsewhere on the board
/CAN_TX: U2.12 (GPIO8); also elsewhere on the board
/CC1101_A_GDO0: U2.7 (GPIO4); also elsewhere on the board
/CC1101_B_GDO0: U2.8 (GPIO5); also elsewhere on the board
/CC1101_C_GDO0: U2.9 (GPIO6); also elsewhere on the board
/DOCK_FAULT_N: U2.43 (GPIO29/ADC3); also elsewhere on the board
/DOCK_LINK_A: U2.36 (GPIO24); also elsewhere on the board
/DOCK_LINK_B: U2.37 (GPIO25); also elsewhere on the board
/DOCK_SENSE: U2.15 (GPIO11); also elsewhere on the board
/DOCK_SYNC: U2.5 (GPIO3); also elsewhere on the board
/DOCK_VBUS_EN: U2.42 (GPIO28/ADC2); also elsewhere on the board
/LF_COIL_SEL: U2.33 (GPIO21); also elsewhere on the board
/LF_SCIO: U2.34 (GPIO22); also elsewhere on the board
/LF_TXCT: U2.32 (GPIO20); also elsewhere on the board
/LINK_ESP_RX: U2.2 (GPIO0); also elsewhere on the board
/LINK_ESP_TX: U2.3 (GPIO1); also elsewhere on the board
/LINK_SYNC: U2.4 (GPIO2); also elsewhere on the board
/NFC_DWL_REQ: U2.27 (GPIO16); also elsewhere on the board
/NFC_IRQ: U2.29 (GPIO18); also elsewhere on the board
/NFC_MISO: U2.16 (GPIO12); also elsewhere on the board
/NFC_MOSI: U2.19 (GPIO15); also elsewhere on the board
/NFC_SCK: U2.18 (GPIO14); also elsewhere on the board
/NFC_VEN: U2.28 (GPIO17); also elsewhere on the board
/REPLAY_OUT: U2.10 (GPIO7); also elsewhere on the board
/RP2350_COPROCESSOR/FLASH_SS: R30.2, R31.2, U26.1 (~CS)
/RP2350_COPROCESSOR/QSPI_SCLK: U2.56 (QSPI_SCLK), U26.6 (CLK)
/RP2350_COPROCESSOR/QSPI_SD0: U2.57 (QSPI_SD0), U26.5 (DI/IO_{0})
/RP2350_COPROCESSOR/QSPI_SD1: U2.59 (QSPI_SD1), U26.2 (DO/IO_{1})
/RP2350_COPROCESSOR/QSPI_SD2: U2.58 (QSPI_SD2), U26.3 (~WP/IO_{2})
/RP2350_COPROCESSOR/QSPI_SD3: U2.55 (QSPI_SD3), U26.7 (~HOLD/~RESET/IO_{3})
/RP2350_COPROCESSOR/QSPI_SS: R28.2, R30.1, U2.60 (~QSPI_SS)
/RP2350_COPROCESSOR/RP_USB_D_N: R26.2, U2.51 (USB_DM)
/RP2350_COPROCESSOR/RP_USB_D_P: R27.2, U2.52 (USB_DP)
/RP2350_COPROCESSOR/RUN: J2.5, SW6.2, U2.26 (RUN)
/RP2350_COPROCESSOR/RUN_SW_GND: R25.2, SW6.1
/RP2350_COPROCESSOR/SWCLK: J2.1, U2.24 (SWCLK)
/RP2350_COPROCESSOR/SWDIO: J2.3, U2.25 (SWDIO)
/RP2350_COPROCESSOR/VREG_LX: L4.2, U2.48 (VREG_LX)
/RP2350_COPROCESSOR/XIN: C30.2, U2.21 (XIN), Y6.1
/RP2350_COPROCESSOR/XOUT: R29.2, U2.22 (XOUT)
/RP2350_COPROCESSOR/XOUT_XTAL: C31.2, R29.1, Y6.3
/RP2350_COPROCESSOR/~USB_BOOT: R28.1, SW7.2
/USBC_CC1_SENSE: U2.40 (GPIO26/ADC0); also elsewhere on the board
/USBC_CC2_SENSE: U2.41 (GPIO27/ADC1); also elsewhere on the board
/USB_HOST_D_N: R26.1; also elsewhere on the board
/USB_HOST_D_P: R27.1; also elsewhere on the board
/USB_HOST_FAULT_N: U2.31 (GPIO19); also elsewhere on the board
/USB_HOST_VBUS_EN: U2.35 (GPIO23); also elsewhere on the board
/nCS_NFC: U2.17 (GPIO13); also elsewhere on the board
GND: C26.2, C27.2, C28.2, C29.2, C30.1, C31.1, C32.2, C33.2, C34.2, C35.2, C36.2, C37.2, C38.2, C39.2, C40.2, C41.2, C133.2, C175.2, J2.2, R25.1, SW7.1, U2.47 (VREG_PGND), U2.61 (GND), U26.4 (GND), Y6.2 (G), Y6.4 (G); also elsewhere on the board
unnamed: C26.1, R24.2, U2.46 (VREG_AVDD)
RP2350_1V1: C27.1, C28.1, C29.1, C133.1, L4.1, U2.6 (DVDD), U2.23 (DVDD), U2.39 (DVDD), U2.50 (VREG_FB)

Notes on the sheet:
+3V3 I/O DECOUPLING
JST Debug Connector
RP2350_1V1 CORE DECOUPLING
Primary Flash
FILTERED ANALOG SUPPLIES
BOOTSEL Button

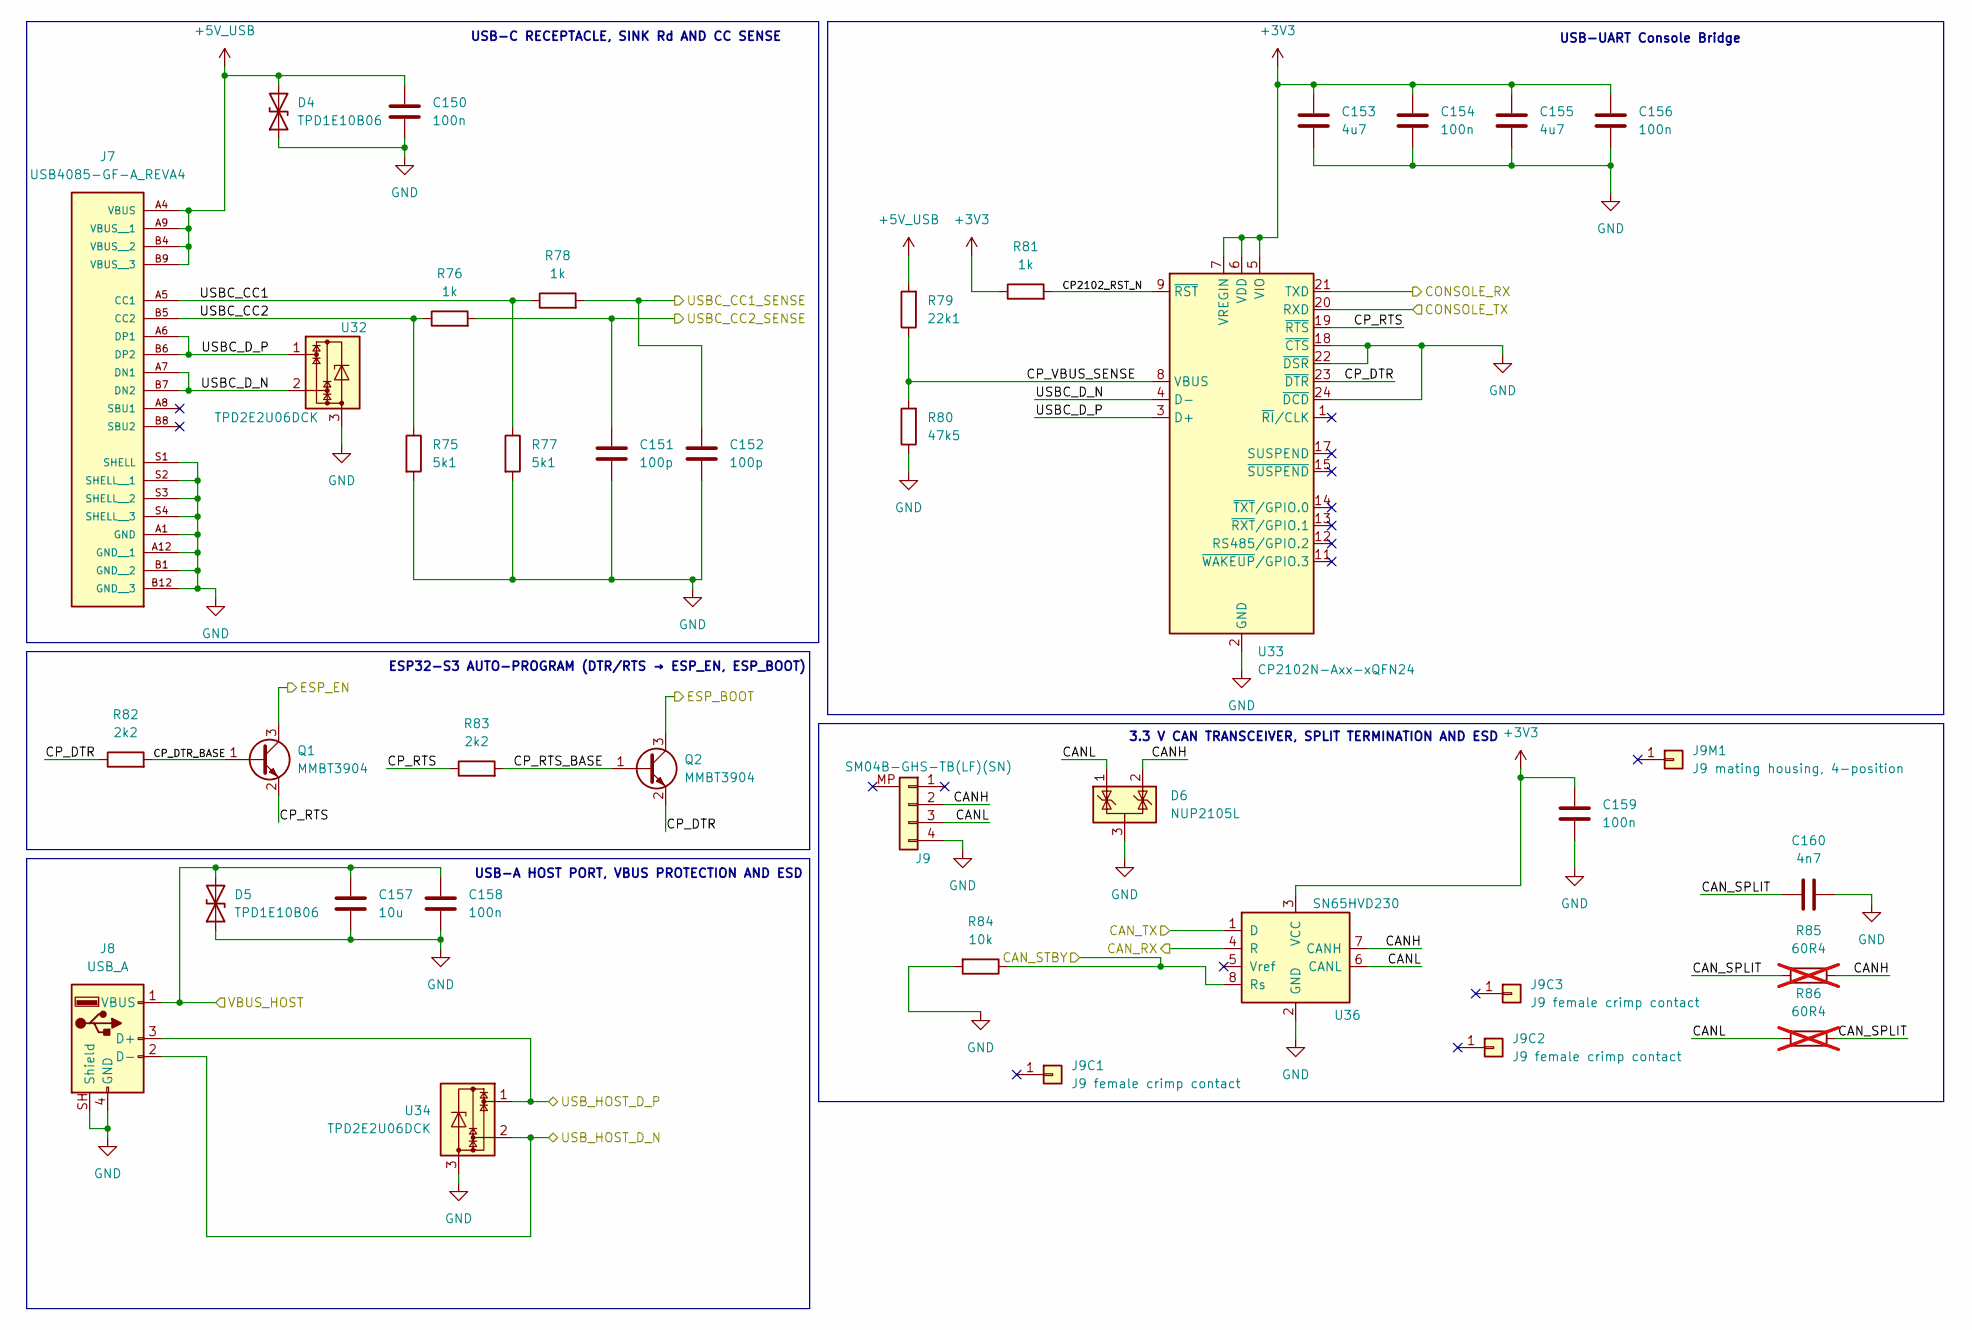
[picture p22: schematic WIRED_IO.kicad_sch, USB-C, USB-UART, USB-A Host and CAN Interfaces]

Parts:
C150, C154, C156, C158, C159: 100n; C_0603_1608Metric; MPN GRM188R71C104KA01D
C151, C152: 100p; C_0603_1608Metric; MPN GRM1885C1H101JA01D
C153, C155: 4u7; C_0603_1608Metric; MPN GRM188Z71A475KE15D
C157: 10u; C_0805_2012Metric; MPN GRM21BR71A106KE51L
C160: 4n7; C_0603_1608Metric; MPN GRM1885C1H472JA01D
D4, D5: TPD1E10B06; Texas_DPY0002A_0.6x1mm_P0.65mm; MPN TPD1E10B06DPYR
D6: NUP2105L; SOT-23; MPN NUP2105LT1G
J7: USB4085-GF-A_REVA4; GCT_USB4085-GF-A_REVA4; PARTREV A4
J8: USB_A; USB_A_Molex_67643_Horizontal; MPN 67643-3910
J9: SM04B-GHS-TB(LF)(SN); JST_GH_SM04B-GHS-TB_1x04-1MP_P1.25mm_Horizontal; MPN SM04B-GHS-TB(LF)(SN)
J9C1, J9C2, J9C3: J9 female crimp contact; MPN SSHL-002T-P0.2
J9M1: J9 mating housing, 4-position; MPN GHR-04V-S
Q1, Q2: MMBT3904; SOT-23; MPN MMBT3904LT1G
R75, R77: 5k1; R_0603_1608Metric; MPN RC0603FR-075K1L
R76, R78, R81: 1k; R_0603_1608Metric; MPN RC0603FR-071KL
R79: 22k1; R_0603_1608Metric; MPN RC0603FR-0722K1L
R80: 47k5; R_0603_1608Metric; MPN RC0603FR-0747K5L
R82, R83: 2k2; R_0603_1608Metric; MPN RC0603FR-072K2L
R84: 10k; R_0603_1608Metric; MPN RC0603FR-0710KL
R85, R86: 60R4; R_0603_1608Metric; MPN RC0603FR-0760R4L; not fitted
U32, U34: TPD2E2U06DCK; SOT-323_SC-70; MPN TPD2E2U06DCKR
U33: CP2102N-Axx-xQFN24; QFN-24-1EP_4x4mm_P0.5mm_EP2.6x2.6mm; MPN CP2102N-A02-GQFN24R
U36: SN65HVD230; SOIC-8_3.9x4.9mm_P1.27mm; MPN SN65HVD230DR

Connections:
+3V3: C153.1, C154.1, C155.1, C156.1, C159.2, R81.1, U33.5 (VIO), U33.6 (VDD), U33.7 (VREGIN), U36.3 (VCC); also elsewhere on the board
+5V_USB: C150.1, D4.2 (A2), J7.A4 (VBUS), J7.A9 (VBUS__1), J7.B4 (VBUS__2), J7.B9 (VBUS__3), R79.2; also elsewhere on the board
/CAN_RX: U36.4 (R); also elsewhere on the board
/CAN_STBY: R84.1, U36.8 (Rs); also elsewhere on the board
/CAN_TX: U36.1 (D); also elsewhere on the board
/CONSOLE_RX: U33.21 (TXD); also elsewhere on the board
/CONSOLE_TX: U33.20 (RXD); also elsewhere on the board
/ESP_BOOT: Q2.3 (C); also elsewhere on the board
/ESP_EN: Q1.3 (C); also elsewhere on the board
/USBC_CC1_SENSE: C152.1, R78.2; also elsewhere on the board
/USBC_CC2_SENSE: C151.1, R76.2; also elsewhere on the board
/USB_HOST_D_N: J8.2 (D-), U34.2; also elsewhere on the board
/USB_HOST_D_P: J8.3 (D+), U34.1; also elsewhere on the board
/VBUS_HOST: C157.1, C158.1, D5.2 (A2), J8.1 (VBUS); also elsewhere on the board
/WIRED_IO/CANH: D6.2 (K), J9.2, R85.1, U36.7 (CANH)
/WIRED_IO/CANL: D6.1 (K), J9.3, R86.2, U36.6 (CANL)
/WIRED_IO/CAN_SPLIT: C160.2, R85.2, R86.1
/WIRED_IO/CP2102_RST_N: R81.2, U33.9 (~RST)
/WIRED_IO/CP_DTR: Q2.2 (E), R82.1, U33.23 (~DTR)
/WIRED_IO/CP_DTR_BASE: Q1.1 (B), R82.2
/WIRED_IO/CP_RTS: Q1.2 (E), R83.1, U33.19 (~RTS)
/WIRED_IO/CP_RTS_BASE: Q2.1 (B), R83.2
/WIRED_IO/CP_VBUS_SENSE: R79.1, R80.2, U33.8 (VBUS)
/WIRED_IO/USBC_CC1: J7.A5 (CC1), R77.1, R78.1
/WIRED_IO/USBC_CC2: J7.B5 (CC2), R75.1, R76.1
/WIRED_IO/USBC_D_N: J7.A7 (DN1), J7.B7 (DN2), U32.2, U33.4 (D-)
/WIRED_IO/USBC_D_P: J7.A6 (DP1), J7.B6 (DP2), U32.1, U33.3 (D+)
GND: C150.2, C151.2, C152.2, C153.2, C154.2, C155.2, C156.2, C157.2, C158.2, C159.1, C160.1, D4.1 (A1), D5.1 (A1), D6.3 (A), J7.A1 (GND), J7.A12 (GND__1), J7.B1 (GND__2), J7.B12 (GND__3), J7.S1 (SHELL), J7.S2 (SHELL__1), J7.S3 (SHELL__2), J7.S4 (SHELL__3), J8.4 (GND), J8.SH (Shield), J9.4, R75.2, R77.2, R80.1, R84.2, U32.3, U33.2 (GND), U33.18 (~CTS), U33.22 (~DSR), U33.24 (~DCD), U33.25 (GND), U34.3, U36.2 (GND); also elsewhere on the board

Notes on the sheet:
ESP32-S3 AUTO-PROGRAM (DTR/RTS → ESP_EN, ESP_BOOT)
USB-C RECEPTACLE, SINK Rd AND CC SENSE
3.3 V CAN TRANSCEIVER, SPLIT TERMINATION AND ESD
USB-A HOST PORT, VBUS PROTECTION AND ESD
USB-UART Console Bridge

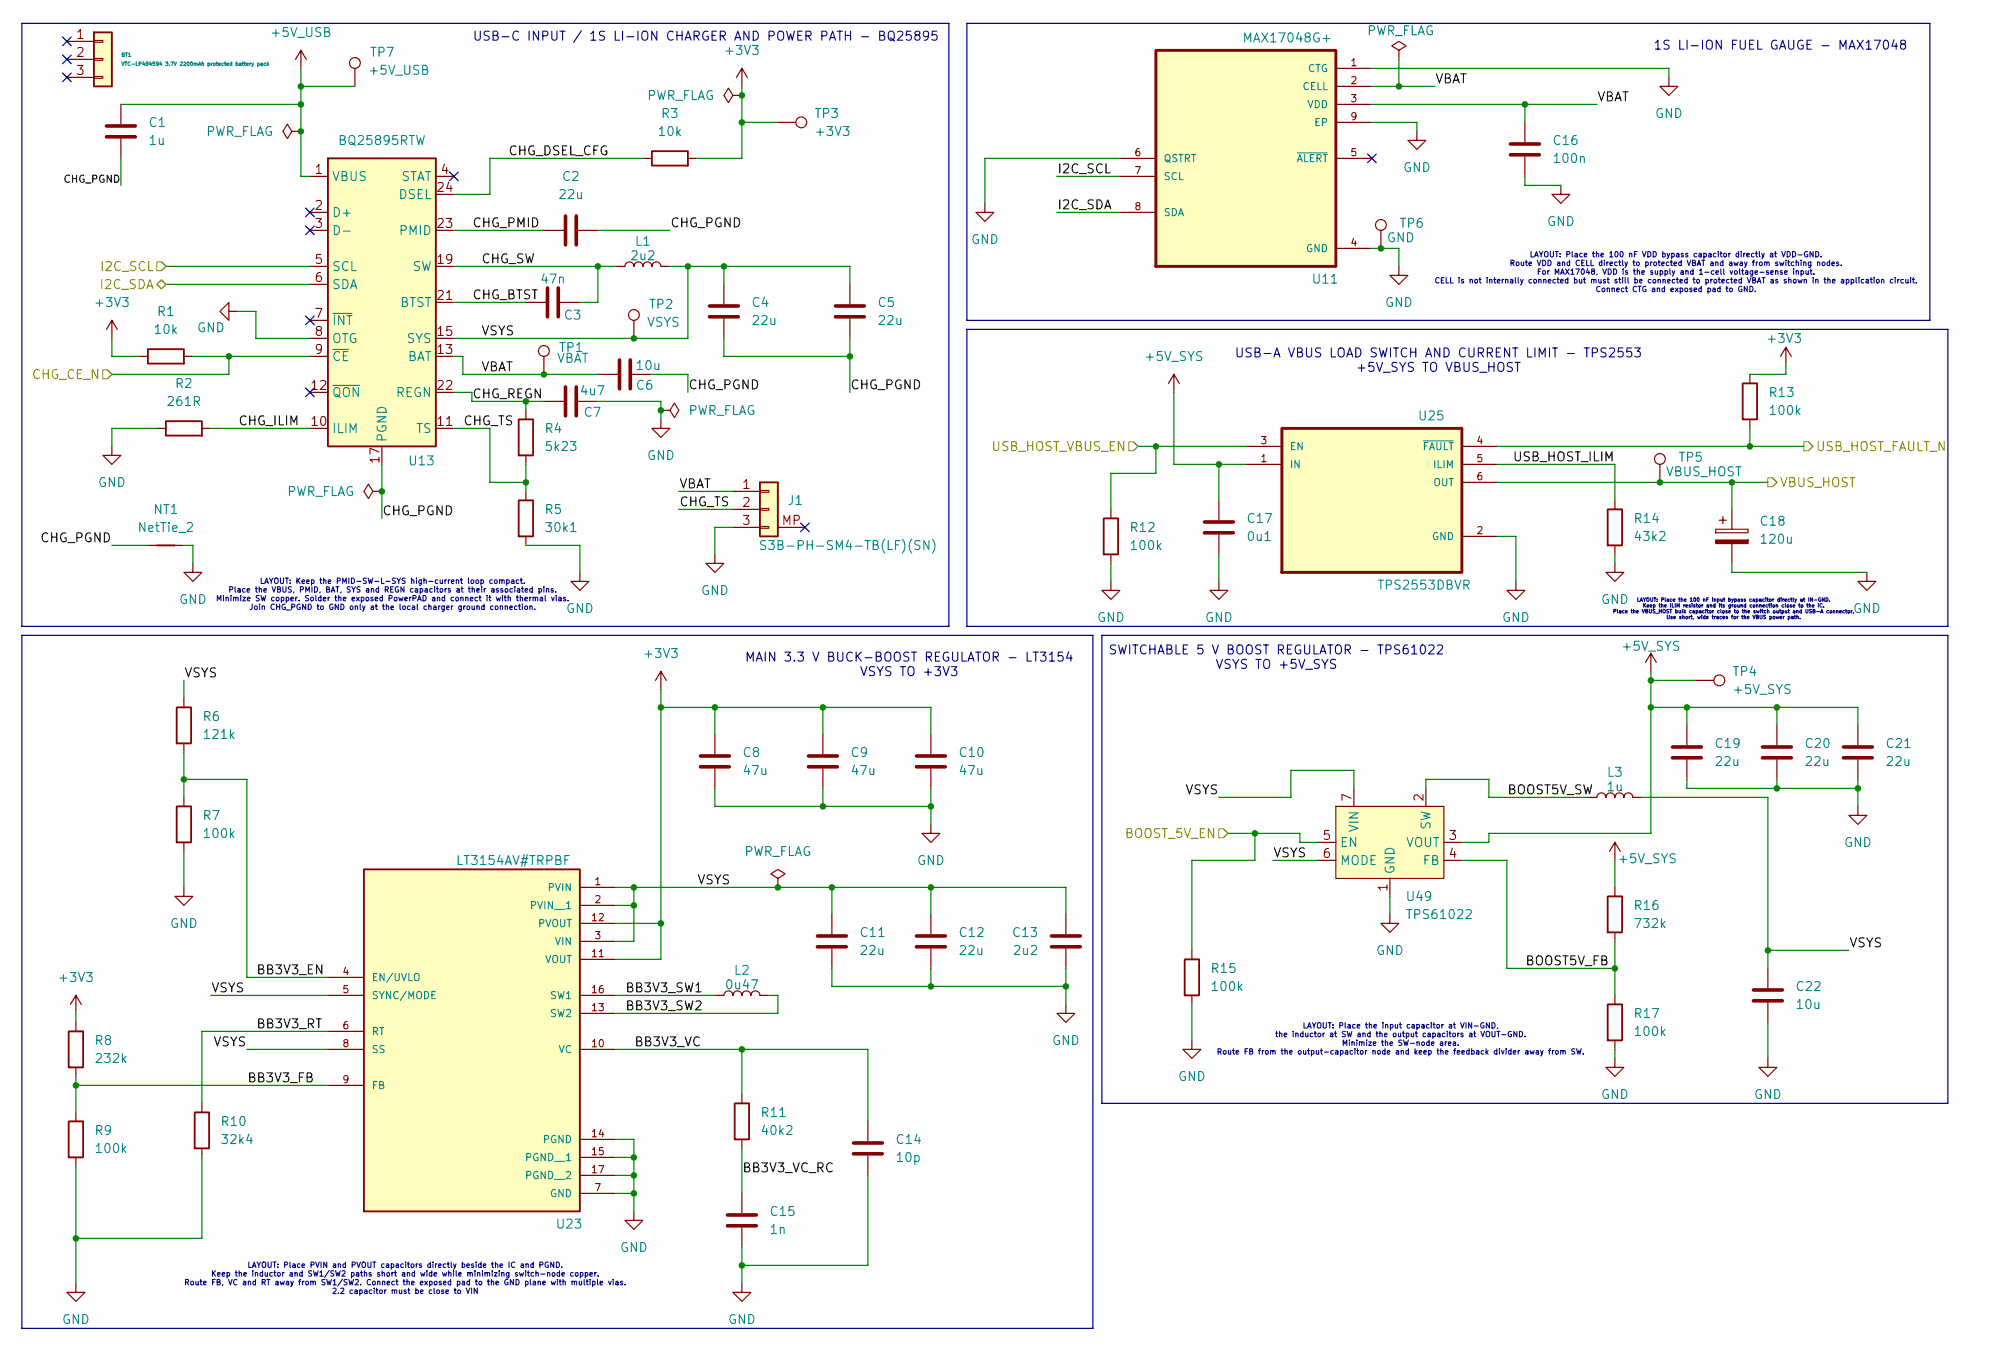
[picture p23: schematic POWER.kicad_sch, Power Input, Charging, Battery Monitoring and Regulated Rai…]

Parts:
BT1: VTC-LP484594 3.7V 2200mAh protected battery pack; MPN VTC-LP484594
C1: 1u; C_0603_1608Metric; MPN GRM188R71C105KA12D
C2, C4, C5, C11, C12, C19, C20, C21: 22u; C_1206_3216Metric; MPN GRM31CR71A226KE15L
C3: 47n; C_0603_1608Metric; MPN GRM188R71C473KA01D
C6, C22: 10u; C_0805_2012Metric; MPN GRM21BR71A106KE51L
C7: 4u7; C_0805_2012Metric; MPN GRM21BR71A475KA73L
C8, C9, C10: 47u; C_1210_3225Metric; MPN GRM32ER71A476KE15L
C13: 2u2; C_0603_1608Metric; MPN GRM188R71A225KE15D
C14: 10p; C_0603_1608Metric; MPN GRM1885C1H100JA01D
C15: 1n; C_0603_1608Metric; MPN GRM1885C1H102JA01D
C16: 100n; C_0603_1608Metric; MPN GRM188R71C104KA01D
C17: 0u1; C_0603_1608Metric; MPN GRM188R71C104KA01D
C18: 120u; CP_Panasonic_EEF-TX_7.3x4.3mm; MPN EEF-TX0J121RF
J1: S3B-PH-SM4-TB(LF)(SN); JST_PH_S3B-PH-SM4-TB_1x03-1MP_P2.00mm_Horizontal; MPN S3B-PH-SM4-TB(LF)(SN)
L1: 2u2; L_Wuerth_MAPI-4020; MPN 74438356022
L2: 0u47; L_Wuerth_MAPI-4020; MPN 744383560047HT
L3: 1u; L_Wuerth_HCI-5040; MPN 744316100
NT1: NetTie_2; NetTie_2_SMD_3.0mm_Current; MPN N/A
R1, R3: 10k; R_0603_1608Metric; MPN RC0603FR-0710KL
R2: 261R; R_0603_1608Metric; MPN AF0603FR-07261RL
R4: 5k23; R_0603_1608Metric; MPN RC0603FR-075K23L
R5: 30k1; R_0603_1608Metric; MPN RC0603FR-0730K1L
R6: 121k; R_0603_1608Metric; MPN RC0603FR-07121KL
R7, R9, R12, R13, R15, R17: 100k; R_0603_1608Metric; MPN RC0603FR-07100KL
R8: 232k; R_0603_1608Metric; MPN RC0603FR-07232KL
R10: 32k4; R_0603_1608Metric; MPN RC0603FR-0732K4L
R11: 40k2; R_0603_1608Metric; MPN RC0603FR-0740K2L
R14: 43k2; R_0603_1608Metric; MPN RC0603FR-0743K2L
R16: 732k; R_0603_1608Metric; MPN RC0603FR-07732KL
TP1: VBAT; TestPoint_Pad_D1.5mm; MPN N/A
TP2: VSYS; TestPoint_Pad_D1.5mm; MPN N/A
TP3: +3V3; TestPoint_Pad_D1.5mm; MPN N/A
TP4: +5V_SYS; TestPoint_Pad_D1.5mm; MPN N/A
TP5: VBUS_HOST; TestPoint_Pad_D1.5mm; MPN N/A
TP6: GND; TestPoint_Pad_D1.5mm; MPN N/A
TP7: +5V_USB; TestPoint_Pad_D1.5mm; MPN N/A
U11: MAX17048G+; SON50P200X200X80-9N; MPN MAX17048G+T10
U13: BQ25895RTW; Texas_RTW_WQFN-24-1EP_4x4mm_P0.5mm_EP2.7x2.7mm_ThermalVias; MPN BQ25895RTWR
U23: LT3154AV#TRPBF; QFN50P300X300X83-17N; PARTREV A
U25: TPS2553DBVR; SOT95P280X145-6N; MPN TPS2553DBVR
U49: TPS61022; Texas_RWU0007A_VQFN-7_2x2mm_P0.5mm; MPN TPS61022RWUR

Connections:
+3V3: C8.1, C9.1, C10.1, R1.1, R3.2, R8.1, R13.1, TP3.1 (1_1), U23.11 (VOUT), U23.12 (PVOUT); also elsewhere on the board
+5V_SYS: C17.2, C19.2, C20.2, C21.2, R16.1, TP4.1 (1_1), U25.1 (IN), U49.3 (VOUT); also elsewhere on the board
+5V_USB: C1.2, TP7.1 (1_1), U13.1 (VBUS); also elsewhere on the board
/BOOST_5V_EN: R15.1, U49.5 (EN); also elsewhere on the board
/CHG_CE_N: R1.2, U13.9 (~CE); also elsewhere on the board
/I2C_SCL: U11.7 (SCL), U13.5 (SCL); also elsewhere on the board
/I2C_SDA: U11.8 (SDA), U13.6 (SDA); also elsewhere on the board
/POWER/BB3V3_EN: R6.2, R7.1, U23.4 (EN/UVLO)
/POWER/BB3V3_FB: R8.2, R9.1, U23.9 (FB)
/POWER/BB3V3_RT: R10.1, U23.6 (RT)
/POWER/BB3V3_SW1: L2.1, U23.16 (SW1)
/POWER/BB3V3_SW2: L2.2, U23.13 (SW2)
/POWER/BB3V3_VC: C14.2, R11.1, U23.10 (VC)
/POWER/BB3V3_VC_RC: C15.2, R11.2
/POWER/BOOST5V_FB: R16.2, R17.1, U49.4 (FB)
/POWER/BOOST5V_SW: L3.1, U49.2 (SW)
/POWER/CHG_BTST: C3.1, U13.21 (BTST)
/POWER/CHG_DSEL_CFG: R3.1, U13.24 (DSEL)
/POWER/CHG_ILIM: R2.2, U13.10 (ILIM)
/POWER/CHG_PGND: C1.1, C2.2, C4.2, C5.2, C6.2, NT1.2, U13.17 (PGND), U13.18 (PGND), U13.25 (PGND)
/POWER/CHG_PMID: C2.1, U13.23 (PMID)
/POWER/CHG_REGN: C7.1, R4.1, U13.22 (REGN)
/POWER/CHG_SW: C3.2, L1.1, U13.19 (SW), U13.20 (SW)
/POWER/CHG_TS: J1.2, R4.2, R5.1, U13.11 (TS)
/POWER/USB_HOST_ILIM: R14.1, U25.5 (ILIM)
/POWER/VBAT: C6.1, C16.1, J1.1, TP1.1 (1_1), U11.2 (CELL), U11.3 (VDD), U13.13 (BAT), U13.14 (BAT)
/POWER/VSYS: C4.1, C5.1, C11.1, C12.1, C13.1, C22.2, L1.2, L3.2, R6.1, TP2.1 (1_1), U13.15 (SYS), U13.16 (SYS), U23.1 (PVIN), U23.2 (PVIN__1), U23.3 (VIN), U23.5 (SYNC/MODE), U23.8 (SS), U49.6 (MODE), U49.7 (VIN)
/USB_HOST_FAULT_N: R13.2, U25.4 (~FAULT); also elsewhere on the board
/USB_HOST_VBUS_EN: R12.1, U25.3 (EN); also elsewhere on the board
/VBUS_HOST: C18.1, TP5.1 (1_1), U25.6 (OUT); also elsewhere on the board
GND: C7.2, C8.2, C9.2, C10.2, C11.2, C12.2, C13.2, C14.1, C15.1, C16.2, C17.1, C18.2, C19.1, C20.1, C21.1, C22.1, J1.3, NT1.1, R2.1, R5.2, R7.2, R9.2, R10.2, R12.2, R14.2, R15.2, R17.2, TP6.1 (1_1), U11.1 (CTG), U11.4 (GND), U11.6 (QSTRT), U11.9 (EP), U13.8 (OTG), U23.7 (GND), U23.14 (PGND), U23.15 (PGND__1), U23.17 (PGND__2), U25.2 (GND), U49.1 (GND); also elsewhere on the board

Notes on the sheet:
LAYOUT: Place the 100 nF input bypass capacitor directly at IN-GND. Keep the ILIM resistor and its ground connection close to the IC. Place the VBUS_HOST bulk capacitor close to the switch output and USB-A connector. Use short, wide traces for the VBUS power path.
LAYOUT: Keep the PMID-SW-L-SYS high-current loop compact. Place the VBUS, PMID, BAT, SYS and REGN capacitors at their associated pins. Minimize SW copper. Solder the exposed PowerPAD and connect it with thermal vias. Join CHG_PGND to GND only at the local charger ground connection.
SWITCHABLE 5 V BOOST REGULATOR - TPS61022 VSYS TO +5V_SYS
1S LI-ION FUEL GAUGE - MAX17048
LAYOUT: Place the 100 nF VDD bypass capacitor directly at VDD-GND. Route VDD and CELL directly to protected VBAT and away from switching nodes. For MAX17048, VDD is the supply and 1-cell voltage-sense input. CELL is not internally connected but must still be connected to protected VBAT as shown in 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
USB-C INPUT / 1S LI-ION CHARGER AND POWER PATH - BQ25895
MAIN 3.3 V BUCK-BOOST REGULATOR - LT3154 VSYS TO +3V3
LAYOUT: Place PVIN and PVOUT capacitors directly beside the IC and PGND. Keep the inductor and SW1/SW2 paths short and wide while minimizing switch-node copper. Route FB, VC and RT away from SW1/SW2. Connect the exposed pad to the GND plane with multiple vias. 2.2 capacitor must be close to VIN
USB-A VBUS LOAD SWITCH AND CURRENT LIMIT - TPS2553 +5V_SYS TO VBUS_HOST
LAYOUT: Place the input capacitor at VIN-GND, the inductor at SW and the output capacitors at VOUT-GND. Minimize the SW-node area. Route FB from the output-capacitor node and keep the feedback divider away from SW.

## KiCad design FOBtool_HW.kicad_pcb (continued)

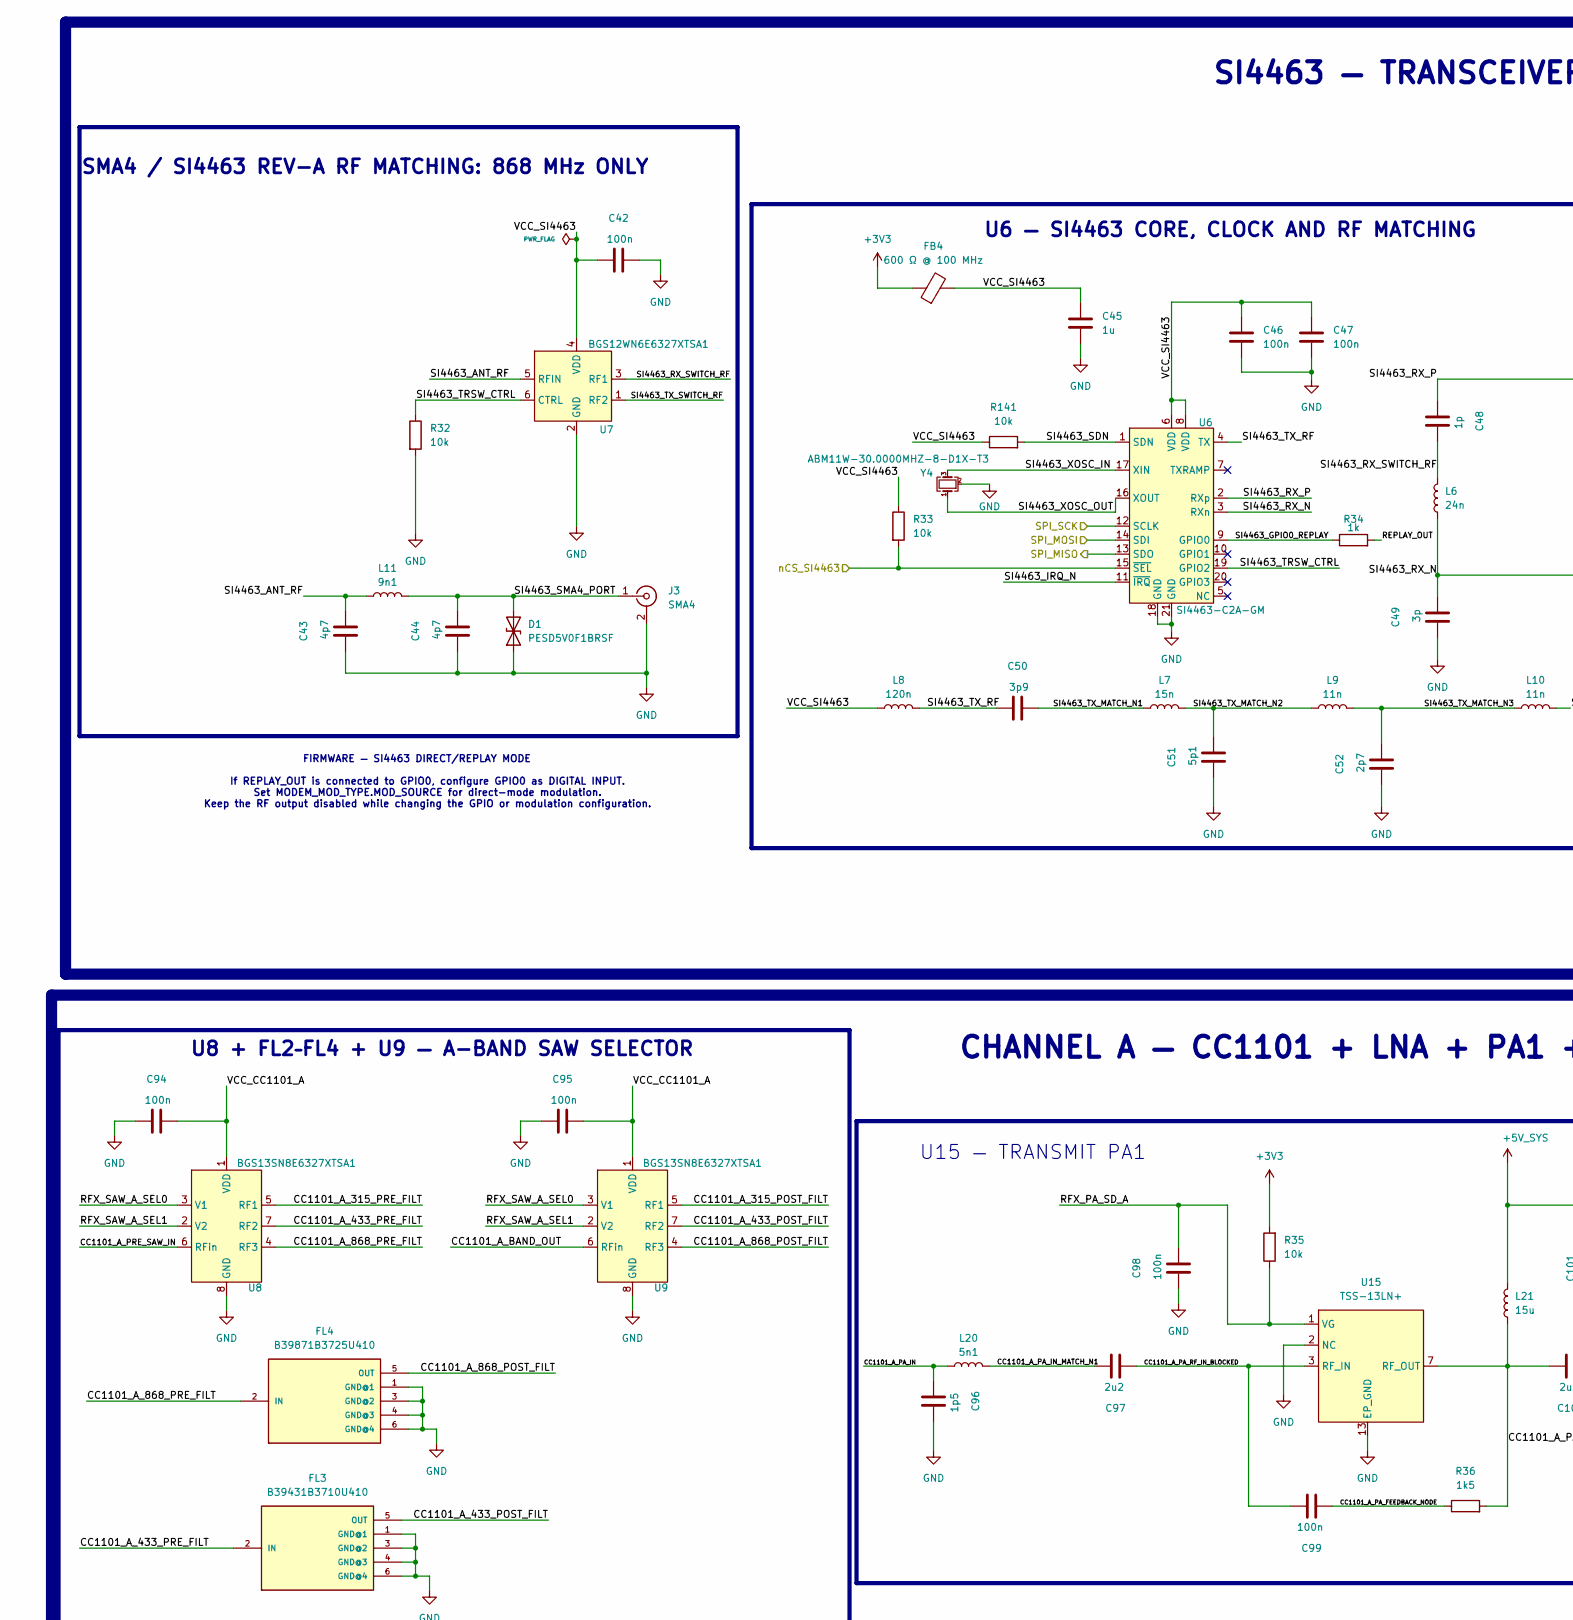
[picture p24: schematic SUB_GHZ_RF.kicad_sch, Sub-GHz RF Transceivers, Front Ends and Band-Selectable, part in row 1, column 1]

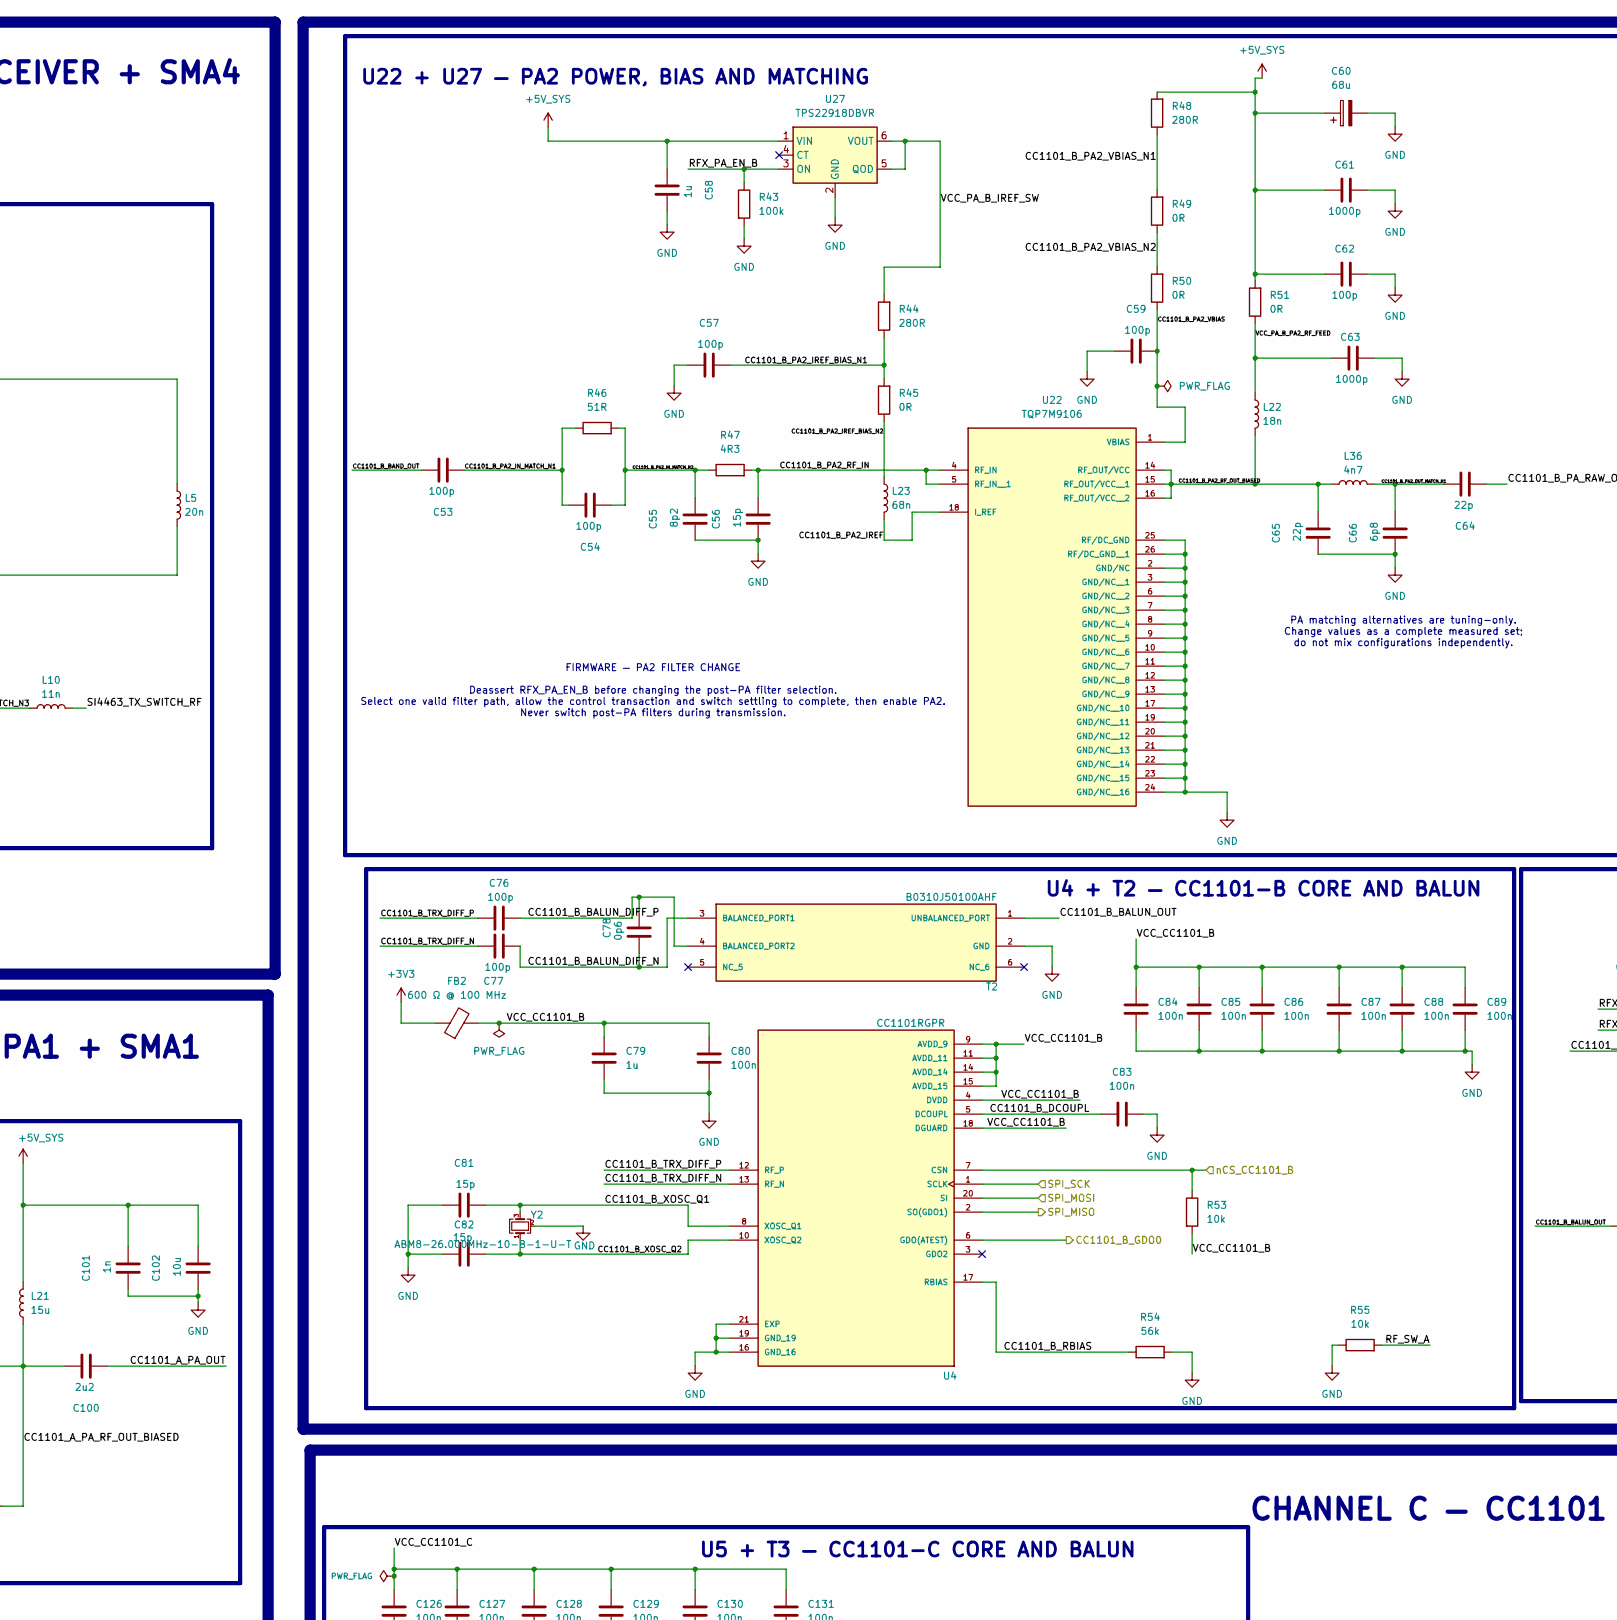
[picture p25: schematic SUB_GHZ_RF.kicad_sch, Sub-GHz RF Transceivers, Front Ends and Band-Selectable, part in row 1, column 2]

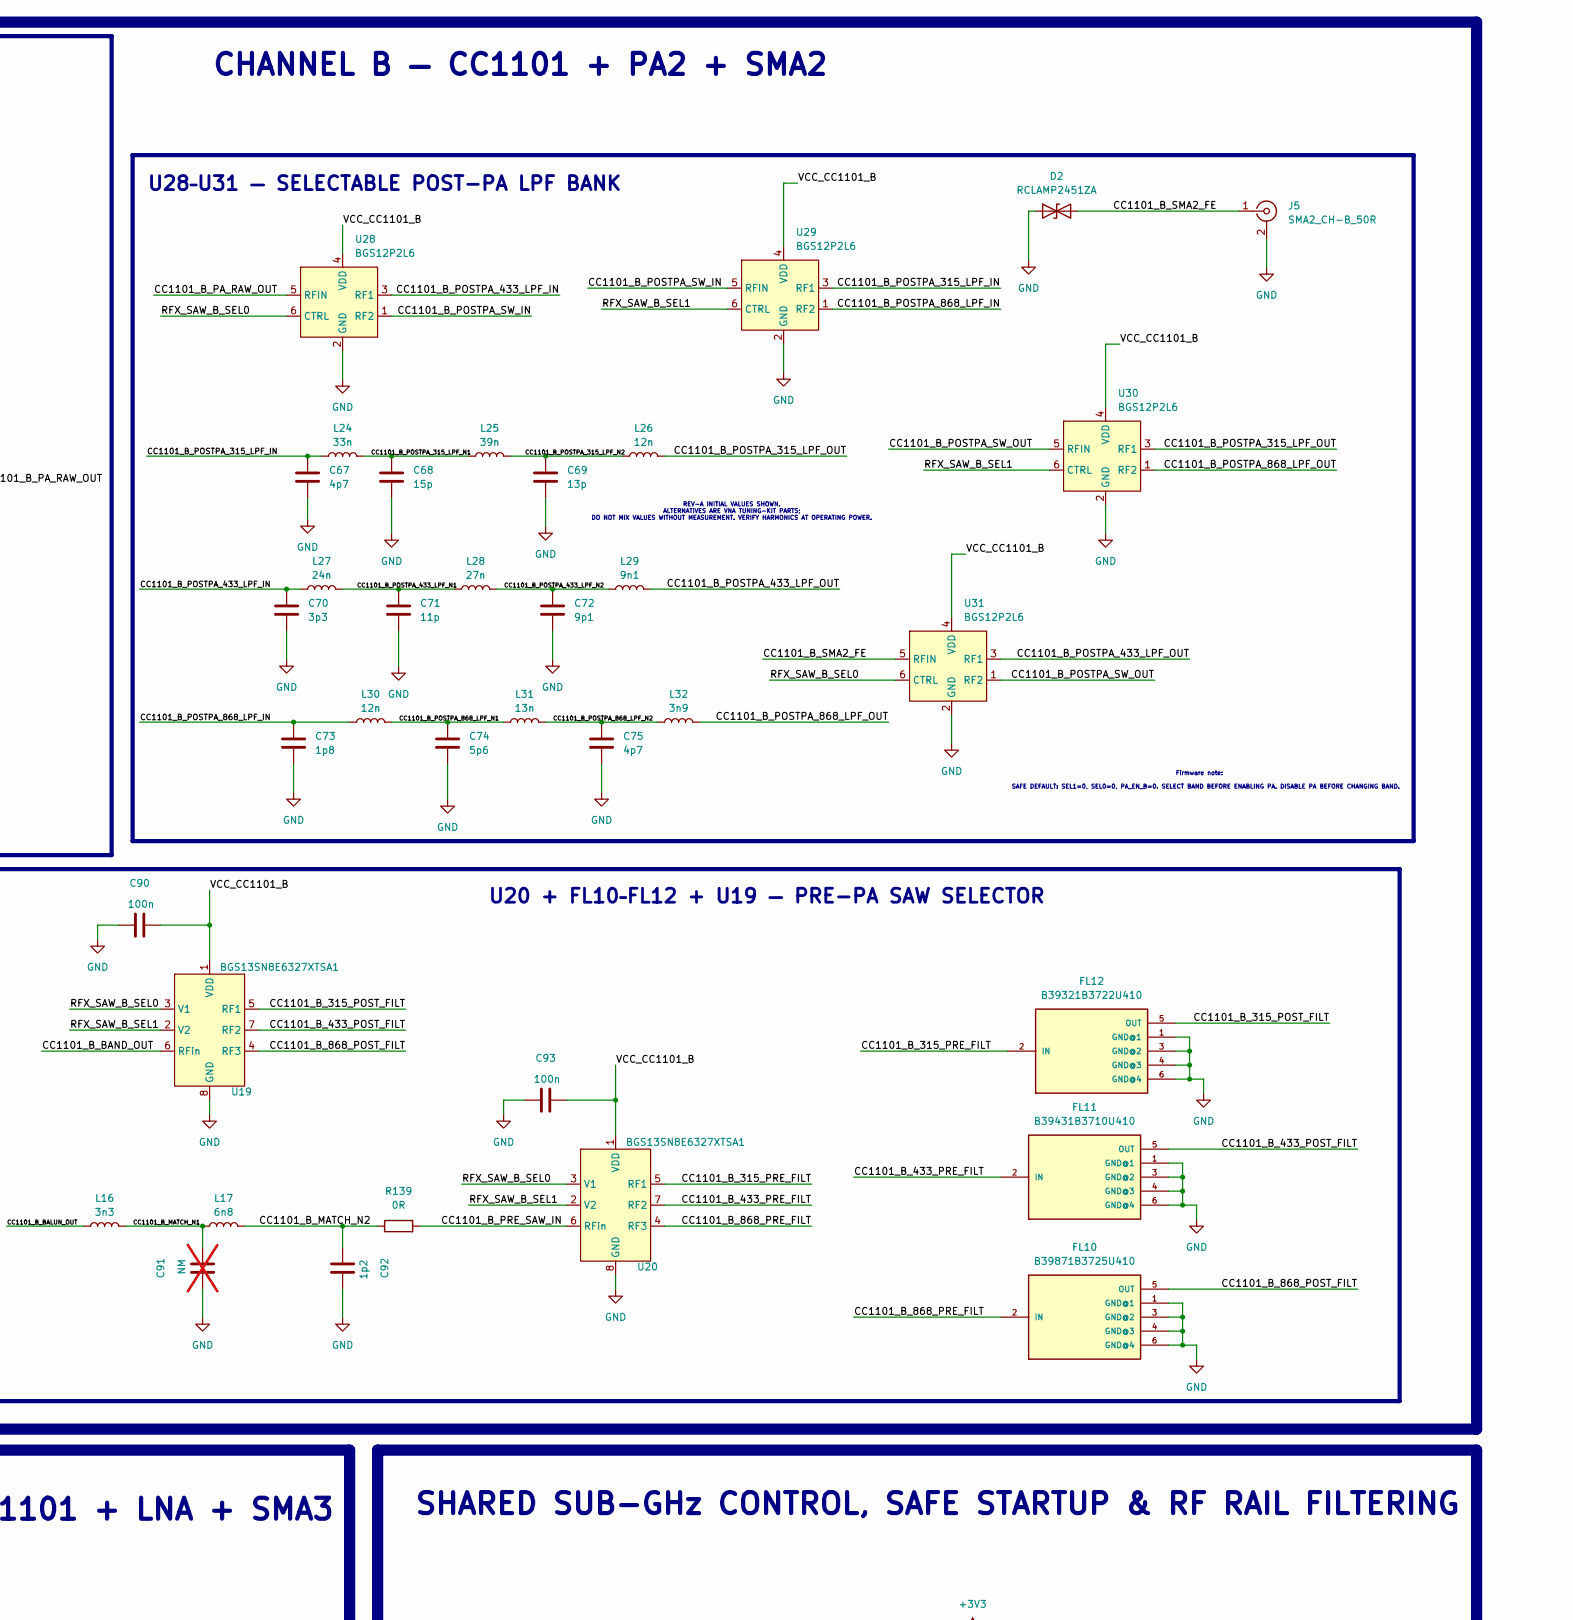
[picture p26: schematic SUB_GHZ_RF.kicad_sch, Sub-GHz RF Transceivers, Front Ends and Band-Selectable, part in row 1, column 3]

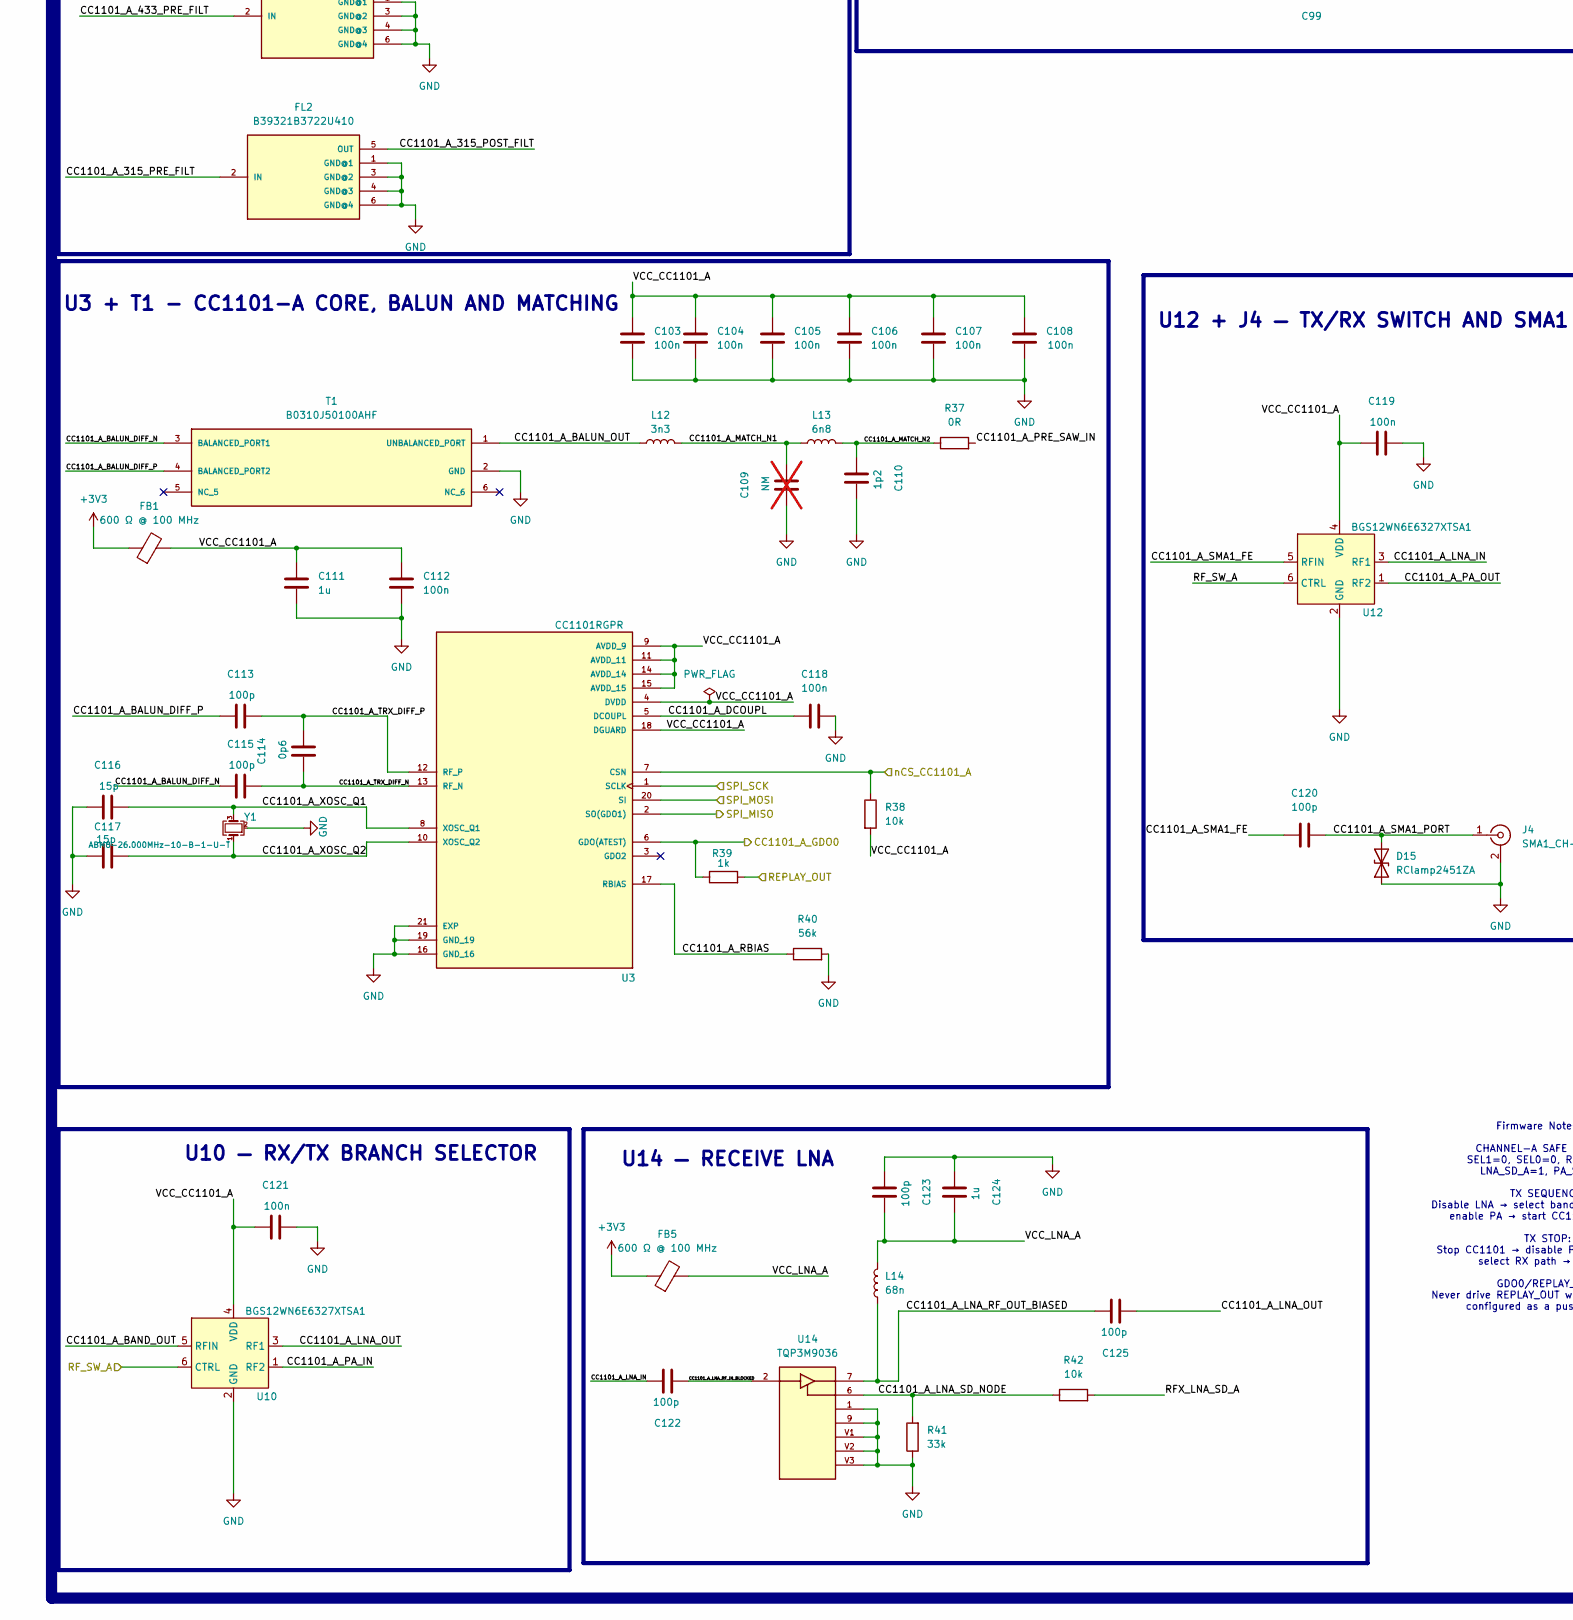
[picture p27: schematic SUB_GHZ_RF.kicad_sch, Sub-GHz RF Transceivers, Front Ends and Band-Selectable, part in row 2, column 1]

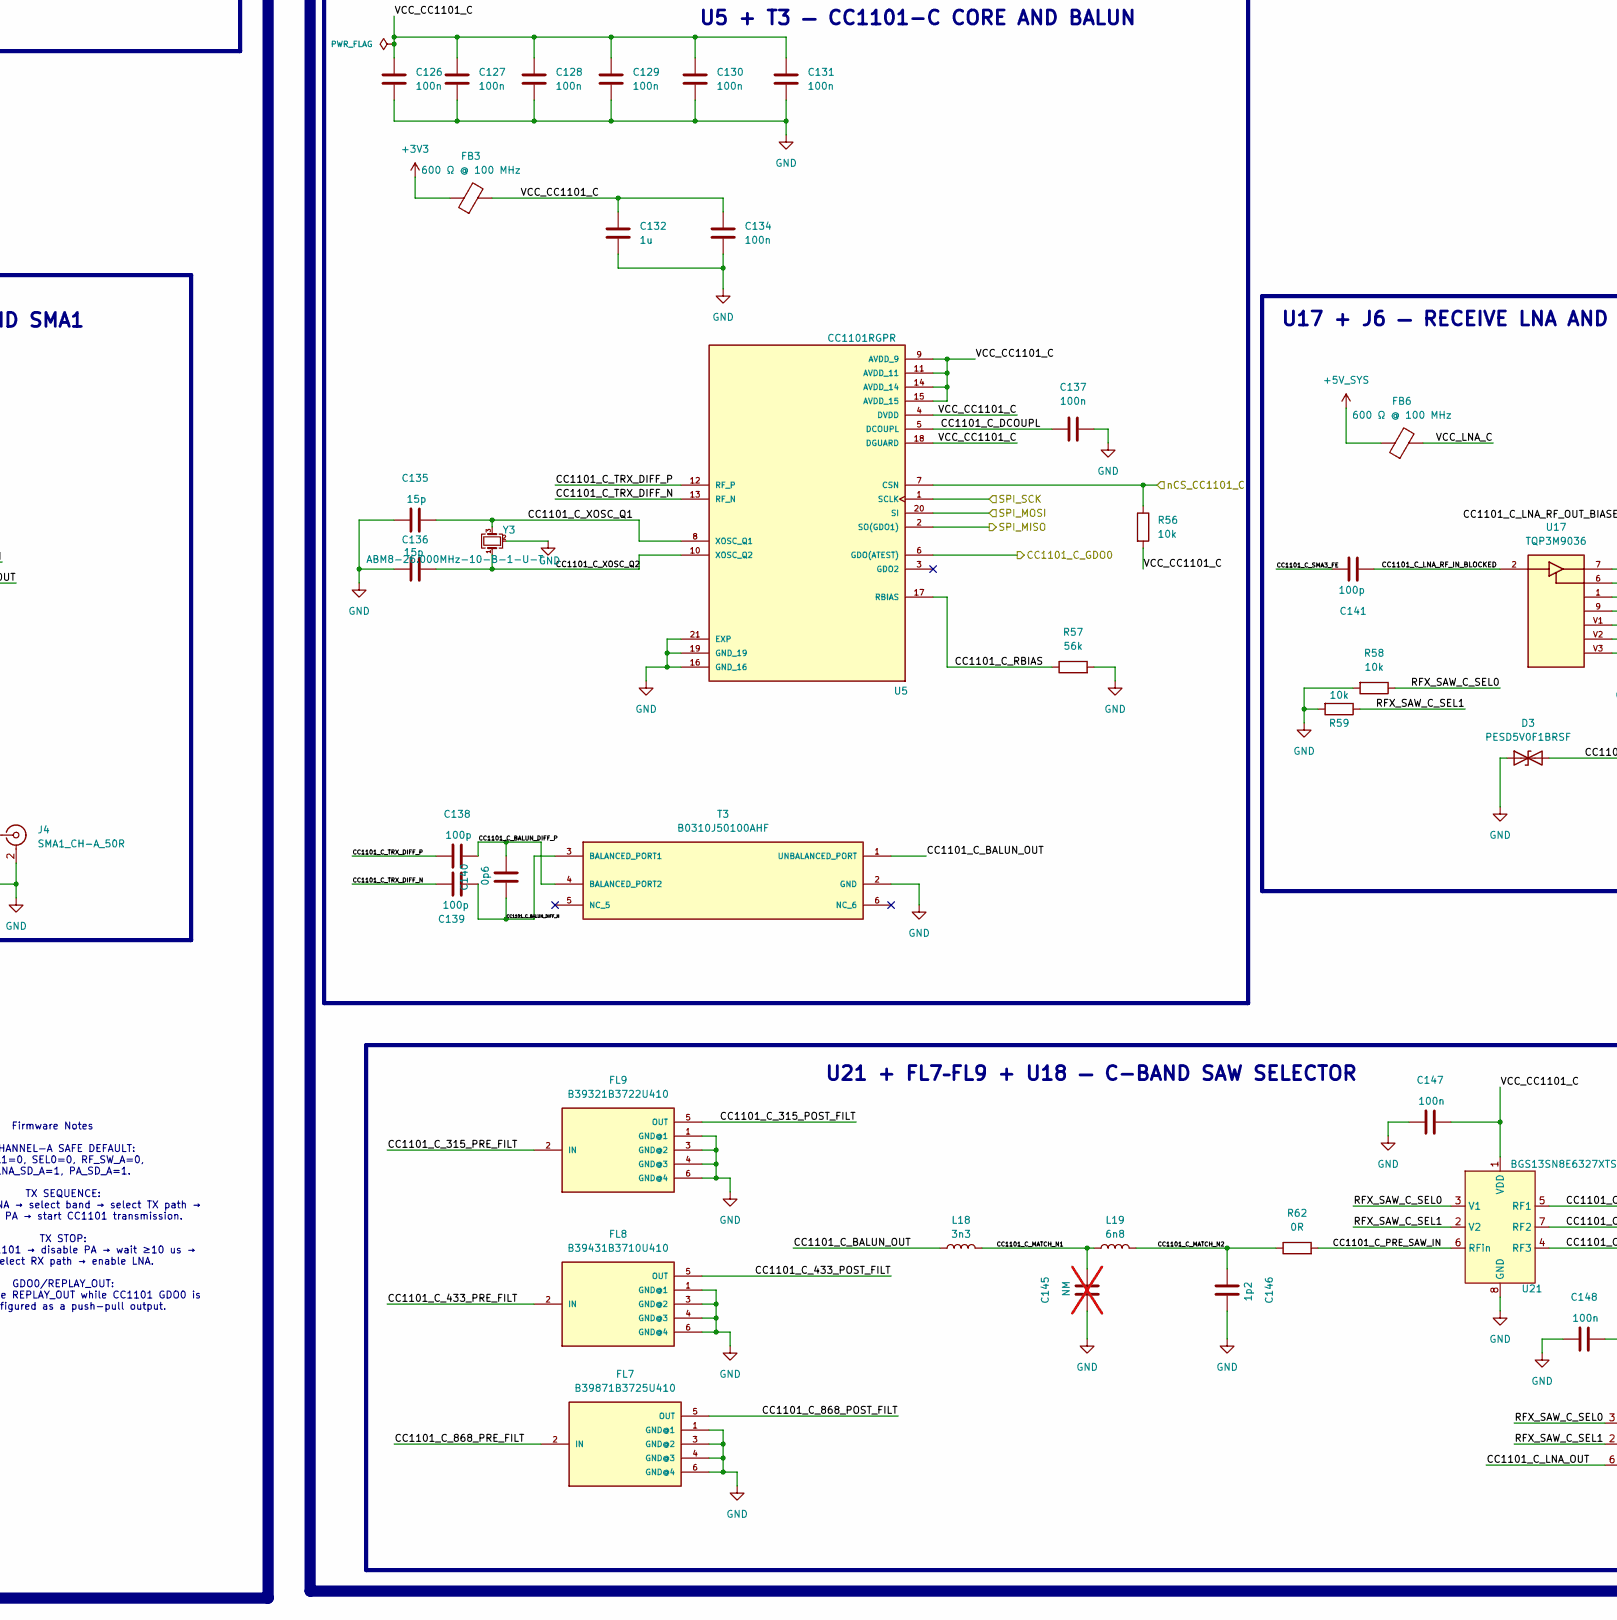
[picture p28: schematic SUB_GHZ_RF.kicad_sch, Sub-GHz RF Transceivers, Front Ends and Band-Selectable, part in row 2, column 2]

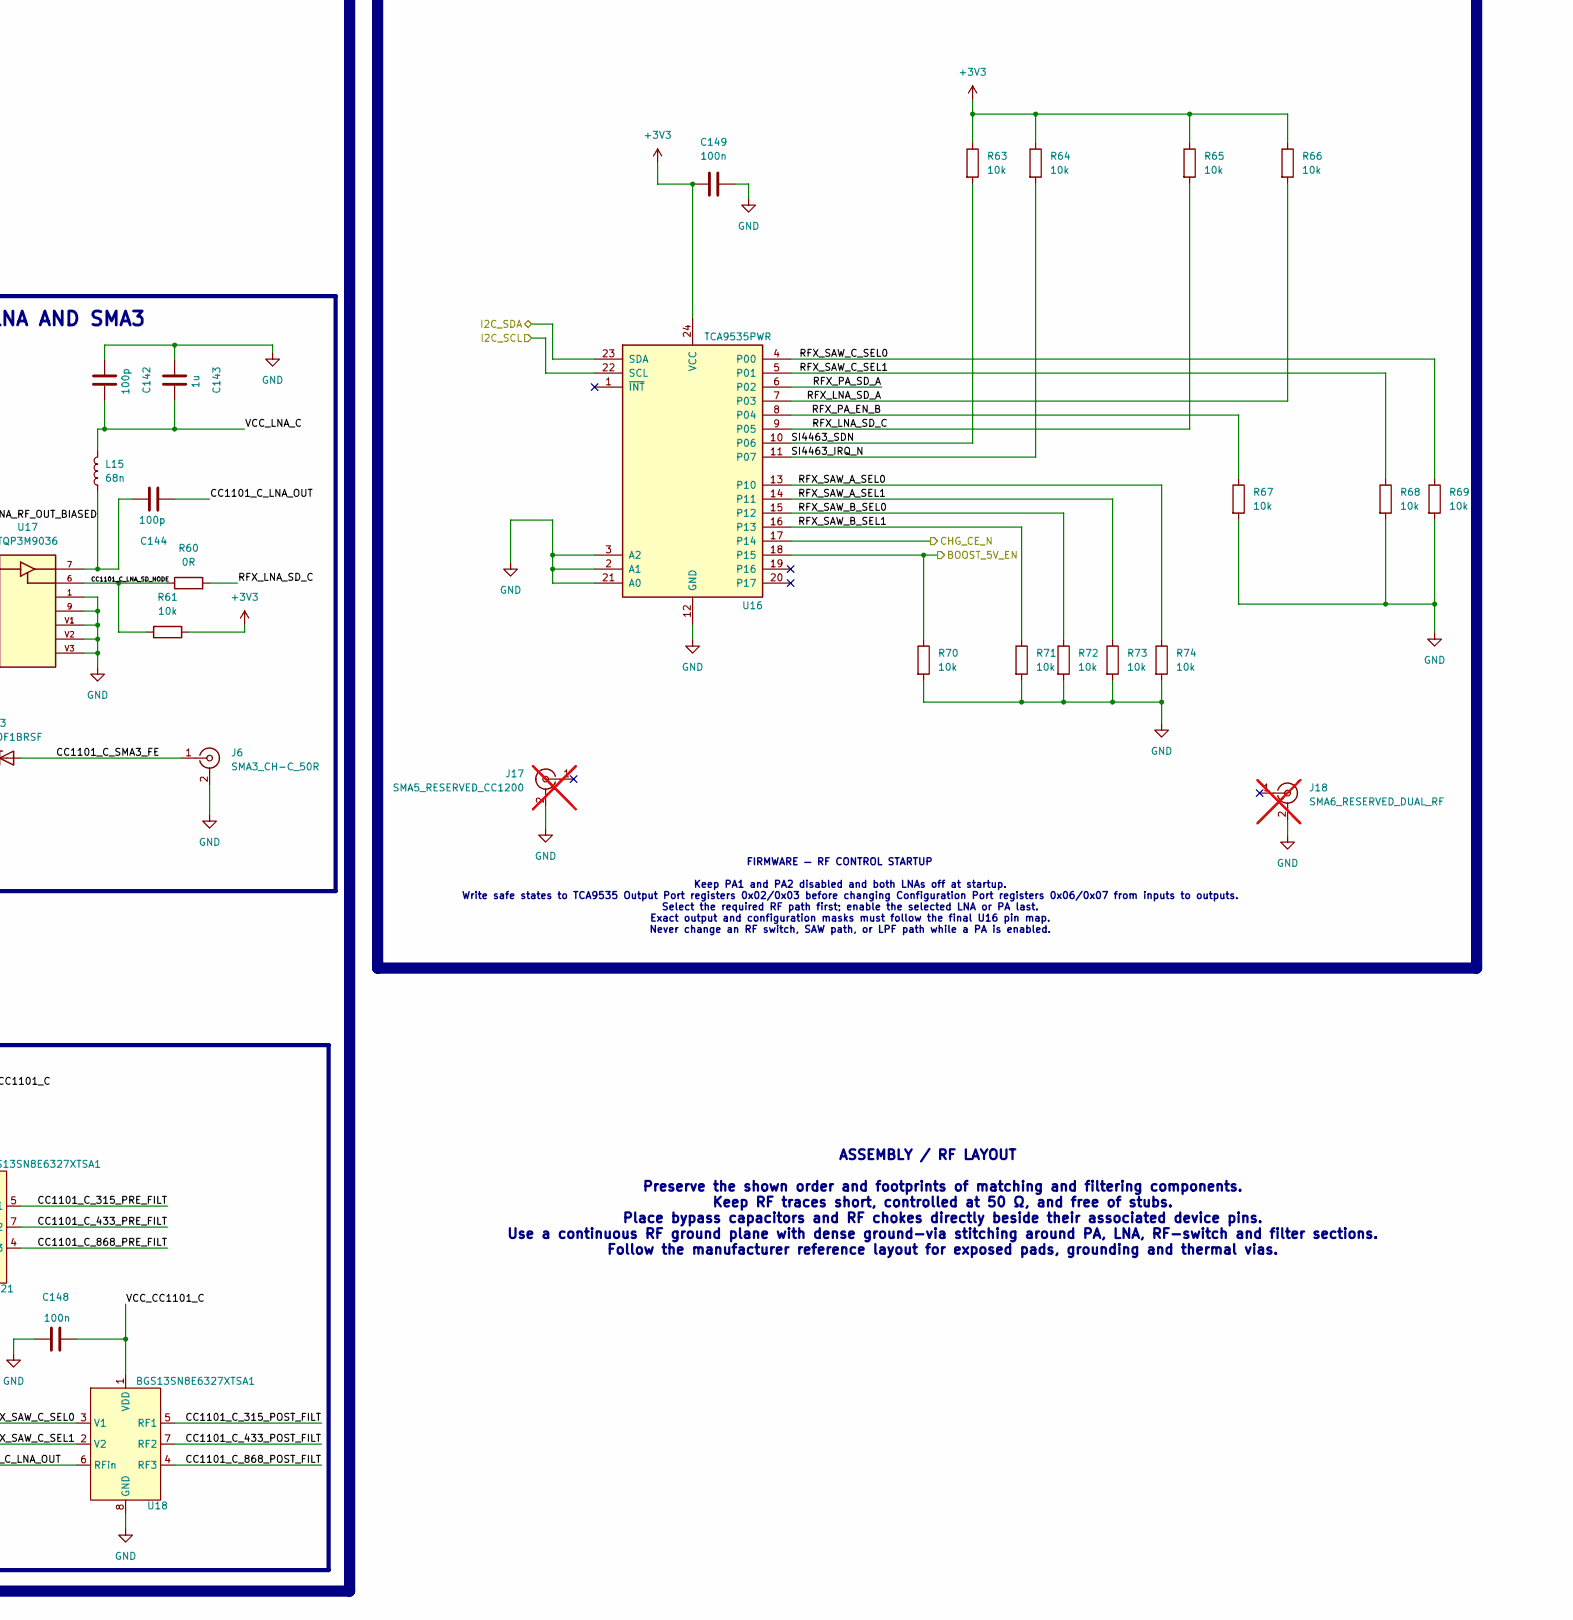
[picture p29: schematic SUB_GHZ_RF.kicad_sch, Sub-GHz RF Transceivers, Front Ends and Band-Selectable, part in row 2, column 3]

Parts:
C42, C46, C47, C80, C83, C84, C85, C86, C87, C88, C89, C90, C93, C94, C95, C98, C99, C103, C104, C105, C106, C107, C108, C112, C118, C119, C121, C126, C127, C128, C129, C130, C131, C134, C137, C147, C148, C149: 100n; C_0402_1005Metric; MPN GRM155R71C104KA88D
C43, C44, C67, C75: 4p7; C_0402_1005Metric; MPN GJM1555C1H4R7BB01D
C45, C58, C79, C111, C124, C132, C143: 1u; C_0603_1608Metric; MPN GRM188R71C105KA12D
C48: 1p; C_0402_1005Metric; MPN GJM1555C1H1R0BB01D
C49: 3p; C_0402_1005Metric; MPN GJM1555C1H3R0BB01D
C50: 3p9; C_0402_1005Metric; MPN GJM1555C1H3R9BB01D
C51: 5p1; C_0402_1005Metric; MPN GJM1555C1H5R1BB01D
C52: 2p7; C_0402_1005Metric; MPN GJM1555C1H2R7BB01D
C53, C54, C57, C59, C62, C76, C77, C113, C115, C120, C122, C123, C125, C138, C139, C141, C142, C144: 100p; C_0402_1005Metric; MPN GRM1555C1H101JA01D
C55: 8p2; C_0402_1005Metric; MPN GJM1555C1H8R2DB01D
C56, C68, C81, C82, C116, C117, C135, C136: 15p; C_0402_1005Metric; MPN GJM1555C1H150JB01D
C60: 68u; CP_Panasonic_EEF-LR_7.3x4.3mm_3Terminal; MPN EEF-LR0J680R
C61, C63: 1000p; C_0402_1005Metric; MPN GRM1555C1H102JA01D
C64, C65: 22p; C_0402_1005Metric; MPN GJM1555C1H220JB01D
C66: 6p8; C_0402_1005Metric; MPN GJM1555C1H6R8CB01D
C69: 13p; C_0402_1005Metric; MPN GJM1555C1H130JB01D
C70: 3p3; C_0402_1005Metric; MPN GJM1555C1H3R3BB01D
C71: 11p; C_0402_1005Metric; MPN GJM1555C1H110JB01D
C72: 9p1; C_0402_1005Metric; MPN GJM1555C1H9R1DB01D
C73: 1p8; C_0402_1005Metric; MPN GJM1555C1H1R8BB01D
C74: 5p6; C_0402_1005Metric; MPN GJM1555C1H5R6BB01D
C78, C114, C140: 0p6; C_0402_1005Metric; MPN GJM1555C1HR60BB01D
C91, C109, C145: NM; C_0402_1005Metric; MPN N/A; not fitted
C92, C110, C146: 1p2; C_0402_1005Metric; MPN GJM1555C1H1R2BB01D
C96: 1p5; C_0402_1005Metric; MPN GJM1555C1H1R5BB01D
C97, C100: 2u2; C_0603_1608Metric; MPN GRM188R71A225KE15D
C101: 1n; C_0402_1005Metric; MPN GRM1555C1H102JA01D
C102: 10u; C_0805_2012Metric; MPN GRM21BR71A106KE51L
D1, D3: PESD5V0F1BRSF; Nexperia_DSN0603-2_0.6x0.3mm_P0.4mm; MPN PESD5V0F1BRSFYL
D2: RCLAMP2451ZA; D_Semtech_RCLAMP2451ZA_DFN0603_2; MPN RCLAMP2451ZATFT
D15: RClamp2451ZA; D_Semtech_RCLAMP2451ZA_DFN0603_2; MPN RCLAMP2451ZATFT
FB1, FB2, FB3, FB4, FB5, FB6: 600 Ω @ 100 MHz; L_0402_1005Metric; MPN BLM15AG601SN1D
FL2, FL9, FL12: B39321B3722U410; Filter_SAW_Epcos_DCC6C_3x3mm; MPN B39321B3722U410
FL3, FL8, FL11: B39431B3710U410; Filter_SAW_Epcos_DCC6C_3x3mm; MPN B39431B3710U410
FL4, FL7, FL10: B39871B3725U410; Filter_SAW_Epcos_DCC6C_3x3mm; MPN B39871B3725U410
J3: SMA4; SMA_Amphenol_132289_EdgeMount; MPN 132289
J4: SMA1_CH-A_50R; SMA_Amphenol_132289_EdgeMount; MPN 132289
J5: SMA2_CH-B_50R; SMA_Amphenol_132289_EdgeMount; MPN 132289
J6: SMA3_CH-C_50R; SMA_Amphenol_132289_EdgeMount; MPN 132289
J17: SMA5_RESERVED_CC1200; SMA_Amphenol_132289_EdgeMount; MPN 132289; not fitted
J18: SMA6_RESERVED_DUAL_RF; SMA_Amphenol_132289_EdgeMount; MPN 132289; not fitted
L5: 20n; L_0402_1005Metric; MPN LQG15WZ20NH02D
L6: 24n; L_0402_1005Metric; MPN LQG15WZ24NH02D
L7: 15n; L_0402_1005Metric; MPN LQG15HS15NJ02D
L8: 120n; L_0402_1005Metric; MPN LQG15HSR12J02D
L9, L10: 11n; L_0402_1005Metric; MPN LQG15WZ11NH02D
L11: 9n1; L_0402_1005Metric; MPN LQG15HH9N1J02D
L12, L16, L18: 3n3; L_0402_1005Metric; MPN LQG15HS3N3S02D
L13, L17, L19: 6n8; L_0402_1005Metric; MPN LQG15HH6N8J02D
L14, L15, L23: 68n; L_0402_1005Metric; MPN LQG15HS68NJ02D
L20: 5n1; L_0402_1005Metric; MPN LQG15HS5N1S02D
L21: 15u; L_Murata_LQH44PN_4.0x4.0mm; MPN LQH44PN150MPRL
L22: 18n; L_1008_2520Metric; MPN AISC-1008HQ-18NJ-T
L24: 33n; L_0603_1608Metric; MPN LQW18AN33NJ00D
L25: 39n; L_0603_1608Metric; MPN LQW18AN39NJ00D
L26, L30: 12n; L_0603_1608Metric; MPN LQW18AN12NJ00D
L27: 24n; L_0603_1608Metric; MPN LQW18AN24NJ00D
L28: 27n; L_0603_1608Metric; MPN LQW18AN27NJ00D
L29: 9n1; L_0603_1608Metric; MPN LQW18AN9N1D00D
L31: 13n; L_0603_1608Metric; MPN LQW18AN13NJ00D
L32: 3n9; L_0603_1608Metric; MPN LQW18AN3N9C00D
L36: 4n7; L_0402_1005Metric; MPN 744765047A
R32, R33, R35, R38, R42, R53, R55, R56, R58, R59, R61, R63, R64, R65, R66, R67, R68, R69, R70, R71, R72, R73, R74, R141: 10k; R_0603_1608Metric; MPN RC0603FR-0710KL
R34, R39: 1k; R_0603_1608Metric; MPN RC0603FR-071KL
R36: 1k5; R_0603_1608Metric; MPN RC0603FR-071K5L
R37, R45, R49, R50, R60, R62, R139: 0R; R_0603_1608Metric; MPN RC0603JR-070RL
R40, R54, R57: 56k; R_0603_1608Metric; MPN RC0603FR-0756KL
R41: 33k; R_0603_1608Metric; MPN RC0603FR-0733KL
R43: 100k; R_0603_1608Metric; MPN RC0603FR-07100KL
R44, R48: 280R; R_0603_1608Metric; MPN RC0603FR-07280RL
R46: 51R; R_0402_1005Metric; MPN RC0402FR-0751RL
R47: 4R3; R_0402_1005Metric; MPN RC0402FR-074R3L
R51: 0R; R_0805_2012Metric; MPN ERJ-6GEY0R00V
T1, T2, T3: B0310J50100AHF; XFMR_B0310J50100AHF; PARTREV A
U3, U4, U5: CC1101RGPR; QFN50P400X400X100-21N; PARTREV 6-May-2020
U6: SI4463-C2A-GM; QFN-20-1EP_4x4mm_P0.5mm_EP2.6x2.6mm_ThermalVias; MPN SI4463-C2A-GMR
U7, U10, U12: BGS12WN6E6327XTSA1; Infineon_PG-TSNP-6-10_0.7x1.1mm_0.7x1.1mm_P0.4mm; MPN BGS12WN6E6327XTSA1
U8, U9, U18, U19, U20, U21: BGS13SN8E6327XTSA1; Infineon_PG-TSNP-8-1_1.1x1.1mm_P0.4mm; MPN BGS13SN8E6327XTSA1
U14, U17: TQP3M9036; SON50P200X200X95-9N; PARTREV N/A
U15: TSS-13LN+; QFN-12-1EP_3x3mm_P0.51mm_EP1.45x1.45mm; MPN TSS-13LN+
U16: TCA9535PWR; TSSOP-24_4.4x7.8mm_P0.65mm; MPN TCA9535PWR
U22: TQP7M9106; QFN50P400X400X90-25N; PARTREV Rev.D
U27: TPS22918DBVR; SOT-23-6; MPN TPS22918DBVR
U28, U29, U30, U31: BGS12P2L6; Infineon_PG-TSNP-6-10_0.7x1.1mm_0.7x1.1mm_P0.4mm; MPN BGS12P2L6E6327XTSA1
Y1, Y2, Y3: ABM8-26.000MHz-10-B-1-U-T; Crystal_SMD_3225-4Pin_3.2x2.5mm; MPN ABM8-26.000MHz-10-B-1-U-T
Y4: ABM11W-30.0000MHZ-8-D1X-T3; Crystal_SMD_2016-4Pin_2.0x1.6mm; MPN ABM11W-30.0000MHZ-8-D1X-T3

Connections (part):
+3V3: C149.2, FB1.1, FB2.1, FB3.1, FB4.1, FB5.1, R35.2, R61.1, R63.1, R64.1, R65.1, R66.1, U16.24 (VCC); also elsewhere on the board
+5V_SYS: C58.1, C60.1, C61.2, C62.2, C101.2, C102.2, FB6.1, L21.2, R48.2, R51.2, U27.1 (VIN); also elsewhere on the board
/BOOST_5V_EN: R70.1, U16.18 (P15); also elsewhere on the board
/CC1101_A_GDO0: R39.1, U3.6 (GDO(ATEST)); also elsewhere on the board
/CC1101_B_GDO0: U4.6 (GDO(ATEST)); also elsewhere on the board
/CC1101_C_GDO0: U5.6 (GDO(ATEST)); also elsewhere on the board
/CHG_CE_N: U16.17 (P14); also elsewhere on the board
/I2C_SCL: U16.22 (SCL); also elsewhere on the board
/I2C_SDA: U16.23 (SDA); also elsewhere on the board
/REPLAY_OUT: R34.2, R39.2; also elsewhere on the board
/RF_SW_A: R55.2, U10.6 (CTRL), U12.6 (CTRL); also elsewhere on the board
/SPI_MISO: U3.2 (SO(GDO1)), U4.2 (SO(GDO1)), U5.2 (SO(GDO1)), U6.13 (SDO); also elsewhere on the board
/SPI_MOSI: U3.20 (SI), U4.20 (SI), U5.20 (SI), U6.14 (SDI); also elsewhere on the board
/SPI_SCK: U3.1 (SCLK), U4.1 (SCLK), U5.1 (SCLK), U6.12 (SCLK); also elsewhere on the board
/SUB_GHZ_RF/CC1101_A_315_POST_FILT: FL2.5 (OUT), U9.5 (RF1)
/SUB_GHZ_RF/CC1101_A_315_PRE_FILT: FL2.2 (IN), U8.5 (RF1)
/SUB_GHZ_RF/CC1101_A_433_POST_FILT: FL3.5 (OUT), U9.7 (RF2)
/SUB_GHZ_RF/CC1101_A_433_PRE_FILT: FL3.2 (IN), U8.7 (RF2)
/SUB_GHZ_RF/CC1101_A_868_POST_FILT: FL4.5 (OUT), U9.4 (RF3)
/SUB_GHZ_RF/CC1101_A_868_PRE_FILT: FL4.2 (IN), U8.4 (RF3)
/SUB_GHZ_RF/CC1101_A_BALUN_DIFF_N: C115.1, T1.3 (BALANCED_PORT1)
/SUB_GHZ_RF/CC1101_A_BALUN_DIFF_P: C113.1, T1.4 (BALANCED_PORT2)
/SUB_GHZ_RF/CC1101_A_BALUN_OUT: L12.1, T1.1 (UNBALANCED_PORT)
/SUB_GHZ_RF/CC1101_A_BAND_OUT: U9.6 (RFin), U10.5 (RFIN)
/SUB_GHZ_RF/CC1101_A_DCOUPL: C118.2, U3.5 (DCOUPL)
/SUB_GHZ_RF/CC1101_A_LNA_IN: C122.2, U12.3 (RF1)
/SUB_GHZ_RF/CC1101_A_LNA_OUT: C125.1, U10.3 (RF1)
/SUB_GHZ_RF/CC1101_A_LNA_RF_IN_BLOCKED: C122.1, U14.2
/SUB_GHZ_RF/CC1101_A_LNA_RF_OUT_BIASED: C125.2, L14.1, U14.7
/SUB_GHZ_RF/CC1101_A_LNA_SD_NODE: R41.2, R42.1, U14.6
/SUB_GHZ_RF/CC1101_A_MATCH_N1: C109.2, L12.2, L13.1
/SUB_GHZ_RF/CC1101_A_MATCH_N2: C110.1, L13.2, R37.1
/SUB_GHZ_RF/CC1101_A_PA_FEEDBACK_NODE: C99.1, R36.1
/SUB_GHZ_RF/CC1101_A_PA_IN: C96.1, L20.1, U10.1 (RF2)
/SUB_GHZ_RF/CC1101_A_PA_IN_MATCH_N1: C97.2, L20.2
/SUB_GHZ_RF/CC1101_A_PA_OUT: C100.1, U12.1 (RF2)
/SUB_GHZ_RF/CC1101_A_PA_RF_IN_BLOCKED: C97.1, C99.2, U15.3 (RF_IN)
/SUB_GHZ_RF/CC1101_A_PA_RF_OUT_BIASED: C100.2, L21.1, R36.2, U15.7 (RF_OUT)
/SUB_GHZ_RF/CC1101_A_PRE_SAW_IN: R37.2, U8.6 (RFin)
/SUB_GHZ_RF/CC1101_A_RBIAS: R40.1, U3.17 (RBIAS)
/SUB_GHZ_RF/CC1101_A_SMA1_FE: C120.2, U12.5 (RFIN)
/SUB_GHZ_RF/CC1101_A_SMA1_PORT: C120.1, D15.2 (A2), J4.1 (In)
/SUB_GHZ_RF/CC1101_A_TRX_DIFF_N: C114.1, C115.2, U3.13 (RF_N)
/SUB_GHZ_RF/CC1101_A_TRX_DIFF_P: C113.2, C114.2, U3.12 (RF_P)
/SUB_GHZ_RF/CC1101_A_XOSC_Q1: C116.2, U3.8 (XOSC_Q1), Y1.3
/SUB_GHZ_RF/CC1101_A_XOSC_Q2: C117.2, U3.10 (XOSC_Q2), Y1.1
/SUB_GHZ_RF/CC1101_B_315_POST_FILT: FL12.5 (OUT), U19.5 (RF1)
/SUB_GHZ_RF/CC1101_B_315_PRE_FILT: FL12.2 (IN), U20.5 (RF1)
/SUB_GHZ_RF/CC1101_B_433_POST_FILT: FL11.5 (OUT), U19.7 (RF2)
/SUB_GHZ_RF/CC1101_B_433_PRE_FILT: FL11.2 (IN), U20.7 (RF2)
/SUB_GHZ_RF/CC1101_B_868_POST_FILT: FL10.5 (OUT), U19.4 (RF3)
/SUB_GHZ_RF/CC1101_B_868_PRE_FILT: FL10.2 (IN), U20.4 (RF3)
/SUB_GHZ_RF/CC1101_B_BALUN_DIFF_N: C77.2, C78.1, T2.3 (BALANCED_PORT1)
/SUB_GHZ_RF/CC1101_B_BALUN_DIFF_P: C76.2, C78.2, T2.4 (BALANCED_PORT2)
/SUB_GHZ_RF/CC1101_B_BALUN_OUT: L16.1, T2.1 (UNBALANCED_PORT)
/SUB_GHZ_RF/CC1101_B_BAND_OUT: C53.2, U19.6 (RFin)
/SUB_GHZ_RF/CC1101_B_DCOUPL: C83.2, U4.5 (DCOUPL)
/SUB_GHZ_RF/CC1101_B_MATCH_N1: C91.2, L16.2, L17.1
/SUB_GHZ_RF/CC1101_B_MATCH_N2: C92.1, L17.2, R139.1
/SUB_GHZ_RF/CC1101_B_PA2_IN_MATCH_N1: C53.1, C54.2, R46.1
/SUB_GHZ_RF/CC1101_B_PA2_IN_MATCH_N2: C54.1, C55.2, R46.2, R47.1
/SUB_GHZ_RF/CC1101_B_PA2_IREF: L23.2, U22.18 (I_REF)
/SUB_GHZ_RF/CC1101_B_PA2_IREF_BIAS_N1: C57.2, R44.1, R45.2
/SUB_GHZ_RF/CC1101_B_PA2_IREF_BIAS_N2: L23.1, R45.1
/SUB_GHZ_RF/CC1101_B_PA2_OUT_MATCH_N1: C64.2, C66.2, L36.2
/SUB_GHZ_RF/CC1101_B_PA2_RF_IN: C56.2, R47.2, U22.4 (RF_IN), U22.5 (RF_IN__1)
/SUB_GHZ_RF/CC1101_B_PA2_RF_OUT_BIASED: C65.2, L22.2, L36.1, U22.14 (RF_OUT/VCC), U22.15 (RF_OUT/VCC__1), U22.16 (RF_OUT/VCC__2)
/SUB_GHZ_RF/CC1101_B_PA2_VBIAS: C59.2, R50.1, U22.1 (VBIAS)
/SUB_GHZ_RF/CC1101_B_PA2_VBIAS_N1: R48.1, R49.2
/SUB_GHZ_RF/CC1101_B_PA2_VBIAS_N2: R49.1, R50.2
/SUB_GHZ_RF/CC1101_B_PA_RAW_OUT: C64.1, U28.5 (RFIN)
/SUB_GHZ_RF/CC1101_B_POSTPA_315_LPF_IN: C67.1, L24.1, U29.3 (RF1)
/SUB_GHZ_RF/CC1101_B_POSTPA_315_LPF_N1: C68.1, L24.2, L25.1
/SUB_GHZ_RF/CC1101_B_POSTPA_315_LPF_N2: C69.1, L25.2, L26.1
/SUB_GHZ_RF/CC1101_B_POSTPA_315_LPF_OUT: L26.2, U30.3 (RF1)
/SUB_GHZ_RF/CC1101_B_POSTPA_433_LPF_IN: C70.1, L27.1, U28.3 (RF1)
/SUB_GHZ_RF/CC1101_B_POSTPA_433_LPF_N1: C71.1, L27.2, L28.1
/SUB_GHZ_RF/CC1101_B_POSTPA_433_LPF_N2: C72.1, L28.2, L29.1
/SUB_GHZ_RF/CC1101_B_POSTPA_433_LPF_OUT: L29.2, U31.3 (RF1)
/SUB_GHZ_RF/CC1101_B_POSTPA_868_LPF_IN: C73.1, L30.1, U29.1 (RF2)
/SUB_GHZ_RF/CC1101_B_POSTPA_868_LPF_N1: C74.1, L30.2, L31.1
/SUB_GHZ_RF/CC1101_B_POSTPA_868_LPF_N2: C75.1, L31.2, L32.1
/SUB_GHZ_RF/CC1101_B_POSTPA_868_LPF_OUT: L32.2, U30.1 (RF2)
/SUB_GHZ_RF/CC1101_B_POSTPA_SW_IN: U28.1 (RF2), U29.5 (RFIN)
/SUB_GHZ_RF/CC1101_B_POSTPA_SW_OUT: U30.5 (RFIN), U31.1 (RF2)
/SUB_GHZ_RF/CC1101_B_PRE_SAW_IN: R139.2, U20.6 (RFin)
/SUB_GHZ_RF/CC1101_B_RBIAS: R54.1, U4.17 (RBIAS)
/SUB_GHZ_RF/CC1101_B_SMA2_FE: D2.2 (A2), J5.1 (In), U31.5 (RFIN)
/SUB_GHZ_RF/CC1101_B_TRX_DIFF_N: C77.1, U4.13 (RF_N)
/SUB_GHZ_RF/CC1101_B_TRX_DIFF_P: C76.1, U4.12 (RF_P)
/SUB_GHZ_RF/CC1101_B_XOSC_Q1: C81.2, U4.8 (XOSC_Q1), Y2.3
/SUB_GHZ_RF/CC1101_B_XOSC_Q2: C82.2, U4.10 (XOSC_Q2), Y2.1
/SUB_GHZ_RF/CC1101_C_315_POST_FILT: FL9.5 (OUT), U18.5 (RF1)
/SUB_GHZ_RF/CC1101_C_315_PRE_FILT: FL9.2 (IN), U21.5 (RF1)
/SUB_GHZ_RF/CC1101_C_433_POST_FILT: FL8.5 (OUT), U18.7 (RF2)
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

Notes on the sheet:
SMA4 / SI4463 REV-A RF MATCHING: 868 MHz ONLY
U15 — TRANSMIT PA1
U12 + J4 — TX/RX SWITCH AND SMA1
U17 + J6 — RECEIVE LNA AND SMA3
CHANNEL A — CC1101 + LNA + PA1 + SMA1
U28–U31 — SELECTABLE POST-PA LPF BANK
U4 + T2 — CC1101-B CORE AND BALUN
U14 — RECEIVE LNA
U21 + FL7–FL9 + U18 — C-BAND SAW SELECTOR
Firmware note: SAFE DEFAULT: SEL1=0, SEL0=0, PA_EN_B=0. SELECT BAND BEFORE ENABLING PA. DISABLE PA BEFORE CHANGING BAND.
U5 + T3 — CC1101-C CORE AND BALUN
ASSEMBLY / RF LAYOUT Preserve the shown order and footprints of matching and filtering components. Keep RF traces short, controlled at 50 Ω, and free of stubs. Place bypass capacitors and RF chokes directly beside their associated device pins. Use a continuous RF ground plane with dense ground-via 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
SHARED SUB-GHz CONTROL, SAFE STARTUP & RF RAIL FILTERING
SI4463 — TRANSCEIVER + SMA4
REV-A INITIAL VALUES SHOWN. ALTERNATIVES ARE VNA TUNING-KIT PARTS; DO NOT MIX VALUES WITHOUT MEASUREMENT. VERIFY HARMONICS AT OPERATING POWER.
Firmware Notes CHANNEL-A SAFE DEFAULT: SEL1=0, SEL0=0, RF_SW_A=0, LNA_SD_A=1, PA_SD_A=1. TX SEQUENCE: Disable LNA → select band → select TX path → enable PA → start CC1101 transmission. TX STOP: Stop CC1101 → disable PA → wait ≥10 us → select RX path → enable LNA. GDO0/REPLAY_OUT: Never drive REPLA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
U10 — RX/TX BRANCH SELECTOR
U20 + FL10–FL12 + U19 — PRE-PA SAW SELECTOR
FIRMWARE — SI4463 DIRECT/REPLAY MODE If REPLAY_OUT is connected to GPIO0, configure GPIO0 as DIGITAL INPUT. Set MODEM_MOD_TYPE.MOD_SOURCE for direct-mode modulation. Keep the RF output disabled while changing the GPIO or modulation configuration.
FIRMWARE — PA2 FILTER CHANGE Deassert RFX_PA_EN_B before changing the post-PA filter selection. Select one valid filter path, allow the control transaction and switch settling to complete, then enable PA2. Never switch post-PA filters during transmission.
U3 + T1 - CC1101-A CORE, BALUN AND MATCHING
U8 + FL2–FL4 + U9 — A-BAND SAW SELECTOR
U6 — SI4463 CORE, CLOCK AND RF MATCHING
CHANNEL C — CC1101 + LNA + SMA3
FIRMWARE — RF CONTROL STARTUP Keep PA1 and PA2 disabled and both LNAs off at startup. Write safe states to TCA9535 Output Port registers 0x02/0x03 before changing Configuration Port registers 0x06/0x07 from inputs to outputs. Select the required RF path first; enable the selected LNA or PA last. Ex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
U22 + U27 — PA2 POWER, BIAS AND MATCHING
PA matching alternatives are tuning-only. Change values as a complete measured set; do not mix configurations independently.
CHANNEL B — CC1101 + PA2 + SMA2

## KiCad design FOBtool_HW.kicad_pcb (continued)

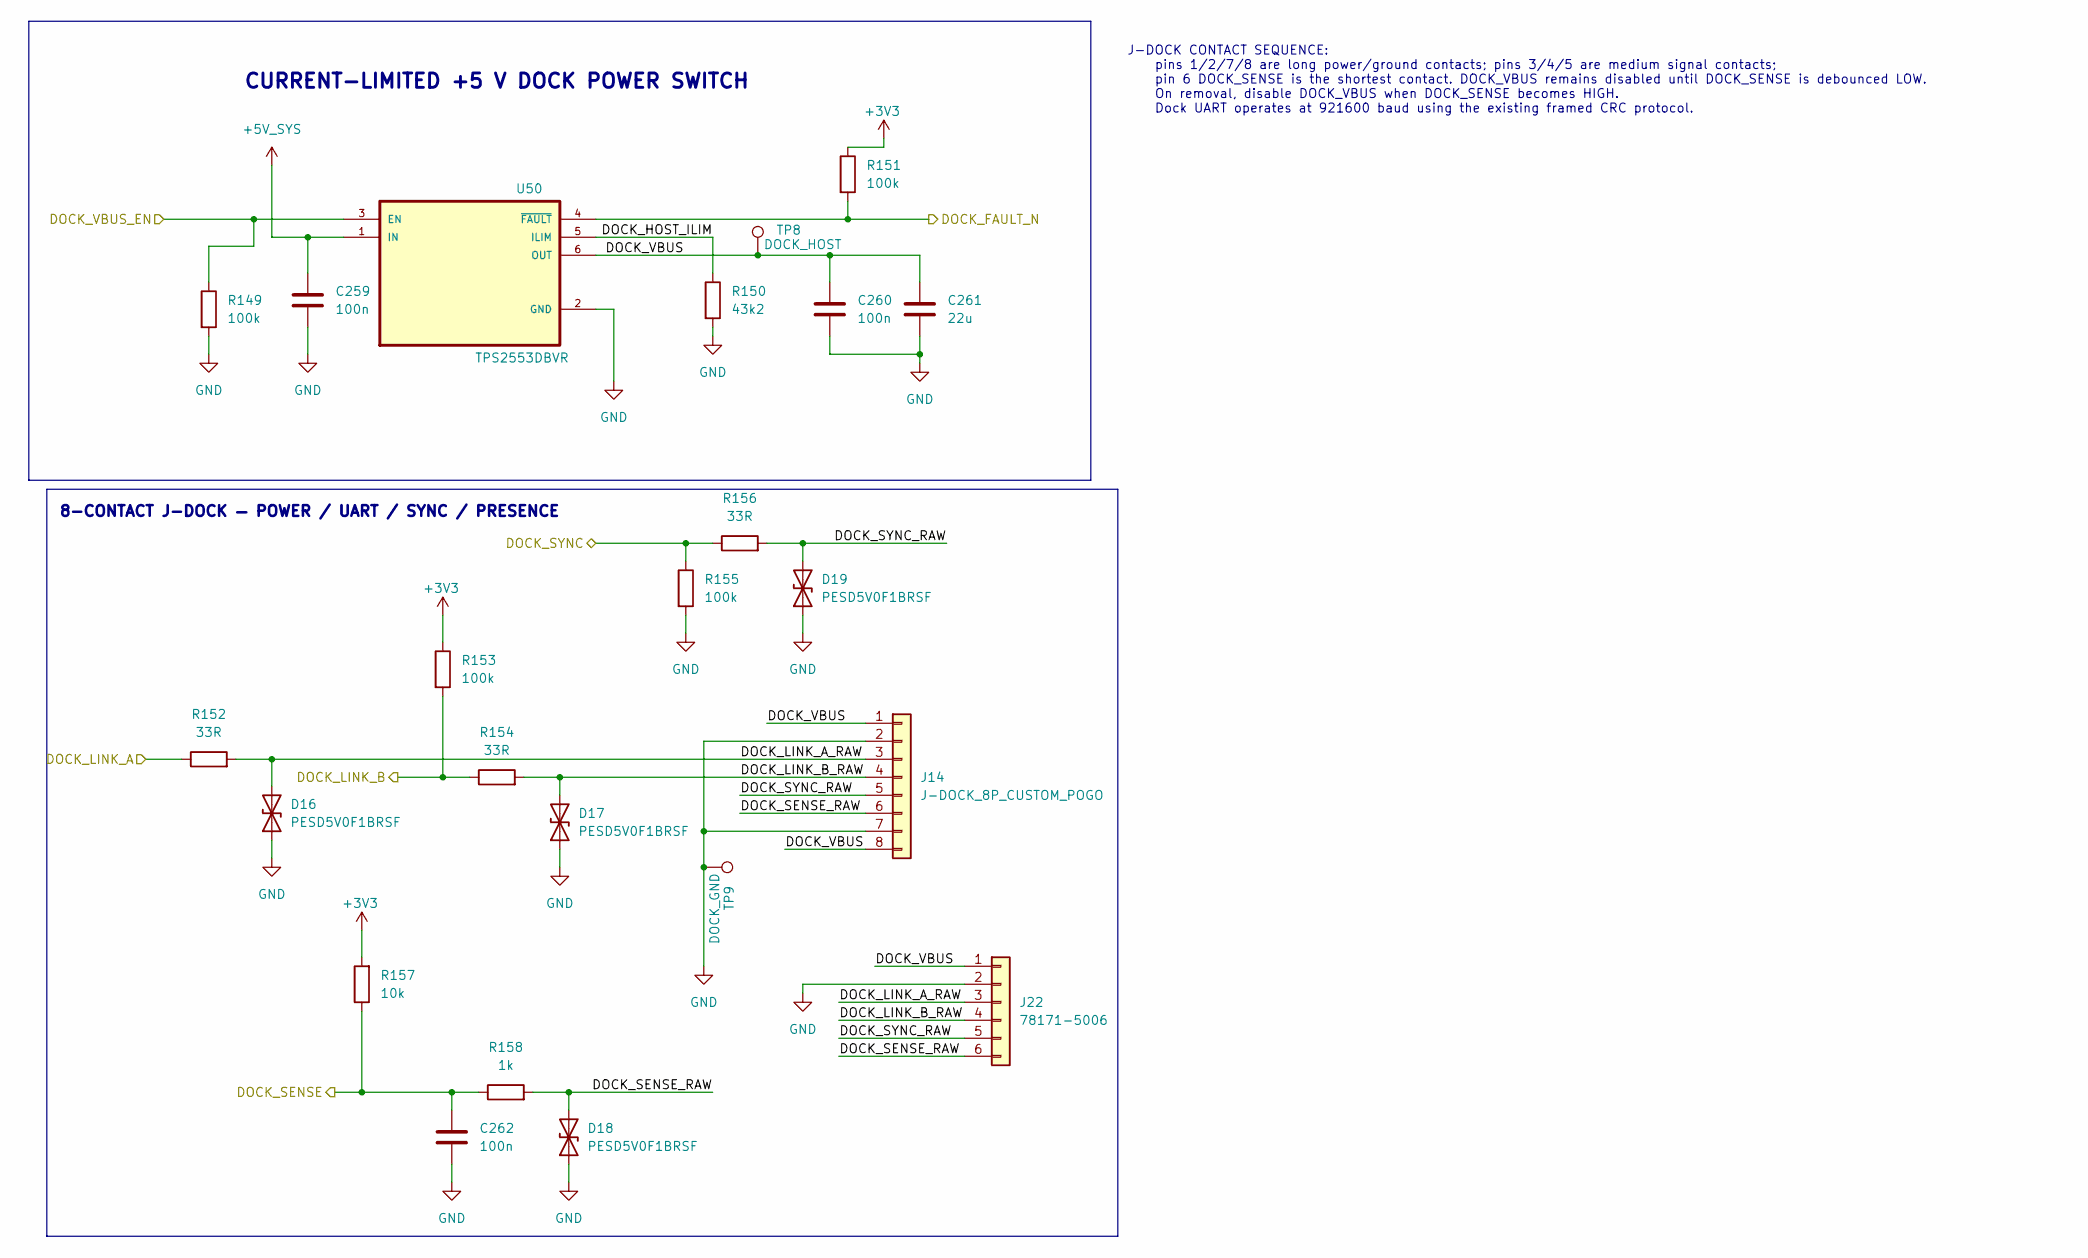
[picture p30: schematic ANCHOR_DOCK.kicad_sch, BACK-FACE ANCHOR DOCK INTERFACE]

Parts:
C259, C260, C262: 100n; C_0603_1608Metric; MPN GRM188R71C104KA01D
C261: 22u; C_1206_3216Metric; MPN GRM31CR71A226KE15L
D16, D17, D18, D19: PESD5V0F1BRSF; Nexperia_DSN0603-2_0.6x0.3mm_P0.4mm; MPN PESD5V0F1BRSFYL
J14: J-DOCK_8P_CUSTOM_POGO; MPN N/A
J22: 78171-5006; Molex_78171-5006_1x06_P1.20mm; MPN 78171-5006
R149, R151, R153, R155: 100k; R_0603_1608Metric; MPN RC0603FR-07100KL
R150: 43k2; R_0603_1608Metric; MPN RC0603FR-0743K2L
R152, R154, R156: 33R; R_0603_1608Metric; MPN RC0603FR-0733RL
R157: 10k; R_0603_1608Metric; MPN RC0603FR-0710KL
R158: 1k; R_0603_1608Metric; MPN RC0603FR-071KL
TP8: DOCK_HOST; TestPoint_Pad_D1.5mm; MPN N/A
TP9: DOCK_GND; TestPoint_Pad_D1.5mm; MPN N/A
U50: TPS2553DBVR; SOT95P280X145-6N; MPN TPS2553DBVR

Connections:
+3V3: R151.1, R153.1, R157.2; also elsewhere on the board
+5V_SYS: C259.2, U50.1 (IN); also elsewhere on the board
/ANCHOR_DOCK/DOCK_HOST_ILIM: R150.1, U50.5 (ILIM)
/ANCHOR_DOCK/DOCK_LINK_A_RAW: D16.2 (A2), J14.3, J22.3, R152.2
/ANCHOR_DOCK/DOCK_LINK_B_RAW: D17.2 (A2), J14.4, J22.4, R154.2
/ANCHOR_DOCK/DOCK_SENSE_RAW: D18.2 (A2), J14.6, J22.6, R158.2
/ANCHOR_DOCK/DOCK_SYNC_RAW: D19.2 (A2), J14.5, J22.5, R156.2
/ANCHOR_DOCK/DOCK_VBUS: C260.2, C261.2, J14.1, J14.8, J22.1, TP8.1 (1_1), U50.6 (OUT)
/DOCK_FAULT_N: R151.2, U50.4 (~FAULT); also elsewhere on the board
/DOCK_LINK_A: R152.1; also elsewhere on the board
/DOCK_LINK_B: R153.2, R154.1; also elsewhere on the board
/DOCK_SENSE: C262.2, R157.1, R158.1; also elsewhere on the board
/DOCK_SYNC: R155.1, R156.1; also elsewhere on the board
/DOCK_VBUS_EN: R149.1, U50.3 (EN); also elsewhere on the board
GND: C259.1, C260.1, C261.1, C262.1, D16.1 (A1), D17.1 (A1), D18.1 (A1), D19.1 (A1), J14.2, J14.7, J22.2, R149.2, R150.2, R155.2, TP9.1 (1_1), U50.2 (GND); also elsewhere on the board

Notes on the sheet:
J-DOCK CONTACT SEQUENCE: pins 1/2/7/8 are long power/ground contacts; pins 3/4/5 are medium signal contacts; pin 6 DOCK_SENSE is the shortest contact. DOCK_VBUS remains disabled until DOCK_SENSE is debounced LOW. On removal, disable DOCK_VBUS when DOCK_SENSE becomes HIGH. Dock UART operates at 9216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
8-CONTACT J-DOCK — POWER / UART / SYNC / PRESENCE
CURRENT-LIMITED +5 V DOCK POWER SWITCH

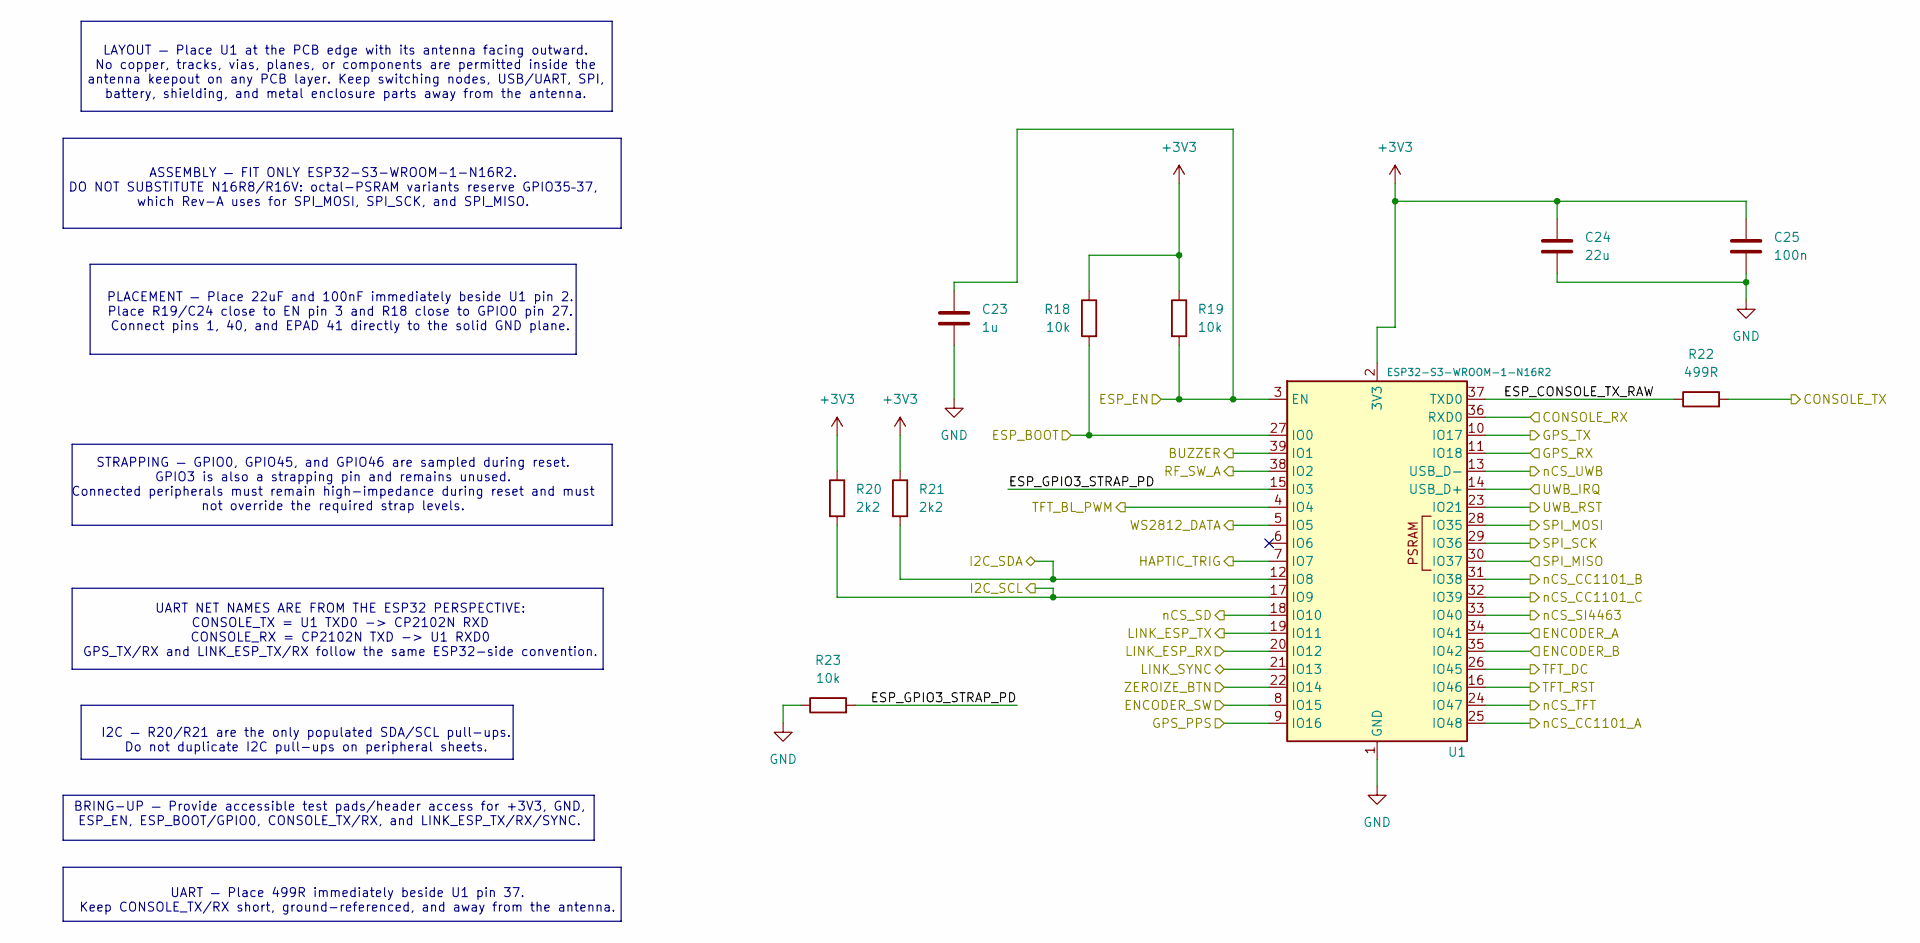
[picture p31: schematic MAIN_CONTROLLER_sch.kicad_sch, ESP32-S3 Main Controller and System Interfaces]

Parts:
C23: 1u; C_0603_1608Metric; MPN GRM188R71C105KA12D
C24: 22u; C_1206_3216Metric; MPN GRM31CR71A226KE15L
C25: 100n; C_0603_1608Metric; MPN GRM188R71C104KA01D
R18, R19, R23: 10k; R_0603_1608Metric; MPN RC0603FR-0710KL
R20, R21: 2k2; R_0603_1608Metric; MPN RC0603FR-072K2L
R22: 499R; R_0603_1608Metric; MPN RC0603FR-07499RL
U1: ESP32-S3-WROOM-1-N16R2; ESP32-S3-WROOM-1; MPN ESP32-S3-WROOM-1-N16R2

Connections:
+3V3: C24.1, C25.1, R18.1, R19.1, R20.1, R21.1, U1.2 (3V3); also elsewhere on the board
/BUZZER: U1.39 (IO1); also elsewhere on the board
/CONSOLE_RX: U1.36 (RXD0); also elsewhere on the board
/CONSOLE_TX: R22.2; also elsewhere on the board
/ENCODER_A: U1.34 (IO41); also elsewhere on the board
/ENCODER_B: U1.35 (IO42); also elsewhere on the board
/ENCODER_SW: U1.8 (IO15); also elsewhere on the board
/ESP_BOOT: R18.2, U1.27 (IO0); also elsewhere on the board
/ESP_EN: C23.1, R19.2, U1.3 (EN); also elsewhere on the board
/GPS_PPS: U1.9 (IO16); also elsewhere on the board
/GPS_RX: U1.11 (IO18); also elsewhere on the board
/GPS_TX: U1.10 (IO17); also elsewhere on the board
/HAPTIC_TRIG: U1.7 (IO7); also elsewhere on the board
/I2C_SCL: R20.2, U1.17 (IO9); also elsewhere on the board
/I2C_SDA: R21.2, U1.12 (IO8); also elsewhere on the board
/LINK_ESP_RX: U1.20 (IO12); also elsewhere on the board
/LINK_ESP_TX: U1.19 (IO11); also elsewhere on the board
/LINK_SYNC: U1.21 (IO13); also elsewhere on the board
/MAIN_CONTROLLER/ESP_CONSOLE_TX_RAW: R22.1, U1.37 (TXD0)
/MAIN_CONTROLLER/ESP_GPIO3_STRAP_PD: R23.2, U1.15 (IO3)
/RF_SW_A: U1.38 (IO2); also elsewhere on the board
/SPI_MISO: U1.30 (IO37); also elsewhere on the board
/SPI_MOSI: U1.28 (IO35); also elsewhere on the board
/SPI_SCK: U1.29 (IO36); also elsewhere on the board
/TFT_BL_PWM: U1.4 (IO4); also elsewhere on the board
/TFT_DC: U1.26 (IO45); also elsewhere on the board
/TFT_RST: U1.16 (IO46); also elsewhere on the board
/UWB_IRQ: U1.14 (USB_D+); also elsewhere on the board
/UWB_RST: U1.23 (IO21); also elsewhere on the board
/WS2812_DATA: U1.5 (IO5); also elsewhere on the board
/ZEROIZE_BTN: U1.22 (IO14); also elsewhere on the board
/nCS_CC1101_A: U1.25 (IO48); also elsewhere on the board
/nCS_CC1101_B: U1.31 (IO38); also elsewhere on the board
/nCS_CC1101_C: U1.32 (IO39); also elsewhere on the board
/nCS_SD: U1.18 (IO10); also elsewhere on the board
/nCS_SI4463: U1.33 (IO40); also elsewhere on the board
/nCS_TFT: U1.24 (IO47); also elsewhere on the board
/nCS_UWB: U1.13 (USB_D-); also elsewhere on the board
GND: C23.2, C24.2, C25.2, R23.1, U1.1 (GND), U1.40 (GND), U1.41 (GND); also elsewhere on the board

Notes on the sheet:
I2C — R20/R21 are the only populated SDA/SCL pull-ups. Do not duplicate I2C pull-ups on peripheral sheets.
ASSEMBLY — FIT ONLY ESP32-S3-WROOM-1-N16R2. DO NOT SUBSTITUTE N16R8/R16V: octal-PSRAM variants reserve GPIO35–37, which Rev-A uses for SPI_MOSI, SPI_SCK, and SPI_MISO.
PLACEMENT — Place 22uF and 100nF immediately beside U1 pin 2. Place R19/C24 close to EN pin 3 and R18 close to GPIO0 pin 27. Connect pins 1, 40, and EPAD 41 directly to the solid GND plane.
STRAPPING — GPIO0, GPIO45, and GPIO46 are sampled during reset. GPIO3 is also a strapping pin and remains unused. Connected peripherals must remain high-impedance during reset and must not override the required strap levels.
BRING-UP — Provide accessible test pads/header access for +3V3, GND, ESP_EN, ESP_BOOT/GPIO0, CONSOLE_TX/RX, and LINK_ESP_TX/RX/SYNC.
UART — Place 499R immediately beside U1 pin 37. Keep CONSOLE_TX/RX short, ground-referenced, and away from the antenna.
UART NET NAMES ARE FROM THE ESP32 PERSPECTIVE: CONSOLE_TX = U1 TXD0 -> CP2102N RXD CONSOLE_RX = CP2102N TXD -> U1 RXD0 GPS_TX/RX and LINK_ESP_TX/RX follow the same ESP32-side convention.
LAYOUT — Place U1 at the PCB edge with its antenna facing outward. No copper, tracks, vias, planes, or components are permitted inside the antenna keepout on any PCB layer. Keep switching nodes, USB/UART, SPI, battery, shielding, and metal enclosure parts away from the antenna.


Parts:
BZ1: AST1109MLTRQ; Buzzer_Mallory_AST1109MLTRQ; MPN AST1109MLTRQ
C161, C162, C166, C167, C168, C169, C171, C176, C177, C178, C180, C182: 100n; C_0603_1608Metric; MPN GRM188R71C104KA01D
C163, C164, C165, C181: 1u; C_0603_1608Metric; MPN GRM188R71C105KA12D
C170, C172: 10u; C_0805_2012Metric; MPN GRM21BR71A106KE51L
C173, C174: 10n; C_0603_1608Metric; MPN GRM188R71C103KA01D
C179: 11mF; CP_Seiko_CPH3225A_3.2x2.5mm; MPN CPH3225A
D7, D11, D12, D13: LED; LED_0603_1608Metric; MPN LTST-C190KRKT
D8, D9, D10: WS2812B; LED_WS2812B_PLCC4_5.0x5.0mm_P3.2mm; MPN WS2812B-B/W
D14: BAV116WS; D_SOD-323; MPN BAV116WS-7
DS1: S020BQ01HN; MPN S020BQ01HN
J10: FH12-12S-0.5SH(55); Hirose_FH12-12S-0.5SH_1x12-1MP_P0.50mm_Horizontal; MPN FH12-12S-0.5SH(55)
J11: SM02B-GHS-TB(LF)(SN); JST_GH_SM02B-GHS-TB_1x02-1MP_P1.25mm_Horizontal; MPN SM02B-GHS-TB(LF)(SN)
J11C1, J11C2: J11 female crimp contact; MPN SSHL-002T-P0.2
J11M1: J11 mating housing, 2-position; MPN GHR-02V-S
J12: Molex 104031-0811; microSD_HC_Molex_104031-0811; MPN 104031-0811
M1: C08-005 LRA, 235 Hz, 1.85 V max; MPN C08-005
Q3: DMN2075U-7; SOT-23; MPN DMN2075U-7
R87, R88: 2k2; R_0603_1608Metric; MPN RC0603FR-072K2L
R89, R92, R93, R94, R95, R96, R97, R98, R99, R100, R110, R111, R112, R113: 10k; R_0603_1608Metric; MPN RC0603FR-0710KL
R90: 220R; R_0603_1608Metric; MPN RC0603FR-07220RL
R91: 330R; R_0603_1608Metric; MPN RC0603FR-07330RL
R101, R102, R103: 100R; R_0603_1608Metric; MPN RC0603FR-07100RL
R104: 100k; R_0603_1608Metric; MPN RC0603FR-07100KL
R105: 33R; R_1206_3216Metric; MPN ERJ-P08J330V
R106, R107, R108, R109: 680R; R_0603_1608Metric; MPN RC0603FR-07680RL
SW1: RotaryEncoder_Switch; RotaryEncoder_Bourns_PEC11R-4215F-S0024; MPN PEC11R-4215F-S0024
SW2, SW3, SW4, SW5, SW8: SW_Push; SW_SPST_PTS810; MPN PTS810SJM250SMTR LFS
U37: SN74AHCT1G125DBVR; SOT-23-5; MPN SN74AHCT1G125DBVR
U38: DRV2605LDGS; TSSOP-10_3x3mm_P0.5mm; MPN DRV2605LDGSR
U39: TCA9534PWR; TSSOP-16_4.4x5mm_P0.65mm; MPN TCA9534PWR
U40: ATECC608C-TCSM; SOIC-8_3.9x4.9mm_P1.27mm; MPN ATECC608C-TCSMS
U42: LTR-303ALS-01; Lite-On_LTR-303ALS-01; MPN LTR-303ALS-01
U43: PCF85263AT/AJ; SOIC-8_3.9x4.9mm_P1.27mm; MPN PCF85263AT/AJ
Y5: ABS07-32.768KHZ-7-T; Crystal_SMD_3215-2Pin_3.2x1.5mm; MPN ABS07-32.768KHZ-7-T

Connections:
+3V3: C161.1, C162.1, C163.1, C164.1, C171.2, C172.2, C178.2, C180.2, C181.2, C182.2, J10.1, J10.9, J12.4 (VDD), R89.1, R92.1, R93.1, R94.1, R95.1, R96.1, R97.1, R98.1, R99.1, R100.2, R102.2, R106.2, R107.2, R108.2, R109.2, R110.2, R111.2, R112.2, R113.2, U38.5 (EN), U38.6 (VDD/NC), U38.10 (VDD), U39.1 (A0), U39.16 (VDD), U40.8 (VCC), U42.1 (VDD), U43.8 (VDD); also elsewhere on the board
+5V_SYS: C166.1, C167.1, C168.1, C169.1, C170.1, D8.1 (VDD), D9.1 (VDD), D10.1 (VDD), J10.12, U37.5 (VCC); also elsewhere on the board
/BUZZER: R90.2; also elsewhere on the board
/ENCODER_A: C173.2, R97.2, SW1.A; also elsewhere on the board
/ENCODER_B: C174.2, R98.2, SW1.B; also elsewhere on the board
/ENCODER_SW: C176.2, R99.2, SW1.S1; also elsewhere on the board
/HAPTIC_TRIG: U38.4 (IN/TRIG); also elsewhere on the board
/HMI/BUZZER_DRV: BZ1.1 (+), R90.1
/HMI/HAPTIC_OUT_N: J11.2, M1.2 (-), U38.9 (OUT-)
/HMI/HAPTIC_OUT_P: J11.1, M1.1 (+), U38.7 (OUT+)
/HMI/HAPTIC_REG: C165.1, U38.1 (REG)
/HMI/HMI_KEY0: R110.1, SW3.1, U39.4 (P0)
/HMI/HMI_KEY0_LED_A: D7.2 (A), R106.1
/HMI/HMI_KEY1: R111.1, SW4.1, U39.5 (P1)
/HMI/HMI_KEY1_LED_A: D11.2 (A), R107.1
/HMI/HMI_KEY2: R112.1, SW5.1, U39.6 (P2)
/HMI/HMI_KEY2_LED_A: D12.2 (A), R108.1
/HMI/HMI_KEY3: R113.1, SW8.1, U39.7 (P3)
/HMI/HMI_KEY3_LED_A: D13.2 (A), R109.1
/HMI/HMI_KEY_LED_SINK: D7.1 (K), D11.1 (K), D12.1 (K), D13.1 (K), U39.9 (P4)
/HMI/RTC_OSCI: U43.1 (OSCI), Y5.2
/HMI/RTC_OSCO: U43.2 (OSCO), Y5.1
/HMI/RTC_VBACKUP: C179.1, D14.1 (K), U43.3 (VBAT)
/HMI/SD_DAT1_PU: J12.8 (DAT1), R96.2
/HMI/SD_DAT2_PU: J12.1 (DAT2), R92.2
/HMI/TFT_BL_GATE: Q3.1 (G), R103.2, R104.2
/HMI/TFT_BL_K: J10.11, R105.2
/HMI/TFT_BL_K_SW: Q3.3 (D), R105.1
/HMI/WS2812_CHAIN_1_2: D8.2 (DOUT), D9.4 (DIN)
/HMI/WS2812_CHAIN_2_3: D9.2 (DOUT), D10.4 (DIN)
/HMI/WS2812_DATA_5V: D8.4 (DIN), R91.2
/HMI/WS2812_DATA_5V_RAW: R91.1, U37.4
/HMI/ZEROIZE_BTN_RAW: C177.2, R100.1, R101.1, SW2.1
/I2C_SCL: U38.2 (SCL), U39.14 (SCL), U40.6 (SCL), U42.4 (SCL), U43.6 (SCL); also elsewhere on the board
/I2C_SDA: U38.3 (SDA), U39.15 (SDA), U40.5 (SDA), U42.6 (SDA), U43.5 (SDA); also elsewhere on the board
/SPI_MISO: J12.7 (DAT0), R95.2; also elsewhere on the board
/SPI_MOSI: J10.4, J12.3 (CMD), R94.2; also elsewhere on the board
/SPI_SCK: J10.6, J12.5 (CLK); also elsewhere on the board
/TFT_BL_PWM: R103.1; also elsewhere on the board
/TFT_DC: J10.5, R87.1; also elsewhere on the board
/TFT_RST: J10.8, R88.1; also elsewhere on the board
/WS2812_DATA: U37.2; also elsewhere on the board
/ZEROIZE_BTN: R101.2; also elsewhere on the board
/nCS_SD: J12.2 (DAT3/CD), R93.2; also elsewhere on the board
/nCS_TFT: J10.7, R89.2; also elsewhere on the board
GND: BZ1.2 (-), C161.2, C162.2, C163.2, C164.2, C165.2, C166.2, C167.2, C168.2, C169.2, C170.2, C171.1, C172.1, C173.1, C174.1, C176.1, C177.1, C178.1, C179.2, C180.1, C181.1, C182.1, D8.3 (VSS), D9.3 (VSS), D10.3 (VSS), J10.3, J10.10, J12.6 (VSS), J12.SH (SHIELD), Q3.2 (S), R87.2, R88.2, R104.1, SW1.C, SW1.S2, SW2.2, SW3.2, SW4.2, SW5.2, SW8.2, U37.1, U37.3 (GND), U38.8 (GND), U39.2 (A1), U39.3 (A2), U39.8 (GND), U40.4 (GND), U42.3 (GND), U43.4 (VSS); also elsewhere on the board
unnamed: D14.2 (A), R102.1

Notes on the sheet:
TFT BACKLIGHT PWM DRIVER
TFT SPI DISPLAY & POWER
AMBIENT LIGHT SENSOR — U42
RTC, CRYSTAL & BACKUP — U41
SECURE ELEMENT — U40
HAPTIC DRIVER & LRA OUTPUT — U38, J11
PIEZO BUZZER — BZ1
WS2812 LEVEL SHIFTER & RGB CHAIN — U37, D8–D10
HMI — DISPLAY, CONTROLS, FEEDBACK, STORAGE & TIMEKEEPING
TACTILE KEYS & RED RING — U39
ENCODER & ZEROIZE INPUT - SW1, SW2
microSD SPI STORAGE — J12

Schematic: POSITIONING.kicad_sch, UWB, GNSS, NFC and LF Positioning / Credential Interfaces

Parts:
AE1, AE2: UWA.01; Antenna_Taoglas_UWA01_3.2x1.6mm; MPN UWA.01
AE3: Antenna_Loop; MPN N/A
AE4: ADFGP.25E.07.0060A; MPN ADFGP.25E.07.0060A
C183: 220n; C_0402_1005Metric; MPN GRM155R71A224KE01D
C184, C187, C192, C195, C196, C203: 100n; C_0402_1005Metric; MPN GRM155R71C104KA88D
C185, C188, C191: 4n7; C_0402_1005Metric; MPN GRM1555C1H472JE01D
C186, C189, C190, C204: 10u; C_0805_2012Metric; MPN GRM21BR71A106KE51L
C193, C211, C212, C221, C222: 22u; C_1206_3216Metric; MPN GRM31CR71A226KE15L
C194, C197, C199, C201, C202: 2p; C_0402_1005Metric; MPN GJM1555C1H2R0BB01D
C198, C200: NM; C_0402_1005Metric; MPN N/A; not fitted
C205: 10n; C_0603_1608Metric; MPN GRM188R71C103KA01D
C206, C207, C209, C210, C219, C220, C232, C237: 100n; C_0603_1608Metric; MPN GRM188R71C104KA01D
C208, C226, C251, C252: 1n; C_0603_1608Metric; MPN GRM1885C1H102JA01D
C213, C223: 47p; C_0603_1608Metric; MPN GRM1885C1H470JA01D; not fitted
C214, C224: 100p; C_0603_1608Metric; MPN GRM1885C1H101JA01D; not fitted
C215, C225: 220p; C_0603_1608Metric; MPN GRM1885C1H221JA01D; not fitted
C216, C218, C227, C229: 220p; C_0603_1608Metric; MPN GRM1885C1H221JA01D
C217, C228: 3n3; C_0603_1608Metric; MPN GRM1885C1H332JA01D
C230: 1u; C_0603_1608Metric; MPN GRM188R71C105KA12D
C231, C238: 4u7; C_0805_2012Metric; MPN GRM21BR71A475KA73L
C233, C234, C255, C256: 2u2; C_0603_1608Metric; MPN GRM188R71A225KE15D
C235, C236: 12p; C_0603_1608Metric; MPN GRM1885C1H120JA01D; not fitted
C239, C245: 330p; C_0603_1608Metric; MPN GRM1885C1H331JA01D
C240, C242, C244, C246, C248, C250: NM; C_0603_1608Metric; MPN N/A; not fitted
C241, C247: 68p; C_0603_1608Metric; MPN GRM1885C1H680JA01D
C243, C249: 100p; C_0603_1608Metric; MPN GRM1885C1H101JA01D
C253, C254: 15p; C_0603_1608Metric; MPN GRM1885C1H150JA01D
C257, C258: DNP; C_0402_1005Metric; MPN N/A; not fitted
FB8: BLM15PX330SN1D; L_0402_1005Metric; MPN BLM15PX330SN1D
J13: U.FL-R-SMT-1(10); U.FL_Hirose_U.FL-R-SMT-1_Vertical; MPN U.FL-R-SMT-1(10)
J15, J16: S2B-PH-SM4-TB(LF)(SN); JST_PH_S2B-PH-SM4-TB_1x02-1MP_P2.00mm_Horizontal; MPN S2B-PH-SM4-TB(LF)(SN)
J19, J20: PHR-2; MPN PHR-2
J21: 781710002; Molex_Pico-EZmate_78171-0002_1x02-1MP_P1.20mm_Vertical; MPN 781710002
L33: 27n; L_0402_1005Metric; MPN LQG15HS27NJ02D
L34, L35: 160n; L_0603_1608Metric; MPN LQW18ANR16G00D
L38, L39: 422u; MPN CUSTOM-LF-COIL-134K2-REV-A
MP1, MP2, MP3, MP4: SPH-002T-P0.5S; MPN SPH-002T-P0.5S
R114, R115, R116, R117: 0R; R_0603_1608Metric; MPN RC0603JR-070RL
R118: 10R; R_0603_1608Metric; MPN RC0603FR-0710RL
R119, R145, R146, R147, R148: 10k; R_0603_1608Metric; MPN RC0603FR-0710KL
R120, R140: 100k; R_0603_1608Metric; MPN RC0603FR-07100KL
R121, R122, R144: 1k; R_0603_1608Metric; MPN RC0603FR-071KL
R123, R128: 220R; R_0603_1608Metric; MPN RC0603FR-07220RL
R124, R127, R129, R132: 4R7; R_0805_2012Metric; MPN ERJ-P06J4R7V
R125, R130: 150k; R_0603_1608Metric; MPN RC0603FR-07150KL
R126, R131: 47k; R_0603_1608Metric; MPN RC0603FR-0747KL
R133, R134: 2k2; R_0603_1608Metric; MPN RC0603FR-072K2L
R135, R136: 2R7; R_0805_2012Metric; MPN ERJ-P06J2R7V
R137, R138: 6k8; R_0603_1608Metric; MPN RC0603FR-076K8L
R142, R143: 0R; R_0201_0603Metric; MPN ERJ-1GN0R00C
U35: DW3220; QFN-40-1EP_5x5mm_P0.4mm_EP3.6x3.6mm; MPN DW3220TR13
U41: MAX-M10N-10B-00; ublox_MAX-M10N; MPN MAX-M10N-10B-00
U44: PN7160B1HN/C100E; HVQFN-40-1EP_6x6mm_P0.5mm_EP4.1x4.1mm_ThermalVias; MPN PN7160B1HN/C100E
U45, U46: TMS3705FDRQ1; SOIC-16_3.9x9.9mm_P1.27mm; MPN TMS3705FDRQ1
U47: SN74AHCT00PWR; SOP65P640X120-14N; MPN SN74AHCT00PWR
U48: SN74LVC157APWR; TSSOP-16_4.4x5mm_P0.65mm; MPN SN74LVC157APWR
Y7: TXC 8Y38472012; Crystal_SMD_2016-4Pin_2.0x1.6mm; MPN 8Y38472012
Y8: NX2016SA 27.12MHz 10pF; Crystal_SMD_2016-4Pin_2.0x1.6mm; MPN NX2016SA-27.120000MHz-EXS00A-CS06346
Y9, Y10: CSTCR4M00G55B-R0; OSC_CSTCR4M00G55B-R0; PARTREV JGC42-8797

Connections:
+3V3: C184.1, C185.1, C186.1, C187.1, C188.1, C189.1, C193.1, C194.1, C195.1, C203.1, C204.1, C206.1, C230.1, FB8.1, R119.2, R145.1, R148.2, U35.23 (VDD2b), U35.26 (VDD3), U35.29 (VDD1), U41.7 (V_IO), U41.8 (VCC), U44.6 (VDD_PAD), U48.16 (VCC); also elsewhere on the board
+5V_SYS: C207.1, C209.1, C210.1, C211.1, C212.1, C219.1, C220.1, C221.1, C222.1, C231.1, C237.1, C238.1, U44.12 (VBAT2), U44.13 (VDD_UP), U44.28 (VBAT), U45.8 (VDDA), U45.9 (VDD), U45.15 (F_SEL), U46.8 (VDDA), U46.9 (VDD), U46.15 (F_SEL), U47.14 (VCC); also elsewhere on the board
/GPS_PPS: U41.4 (TIMEPULSE); also elsewhere on the board
/GPS_RX: U41.2 (TXD); also elsewhere on the board
/GPS_TX: U41.3 (RXD); also elsewhere on the board
/LF_COIL_SEL: R120.1, U47.4 (2A), U47.5 (2B), U47.13 (4B), U48.1 (~A/B); also elsewhere on the board
/LF_SCIO: U48.4 (1Y); also elsewhere on the board
/LF_TXCT: R119.1, U47.1 (1A), U47.2 (1B); also elsewhere on the board
/NFC_DWL_REQ: R146.1, U44.2 (DWL_REQ); also elsewhere on the board
/NFC_IRQ: U44.8 (IRQ); also elsewhere on the board
/NFC_MISO: U44.5 (SPI_MISO); also elsewhere on the board
/NFC_MOSI: U44.3 (SPI_MOSI); also elsewhere on the board
/NFC_SCK: U44.7 (SPI_SCK); also elsewhere on the board
/NFC_VEN: R147.1, U44.10 (VEN); also elsewhere on the board
/POSITIONING/GNSS_ANT_BIAS_FILT: C205.2, L33.1, R118.2
/POSITIONING/GNSS_RF_IN: J13.1 (In), L33.2, U41.11 (RF_IN)
/POSITIONING/GNSS_VCC_RF: R118.1, U41.14 (VCC_RF)
/POSITIONING/LF_A_DRV: C227.1, J15.1, L38.1, R129.2
/POSITIONING/LF_A_RETURN: C223.2, C224.2, C225.2, C228.2, C229.1, R132.1
/POSITIONING/LF_A_TUNE: C223.1, C224.1, C225.1, C228.1, J15.2, L38.2, R131.1
/POSITIONING/LF_B_DRV: C216.1, J16.1, L39.1, R124.2
/POSITIONING/LF_B_RETURN: C213.2, C214.2, C215.2, C217.2, C218.1, R127.1
/POSITIONING/LF_B_TUNE: C213.1, C214.1, C215.1, C217.1, J16.2, L39.2, R126.1
/POSITIONING/LF_SCIO_A_MUX_IN: R128.1, U48.2 (1A)
/POSITIONING/LF_SCIO_B_MUX_IN: R123.1, U48.3 (1B)
/POSITIONING/LF_SEL_N: U47.6 (2Y), U47.10 (3B)
/POSITIONING/LF_TXCT_N: U47.3 (1Y), U47.9 (3A), U47.12 (4A)
/POSITIONING/NFC_ANT_LOOP_N: AE3.2, J21.2, R136.2
/POSITIONING/NFC_ANT_LOOP_P: AE3.1, J21.1, R135.2
/POSITIONING/NFC_CLK_XTAL1: C254.2, U44.30 (NFC_CLK_XTAL1), Y8.1
/POSITIONING/NFC_FIELD_DET_N: C236.1, U44.24 (ANT2)
/POSITIONING/NFC_FIELD_DET_P: C235.1, U44.23 (ANT1)
/POSITIONING/NFC_MATCH_OUT_N: C236.2, C247.2, C248.2, C249.1, C250.1, R136.1, R138.2
/POSITIONING/NFC_MATCH_OUT_P: C235.2, C241.2, C242.2, C243.1, C244.1, R135.1, R137.2
/POSITIONING/NFC_RXN: C251.2, U44.15 (RXN)
/POSITIONING/NFC_RXP: C252.2, U44.16 (RXP)
/POSITIONING/NFC_RX_MATCH_N: C251.1, R134.1, R138.1
/POSITIONING/NFC_RX_MATCH_P: C252.1, R133.1, R137.1
/POSITIONING/NFC_TX1: L34.1, U44.21 (TX1)
/POSITIONING/NFC_TX1_EMC: C239.1, C240.1, C241.1, C242.1, L34.2, R133.2
/POSITIONING/NFC_TX2: L35.1, U44.19 (TX2)
/POSITIONING/NFC_TX2_EMC: C245.1, C246.1, C247.1, C248.1, L35.2, R134.2
/POSITIONING/NFC_VDD: C255.1, C256.1, U44.26 (VDD_A), U44.27 (VDD), U44.31 (VDD_D)
/POSITIONING/NFC_VDD_IN: C233.1, C234.1, U44.14 (VDD_TX), U44.18 (TVDD_IN), U44.22 (TVDD_IN2)
/POSITIONING/NFC_VDD_VMID: C232.1, U44.17 (VDD_VMID)
/POSITIONING/NFC_XTAL2: C253.2, U44.29 (XTAL2), Y8.3
/POSITIONING/TMS_A_ANT1: R129.1, U45.5 (ANT1)
/POSITIONING/TMS_A_ANT2: R132.2, U45.7 (ANT2)
/POSITIONING/TMS_A_OSC1: U45.11 (OSC1), Y9.1
/POSITIONING/TMS_A_OSC2: U45.10 (OSC2), Y9.3
/POSITIONING/TMS_A_SCIO: R128.2, U45.14 (SCIO)
/POSITIONING/TMS_A_SENSE: R130.1, R131.2, U45.1 (SENSE)
/POSITIONING/TMS_A_SFB: R130.2, U45.2 (SFB)
/POSITIONING/TMS_A_TXCT: C226.1, R121.1, U45.16 (TXCT)
/POSITIONING/TMS_B_ANT1: R124.1, U46.5 (ANT1)
/POSITIONING/TMS_B_ANT2: R127.2, U46.7 (ANT2)
/POSITIONING/TMS_B_OSC1: U46.11 (OSC1), Y10.1
/POSITIONING/TMS_B_OSC2: U46.10 (OSC2), Y10.3
/POSITIONING/TMS_B_SCIO: R123.2, U46.14 (SCIO)
/POSITIONING/TMS_B_SENSE: R125.1, R126.2, U46.1 (SENSE)
/POSITIONING/TMS_B_SFB: R125.2, U46.2 (SFB)
/POSITIONING/TMS_B_TXCT: C208.1, R122.1, U46.16 (TXCT)
/POSITIONING/TXCT_A_RAW: R121.2, U47.8 (3Y)
/POSITIONING/TXCT_B_RAW: R122.2, U47.11 (4Y)
/POSITIONING/UWB_ANT1_FTE: AE1.3 (FTE), R142.2
/POSITIONING/UWB_ANT1_PORT: AE1.1 (RF), C198.1, R114.2, R142.1
/POSITIONING/UWB_ANT2_FTE: AE2.3 (FTE), R143.2
/POSITIONING/UWB_ANT2_PORT: AE2.1 (RF), C200.1, R115.2, R143.1
/POSITIONING/UWB_RF1_IC: C197.1, U35.18 (RF1)
/POSITIONING/UWB_RF1_MATCH: C197.2, C257.1, R114.1
/POSITIONING/UWB_RF2_IC: C199.1, U35.13 (RF2)
/POSITIONING/UWB_RF2_MATCH: C199.2, C258.1, R115.1
/POSITIONING/UWB_RST_IC: R144.1, U35.33 (~RST)
/POSITIONING/UWB_VDD2A: C190.1, C191.1, C192.1, FB8.2, U35.28 (VDD2a)
/POSITIONING/UWB_VIO_D: C196.1, U35.38 (VIO_D)
/POSITIONING/UWB_VTX_D: C183.1, U35.27 (VTX_D)
/POSITIONING/UWB_XTI_IC: R116.1, U35.21 (XTI)
/POSITIONING/UWB_XTI_XTAL: C201.1, R116.2, Y7.3
/POSITIONING/UWB_XTO_IC: R117.1, U35.22 (XTO)
/POSITIONING/UWB_XTO_XTAL: C202.1, R117.2, Y7.1
/SPI_MISO: U35.36 (SPIMISO); also elsewhere on the board
/SPI_MOSI: U35.35 (SPIMOSI); also elsewhere on the board
/SPI_SCK: U35.34 (SPICLK); also elsewhere on the board
/UWB_IRQ: R140.2, U35.1 (IRQ); also elsewhere on the board
/UWB_RST: R144.2; also elsewhere on the board
/nCS_NFC: R145.2, U44.1 (SPI_NSS); also elsewhere on the board
/nCS_UWB: R148.1, U35.37 (~SPICS); also elsewhere on the board
GND: C183.2, C184.2, C185.2, C186.2, C187.2, C188.2, C189.2, C190.2, C191.2, C192.2, C193.2, C194.2, C195.2, C196.2, C198.2, C200.2, C201.2, C202.2, C203.2, C204.2, C205.1, C206.2, C207.2, C208.2, C209.2, C210.2, C211.2, C212.2, C216.2, C218.2, C219.2, C220.2, C221.2, C222.2, C226.2, C227.2, C229.2, C230.2, C231.2, C232.2, C233.2, C234.2, C237.2, C238.2, C239.2, C240.2, C243.2, C244.2, C245.2, C246.2, C249.2, C250.2, C253.1, C254.1, C255.2, C256.2, C257.2, C258.2, J13.2 (Ext), R120.2, R140.1, R146.2, R147.2, U35.10 (GND), U35.11 (GND), U35.12 (GND), U35.14 (GND), U35.15 (GND), U35.16 (GND), U35.17 (GND), U35.19 (GND), U35.20 (GND), U35.24 (VSS2), U35.25 (VSS3), U35.30 (VSS1), U35.32 (WAKEUP), U35.39 (VSS), U35.40 (VSS), U35.41 (EP), U41.1 (GND), U41.10 (GND), U41.12 (GND), U44.4 (GND), U44.9 (GND), U44.20 (GND), U44.41 (GND), U45.6 (VSSA), U45.12 (VSSB), U46.6 (VSSA), U46.12 (VSSB), U47.7 (GND), U48.5 (2A), U48.6 (2B), U48.8 (GND), U48.10 (3B), U48.11 (3A), U48.13 (4B), U48.14 (4A), U48.15 (~G), Y7.2 (G), Y7.4 (G), Y8.2 (G), Y8.4 (G), Y9.2, Y10.2; also elsewhere on the board

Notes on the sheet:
LF HDX 134.2 kHz – Dual Orthogonal Coil Front Ends
LF HDX 134.2 kHz — COIL A
OFF-BOARD 134.2 kHz ORTHOGONAL LF COILS
NFC CONTROLLER, MATCHING, FIELD DETECTOR AND LOOP ANTENNA
LF COIL SELECT, TXCT GATING AND SCIO MUX
GNSS RECEIVER, ACTIVE-ANTENNA BIAS AND SMA
External rear NFC antenna assembly—geometry and tuning pending
UWB TRANSCEIVER, CLOCK, DUAL ANTENNAS AND SPI
LF HDX 134.2 kHz — COIL B
UWB PDoA ANTENNA LAYOUT: Place AE1 and AE2 on the same PCB edge with identical orientation. Follow the Taoglas UWA.01 land pattern and maintain its 7.5 × 6.0 mm all-layer copper keepout for each antenna. Route RF1 and RF2 as phase-matched 50 Ω traces with identical transitions and grounding. Target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



Board: 6 copper layers, 64.0 x 112.0 mm, 599 parts (200 on the bottom side), 360 nets.

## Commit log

2026-08-09 finished POWER and MAIN_CONTROLLER Sheets with their docs
    [21-0771A_W201F21_MXM.step, FOBtool_HW.kicad_pcb, FOBtool_HW.kicad_sch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]
2026-08-16 finished SUB_GHZ_RF and RP2350 sheets however still the alue of tuning will be done after simulation
    [21-0771A_W201F21_MXM.step, CC1101RGPR.step, FOBtool_HW.kicad_sch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]
2026-08-22 Finished Last sheets
    [CSTCR4M00G55B-R0.step, FOBtool_HW.kicad_sch, HMI.kicad_sch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]
2026-08-24 finished annotation
    [FOBtool_HW.kicad_sch, HMI.kicad_sch, MAIN_CONTROLLER_sch.kicad_sch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]
2026-09-02 finished ANCHOR_DOCK sheet
    [FOBtool_HW.csv, FOBtool_HW.kicad_sch, HMI.kicad_sch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]
2026-09-04 the schematic is finished
    [ANCHOR_DOCK.kicad_sch, FOBtool_HW.csv, FOBtool_HW.kicad_sch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]
2026-09-05 finished schematic phase
    [ANCHOR_DOCK.kicad_sch, HMI.kicad_sch, POSITIONING.kicad_sch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]
2026-09-07 finished initial board setup in pcb
    [FOBtool_HW.kicad_pcb]
2026-09-10 adding 3d models
    [FOBtool_HW.kicad_pcb, HMI.kicad_sch, PEC11R-4215F-S0024.step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]
2026-09-11 all 3d models finished except t1-t3 and start initial placement
    [AOTA-B201610S3R3-101-T--3DModel-STEP-510211.STEP, BD0826J50200AHF.stp, BGS13SN8E6327XTSA1.stp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]
2026-09-12 grouped the sheets together for placement
    [FOBtool_HW.kicad_pcb]
2026-09-13 adding provisional space
    [1040310811.stp, 1054301103.step, FOBtool_HW.kicad_pcb]
2026-09-15 finished initial placement for rp2350A and esp32
    [1053071203.stp, FOBtool_HW.kicad_pcb, RP2350_COPROCESSOR.kicad_sch]
2026-09-17 finished the rf control group initial placement
    [FOBtool_HW.kicad_pcb, rpi_rp2350a.step]
2026-09-25 changiong bootsel buttom in rp
    [FOBtool_HW.kicad_pcb, MAIN_CONTROLLER_sch.kicad_sch, POWER.kicad_sch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]
2026-10-05 nearly finishing placement phase
    [ANCHOR_DOCK.kicad_sch, FOBtool_HW.kicad_pcb, LTR-303ALS-01_LTO.step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]
2026-10-08 first revision before changing spi
    [FOBtool_HW.kicad_pcb, FOBtool_HW.kicad_sch]
